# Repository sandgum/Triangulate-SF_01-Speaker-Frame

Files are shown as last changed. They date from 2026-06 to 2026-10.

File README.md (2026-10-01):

# Triangulate-SF_01-Speaker-Frame

*AI Use: No AI was used to generate any journal entries at all. AI was only used for electronics review and firmware help*

## Description
The SF_01 is a 24-inch digital picture frame running Android on a Raspberry Pi CM4. The Pi pushes an image to an off-the-shelf IPS monitor from LG through HDMI, and has wireless and USB peripheral support for touch displays, keyboards, and other HIDs.

The SF_01 also has a total 220W RMS speaker system on board, with 6 3.5-inch bass-mid woofers, and 4 0.75-inch tweeterspointing outwards from all four corners.

The frame itself is 3D-printed, with a large stand secured by VESA mount screws driven into the back of the monitor.

The frame has a separate circuit on board for audio playback, with an ESP32-S3 WROOM 2 module at its heart. It decodes a stereo Bluetooth A2DP stream, performs DSP calculations on board, and outputs two different I2S signals (one for the bass-mid woofers, the other for the tweeters).

After going through a DAC, the audio signals are routed through a custom analog multiplexer circuit to all 10 drivers, dynamically switching stereo output between drivers depending on the orientation of the frame.

The ESP32 appears in a device's Bluetooth list as a speaker, and it also runs a GATT server that is controlled by a Bluetooth LE connection via a custom iPhone app. Equalisers and crossovers can be set in the app.

### Woofer Layout

```
(1) ---------- (2)
(3)            (4)
(5) ---------- (6)
```

### Tweeter Layout

```
(1) ---------- (2)
 |              |
(3) ---------- (4)
```

**Landscape Orientation:**
* Left Channel:
* Woofers 1, 3, 5
* Tweeters 1, 3

* Right Channel:
* Woofers 2, 4, 6
* Tweeters 2, 4
  
**Portrait Orientation:**

* Left Channel:
* Woofers 5, 6
* Tweeters 3, 4

* Right Channel:
* Woofers 1, 2
* Tweeters 1, 2

* **Centre Channel: (Average of Right and Left):**
* Woofers 3, 4

## Enclosure Images
Render 1
Render 2
Render 3
Render 4
Render 5

## PCB Schematics

**Raspberry Pi Circuit**



**DAC and Analog Multiplexer Circuit**



**ESP32 WROVER E Circuit**



**Subwoofer Amplifiers**



**Tweeter Amplifiers**



**Environmental and Orientation Sensors**



**Power Circuitry**



## PCB Layout

**Top Layer**



**Inner Layer 1 (GND Plane)**



**Inner Layer 2**



**Bottom Layer**



**3D Model**







## Bill Of Materials

Quantities are **per board**. Prices are LCSC unit pricing at low volume and drop at quantity. Everything except the Compute Module, drivers and panel is sourced from LCSC.

### Board Components

| Designators | Qty | Value | Part Number | Manufacturer | Package | Description | Unit (USD) | Ext. (USD) | LCSC |
|---|---|---|---|---|---|---|---|---|---|
| C1, C4, C5, C7, C9, C14, C17, C19, C23, C26, C28, C31, C34, C37, C38, C39, C42, C43, C45, C47, C50, C53, C72, C74, C80, C81, C106, C109, C135, C138, C163, C166, C185, C186, C189 | 35 | 100nF | CL10B104KB8NNNC | Samsung Electro-Mechanics | 0603 | 100nF ±10% 50V X7R 0603 | 0.0142 | 0.50 | [C1591](https://www.lcsc.com/product-detail/C1591.html) |
| C49, C52, C61, C62, C67, C68, C79, C82, C92, C93, C94, C95, C107, C108, C119, C120, C121, C122, C136, C137, C149, C150, C151, C152, C164, C165, C177, C178, C179, C180 | 30 | 1nF | CL10C102JB8NNNC | Samsung Electro-Mechanics | 0603 | 1nF ±5% 50V C0G 0603 | 0.0076 | 0.23 | [C163508](https://www.lcsc.com/product-detail/C163508.html) |
| C2, C8, C12, C13, C40, C41, C44, C46, C48, C75, C76, C77, C102, C103, C105, C131, C132, C134, C157, C158, C159, C160, C162, C188, C190 | 25 | 1uF | CL10B105KA8NNNC | Samsung Electro-Mechanics | 0603 | 1uF ±10% 25V X7R 0603 | 0.0218 | 0.55 | [C29936](https://www.lcsc.com/product-detail/C29936.html) |
| C24, C63, C64, C69, C70, C96, C97, C98, C99, C123, C124, C125, C126, C153, C154, C155, C156, C181, C182, C183, C184 | 21 | 10nF | GRM1885C1H103JA01D | muRata | 0603 | 10nF ±5% 50V C0G 0603 | 0.0547 | 1.15 | [C85973](https://www.lcsc.com/product-detail/C85973.html) |
| C55, C56, C57, C58, C84, C85, C86, C87, C111, C112, C113, C114, C141, C142, C143, C144, C169, C170, C171, C172 | 20 | 220nF | CL10B224KB8NNNC | Samsung Electro-Mechanics | 0603 | 220nF ±10% 50V X7R 0603 | 0.0121 | 0.24 | [C64705](https://www.lcsc.com/product-detail/C64705.html) |
| C59, C60, C65, C66, C88, C89, C90, C91, C115, C116, C117, C118, C145, C146, C147, C148, C173, C174, C175, C176 | 20 | 680nF | CGA3E3X5R1H684KT0Y0N | TDK | 0603 | 680nF ±10% 50V X5R 0603 | 0.1052 | 2.10 | [C694504](https://www.lcsc.com/product-detail/C694504.html) |
| C10, C11, C35, C36, C71 | 5 | 2.2nF | CL10B222KB8NNNC | Samsung Electro-Mechanics | 0603 | 2.2nF ±10% 50V X7R 0603 | 0.0061 | 0.03 | [C16033](https://www.lcsc.com/product-detail/C16033.html) |
| C20, C21, C29, C30 | 4 | 2.2uF | CL10A225KA8NNNC | Samsung Electro-Mechanics | 0603 | 2.2uF ±10% 25V X5R 0603 | 0.0231 | 0.09 | [C57895](https://www.lcsc.com/product-detail/C57895.html) |
| C6 | 1 | 22uF | CL10A226MP8NUNE | Samsung Electro-Mechanics | 0603 | 22uF ±20% 10V X5R 0603 | 0.0825 | 0.08 | [C86295](https://www.lcsc.com/product-detail/C86295.html) |
| C187 | 1 | 6.8pF | CC0603BRNPO9BN6R8 | YAGEO | 0603 | 6.8pF 50V NP0 0603 | 0.0038 | 0.00 | [C519114](https://www.lcsc.com/product-detail/C519114.html) |
| C130 | 1 | 7.5nF | GRM1885C1H752JA01D | muRata | 0603 | 7.5nF ±5% 50V C0G 0603 | 0.0156 | 0.02 | [C907758](https://www.lcsc.com/product-detail/C907758.html) |
| C100, C101, C129 | 3 | 10uF/50V | GRM32ER71H106KA12L | muRata | 1210 | 10uF ±10% 50V X7R 1210 | 0.3758 | 1.13 | [C77102](https://www.lcsc.com/product-detail/C77102.html) |
| C191, C192 | 2 | 47uF | GRM32ER61C476KE15L | muRata | 1210 | 47uF ±10% 16V X5R 1210 | 0.4273 | 0.85 | [C77101](https://www.lcsc.com/product-detail/C77101.html) |
| C51, C54, C78, C83, C104, C110, C133, C139, C161, C167 | 10 | 220uF | RVT35V220M6X8 | JIERR | SMD,D6.3xL7.7mm | 220uF ±20% 35V aluminium electrolytic 105C | 0.1003 | 1.00 | [C47023115](https://www.lcsc.com/product-detail/C47023115.html) |
| C3 | 1 | 10uF | EEEFTH100UAR | Panasonic | SMD,D4xL5.8mm | 10uF ±20% 50V aluminium electrolytic 105C | 0.1811 | 0.18 | [C242129](https://www.lcsc.com/product-detail/C242129.html) |
| C15, C16, C18, C22, C25, C27, C32, C33 | 8 | 10uF | EEEFTH100UAR | Panasonic | SMD,D4xL5.8mm | 10uF ±20% 50V aluminium electrolytic 105C | 0.1811 | 1.45 | [C242129](https://www.lcsc.com/product-detail/C242129.html) |
| C73 | 1 | 22uF | EEEFN1E220R | Panasonic | SMD,D4xL5.8mm | 22uF ±20% 25V aluminium electrolytic 105C | 0.1796 | 0.18 | [C494818](https://www.lcsc.com/product-detail/C494818.html) |
| R16, R18, R20, R26, R27, R30, R35, R36, R39, R45, R46, R50, R55, R56, R60, R76 | 16 | 100K | FRC0603J104TS | FOJAN | 0603 | 100kOhm ±5% 100mW 0603 | 0.0019 | 0.03 | [C2907088](https://www.lcsc.com/product-detail/C2907088.html) |
| R4, R12, R67, R68, R69, R70, R71, R77 | 8 | 10K | CRCW060310K0FKEA | VISHAY | 0603 | 10kOhm ±1% 100mW 0603 | 0.0057 | 0.05 | [C844918](https://www.lcsc.com/product-detail/C844918.html) |
| R21, R22, R23, R24, R31, R32, R33, R34, R40, R41, R42, R43, R51, R52, R53, R54, R61, R62, R63, R64 | 20 | 3.3R | FRC0805J3R3TS | FOJAN | 0805 | 3.3Ohm ±5% 125mW 0805 | 0.0037 | 0.07 | [C2907317](https://www.lcsc.com/product-detail/C2907317.html) |
| R15 | 1 | 3.3R | FRC0603F3R30TS | FOJAN | 0603 | 3.3Ohm ±1% 100mW 0603 | 0.0025 | 0.00 | [C2930016](https://www.lcsc.com/product-detail/C2930016.html) |
| R25, R44, R49, R59 | 4 | 100R | FRC0603F1000TS | FOJAN | 0603 | 100Ohm ±1% 100mW 0603 | 0.0021 | 0.01 | [C2906981](https://www.lcsc.com/product-detail/C2906981.html) |
| R28, R37, R47, R57 | 4 | 47K | FRC0603F4702TS | FOJAN | 0603 | 47kOhm ±1% 100mW 0603 | 0.0023 | 0.01 | [C2907042](https://www.lcsc.com/product-detail/C2907042.html) |
| R29, R38, R48, R58 | 4 | 75K | FRC0603F7502TS | FOJAN | 0603 | 75kOhm ±1% 100mW 0603 | 0.0025 | 0.01 | [C2907067](https://www.lcsc.com/product-detail/C2907067.html) |
| R5, R6, R72, R73 | 4 | 1K | FRC0603F1001TS | FOJAN | 0603 | 1kOhm ±1% 100mW 0603 | 0.0014 | 0.01 | [C2907002](https://www.lcsc.com/product-detail/C2907002.html) |
| R1, R2 | 2 | 2.2K | FRC0603F2201TS | FOJAN | 0603 | 2.2kOhm ±1% 100mW 0603 | 0.0023 | 0.00 | [C2907005](https://www.lcsc.com/product-detail/C2907005.html) |
| R3, R65 | 2 | 5.1K | FRC0603F5101TS | FOJAN | 0603 | 5.1kOhm ±1% 100mW 0603 | 0.0023 | 0.00 | [C2907044](https://www.lcsc.com/product-detail/C2907044.html) |
| R7, R17 | 2 | 56K | 0603WAF5602T5E | UNI-ROYAL | 0603 | 56kOhm ±1% 100mW 0603 | 0.0081 | 0.02 | [C23206](https://www.lcsc.com/product-detail/C23206.html) |
| Q1 | 1 | BSS138 | BSS138 | Shikues | SOT-23 | N-channel logic-level MOSFET 50V 0.2A | 0.0191 | 0.02 | [C112239](https://www.lcsc.com/product-detail/C112239.html) |
| R19 | 1 | 20K | FRC0603F2002TS | FOJAN | 0603 | 20kOhm ±1% 100mW 0603 | 0.0020 | 0.00 | [C2907011](https://www.lcsc.com/product-detail/C2907011.html) |
| R8, R9, R10, R11 | 4 | 470R | FRC0603F4700TS | FOJAN | 0603 | 470Ohm ±1% 100mW 0603 | 0.0027 | 0.01 | [C2907041](https://www.lcsc.com/product-detail/C2907041.html) |
| R14, R78 | 2 | 220R | 0603WAF2200T5E | UNI-ROYAL | 0603 | 220Ohm ±1% 100mW 0603 | 0.0010 | 0.00 | [C22962](https://www.lcsc.com/product-detail/C22962.html) |
| R66 | 1 | 205K | FRC0603F2053TS | FOJAN | 0603 | 205kOhm ±1% 100mW 0603 | 0.0008 | 0.00 | [C5126104](https://www.lcsc.com/product-detail/C5126104.html) |
| R75 | 1 | 60.4K | 0603WAF6042T5E | UNI-ROYAL | 0603 | 60.4kOhm ±1% 100mW 0603 | 0.0009 | 0.00 | [C23089](https://www.lcsc.com/product-detail/C23089.html) |
| R74 | 1 | 11.5K | FRC0603F1152TS | FOJAN | 0603 | 11.5kOhm ±1% 100mW 0603 | 0.0009 | 0.00 | [C2930057](https://www.lcsc.com/product-detail/C2930057.html) |
| R13 | 1 | 10.7K | FRC0603F1072TS | FOJAN | 0603 | 10.7kOhm ±1% 100mW 0603 | 0.0025 | 0.00 | [C5153968](https://www.lcsc.com/product-detail/C5153968.html) |
| L1, L2, L3, L4, L5, L6, L7, L8, L9, L10, L11, L12 | 12 | 10uH/10A | SMDRH104R-100MT | cjiang | SMD,10.4x10.3mm | 10uH ±20% 3.8A rated / 5.6A sat / 35mOhm | 0.1916 | 2.30 | [C9935](https://www.lcsc.com/product-detail/C9935.html) |
| L13, L14, L15, L16, L17, L18, L19, L20 | 8 | 10uH/3A | FHD4020S-100MT | cjiang | SMD,4x4mm | 10uH ±20% 2.35A rated / 3.5A sat / 190mOhm | 0.1102 | 0.88 | [C602032](https://www.lcsc.com/product-detail/C602032.html) |
| L21 | 1 | 6.8uH/6.6A | AAPS0650M6R8F | Coilank | SMD,6.6x6.4mm | 6.8uH ±20% 6.6A rated / 7A sat / 25.4mOhm molded | 0.9665 | 0.97 | [C49261484](https://www.lcsc.com/product-detail/C49261484.html) |
| U4 | 1 | TPS54540DDAR | TPS54540DDAR | Texas Instruments | SOIC-8-EP | 42V 5A step-down converter | 1.4638 | 1.46 | [C95286](https://www.lcsc.com/product-detail/C95286.html) |
| CR2 | 1 | STPS30H100DJF-TR | STPS30H100DJF-TR | ST | PowerFLAT5x6-8 | 100V 30A Schottky | 1.3985 | 1.40 | [C2969851](https://www.lcsc.com/product-detail/C2969851.html) |
| U10 | 1 | LP5907MFX-4.5 | LP5907MFX-4.5/NOPB | Texas Instruments | SOT-23-5 | 4.5V LDO | 0.5581 | 0.56 | [C529554](https://www.lcsc.com/product-detail/C529554.html) |
| U11 | 1 | LP5907MFX-3.3 | LP5907MFX-3.3 | Texas Instruments | SOT-23-5 | 3.3V LDO | 0.1343 | 0.13 | [C23380874](https://www.lcsc.com/product-detail/C23380874.html) |
| U17, U18, U19 | 3 | TPA3116D2DAD | TPA3116D2DADR | Texas Instruments | HTSSOP-32-6.1mm | 2x50W@4ohm Class D amplifier | 1.0619 | 3.19 | [C50144](https://www.lcsc.com/product-detail/C50144.html) |
| U20, U21 | 2 | TPA3130D2DAPR | TPA3130D2DAPR | Texas Instruments | HTSSOP-32-EP-6.1mm | 2x15W@8ohm Class D amplifier | 0.6314 | 1.26 | [C95206](https://www.lcsc.com/product-detail/C95206.html) |
| U12, U13, U15, U16, U24, U25, U26 | 7 | TS5A3159AYZPR | TS5A3159AYZPR | Texas Instruments | WCSP-6(1.4x0.9) | SPDT analog switch | 0.3971 | 2.78 | [C2651909](https://www.lcsc.com/product-detail/C2651909.html) |
| U5, U14 | 2 | PCM5102A | PCM5102APWR | Texas Instruments | TSSOP-20 | I2S stereo DAC | 1.3577 | 2.72 | [C107671](https://www.lcsc.com/product-detail/C107671.html) |
| U27 | 1 | TPS2041B | TPS2041BDBVR | Texas Instruments | SOT-23-5 | 500mA current-limited power switch | 0.3173 | 0.32 | [C51386](https://www.lcsc.com/product-detail/C51386.html) |
| U6 | 1 | RT9742SNGV | RT9742SNGV | RICHTEK | SOT-23-3 | 500mA high-side switch | 0.4386 | 0.44 | [C3235509](https://www.lcsc.com/product-detail/C3235509.html) |
| U9 | 1 | 74LVC1G07 | SN74LVC1G07DBVR | Texas Instruments | SOT-23-5 | Open-drain buffer 1.65-5.5V | 0.1109 | 0.11 | [C7829](https://www.lcsc.com/product-detail/C7829.html) |
| TP1–TP21, TP23–TP25 | 24 | TestPoint | — | — | 3.0x3.0mm pad / D2.5mm pad / D2.0mm plated hole | Bare copper - nothing to buy. 3 top, 4 plated through-hole, 17 on the bottom layer | 0.0000 | 0.00 | — |
| U28 | 1 | ESP32-WROVER-E-N16R8 | ESP32-WROVER-E-N16R8 | ESPRESSIF | SMD,31.4x18mm | WiFi/BT module 16MB flash 8MB PSRAM | 5.7127 | 5.71 | [C529589](https://www.lcsc.com/product-detail/C529589.html) |
| U22 | 1 | MPU-6050 | MPU-6050 | TDK InvenSense | QFN-24-EP(4x4) | 6-axis IMU | 6.3857 | 6.39 | [C24112](https://www.lcsc.com/product-detail/C24112.html) |
| U23 | 1 | BME680 | BME680 | Bosch | LGA-8 | Environmental sensor | 8.0629 | 8.06 | [C125972](https://www.lcsc.com/product-detail/C125972.html) |
| U2, U3, U7 | 3 | TPD4E02B04DQA | TPD4E02B04DQAR | Texas Instruments | USON-10(1x2.5) | 4-channel ESD array | 0.0996 | 0.30 | [C106794](https://www.lcsc.com/product-detail/C106794.html) |
| CR1 | 1 | SP3010-04UTG | SP3010-04UTG | Littelfuse | UFDFN-10(1x2.5) | 4-channel TVS array | 0.2544 | 0.25 | [C126837](https://www.lcsc.com/product-detail/C126837.html) |
| D1 | 1 | SMAJ26A | SMAJ26A | GOODWORK | DO-214AC(SMA) | 26V unidirectional TVS 400W Vbr 28.9V Vc 42.1V@9.5A | 0.0333 | 0.03 | [C2848697](https://www.lcsc.com/product-detail/C2848697.html) |
| D2, D5, D6, D7 | 4 | WS2812B | WS2812B-V6 | Worldsemi | SMD5050-4P | Addressable RGB LED | 0.1009 | 0.40 | [C52917433](https://www.lcsc.com/product-detail/C52917433.html) |
| D3, D4 | 2 | LED | YLED0603B | YONGYUTAI | 0603 | Blue LED 2.6-3.2V | 0.0058 | 0.01 | [C19171394](https://www.lcsc.com/product-detail/C19171394.html) |
| J1 | 1 | SS-53200-001 | HDMI 19PIN 043 | SHOU HAN | SMD | HDMI-A receptacle right angle | 0.1365 | 0.14 | [C2858275](https://www.lcsc.com/product-detail/C2858275.html) |
| J5, J6, J7, J8, J9, J10, J11, J12, J13, J14 | 10 | Speaker out | S2B-XH-A(LF)(SN) | JST | TH Right Angle P=2.5mm | 2-position 2.5mm header 3A | 0.0615 | 0.62 | [C157931](https://www.lcsc.com/product-detail/C157931.html) |
| J15 | 1 | USB_C_Receptacle_USB2.0_16P | TYPE-C 16PIN 2MD(073) | SHOU HAN | SMD | USB-C receptacle 16P | 0.0707 | 0.07 | [C2765186](https://www.lcsc.com/product-detail/C2765186.html) |
| J2 | 1 | Barrel_Jack | RAPC10U | Switchcraft | - | Power barrel jack 1.93/5.75mm | 17.0122 | 17.01 | [C3095802](https://www.lcsc.com/product-detail/C3095802.html) |
| J3 | 1 | UART | PZ254V-11-04P | XFCN | TH P=2.54mm | 4-position 2.54mm header | 0.0254 | 0.03 | [C2691448](https://www.lcsc.com/product-detail/C2691448.html) |
| SW1 | 1 | POWER | KSC931JLFS | C&K | SMD-4P,6.2x6.2mm | Tactile switch SPST IP67 J-lead | 2.0503 | 2.05 | [C221769](https://www.lcsc.com/product-detail/C221769.html) |
| SW2, SW3, SW4 | 3 | Tactile | KMR211GLFS | C&K | SMD | Tactile switch SPST-NO | 0.6377 | 1.91 | [C221675](https://www.lcsc.com/product-detail/C221675.html) |
| SW6 | 1 | SW_DPDT_x2 | JS202011JAQN | C&K | SMD | Slide switch DPDT 300mA@6V, right-angle | 1.2032 | 1.20 | [C221664](https://www.lcsc.com/product-detail/C221664.html) |
| U1 | 1 | CM4102008 | CM4102008 | Raspberry Pi | - | Compute Module 4 | 124.9100 | 124.91 | — |

**Board subtotal: $197.63 per board**

### Off-Board / Mechanical

| Qty | Item | Part Number | Manufacturer | Description | Unit (USD) | Ext. (USD) |
|---|---|---|---|---|---|---|
| 6 | Woofer | PLS-P830985 | Peerless by Tymphany | 3.95ohm full-range 30W driver | 18.74 | 112.45 |
| 4 | Tweeter | ND16FA-6 | Dayton Audio | Neodymium dome tweeter | 12.47 | 49.88 |
| 1 | Display | 24U411A-B | LG | 23.8in IPS FHD 120Hz panel | 74.53 | 74.53 |

**Off-board subtotal: $236.86**

### Items Needing Attention

| Designators | Status | Note |
|---|---|---|
| C100, C101, C129 | CHANGED + FOOTPRINT | Was 10uF/25V 0603 on the 24V rail. 10uF/50V does not exist in 0603 - the footprint has to go to 1210 |
| C191, C192 | CHANGED + FOOTPRINT | TPS54540 output bulk. 47uF does not exist in 0603 or 0805 at >=16V - footprint has to go to 1210 |
| L21 | CHANGED - NO PCB CHANGE | Now AAPS0650M6R8F (Coilank), 6.6A rated / 7A sat / 25.4mOhm. Replaced VLS6045EX-6R8M which saturated at full load (4.7A sat vs a 4.72A peak). 48% saturation margin now, and half the DCR. Body 6.6x6.4mm fits the existing 7.50x6.80mm courtyard so the land pattern is unchanged |
| CR2, R8-R11, R13, SW1, SW6 | CHANGED - RESTOCK | All five originals hit 0 stock on LCSC. CR2 -> STPS30H100DJF-TR (C2969851, same PowerFLAT 5x6 family, 100V, lowest Vf of the in-stock options). R8-R11 -> FRC0603F4700TS (C2907041). R13 -> FRC0603F1072TS (C5153968, only 1k in stock; plain 10K works as a fallback). SW1 -> KSC931JLFS (C221769, only 18 in stock). SW6 -> JS202011JAQN (C221664) which is RIGHT-ANGLE where the original was VERTICAL, so verify the land pattern |
| U8 | DELETED | U8 buffered CM4 RUN_PG into the GLOBAL_EN button, forming a feedback loop that repeatedly power-cycled the module. Removed. SW1 now goes straight to GPIO3/GND as a soft power button (`dtoverlay=gpio-shutdown`), with R77 as pull-up and C74 as debounce |
| U9 | CHANGED - FOOTPRINT | Footprint is SOT-23-5, same as U10/U11/U27; symbol pin numbering unchanged (1=NC 2=A 3=GND 4=Y 5=VCC). MUST stay LVC. Budget alt C7394020 (UMW) |
| R77, R78, C74, TP1, TP2 | NEW | Power-button circuit. R77 10K pulls GPIO3 to 3V3, C74 100nF debounces it, R78 220R feeds TP1 for CM4 reset (220R is the value the CM4 datasheet specifies), TP2 exposes GLOBAL_EN for a hard force-off |
| D2, D5, D6, D7 | KEEP - RAIL ISSUE | Datasheet minimum VDD is 3.5V and these sit on the 3.3V rail. See review B5 |
| J1 | VERIFY | Footprint is drawn for the Stewart SS-53200-001 but the sourced part is SHOU HAN - confirm the land patterns match before ordering |
| J5, J6, J7, J8, J9, J10, J11, J12, J13, J14 | KEEP - MARGINAL | Rated 3A but a 50W/4ohm woofer channel draws 3.5A RMS. See review H9 |
| J2 | KEEP - VERIFY RATING | Confirm its current rating against the ~8A this board can draw at full output |
| U1 | NOT ON LCSC | Source from an approved Raspberry Pi reseller. Schematic says CM4102008 but the old BOM said CM4102016 - pick one |

## Total: $434.49 USD per complete unit

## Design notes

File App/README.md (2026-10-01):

# SF01Control — iOS EQ remote

SwiftUI app that tunes the SF_01 speaker's DSP over BLE while music streams to
it over A2DP.

* `SF01Protocol.swift` — wire format, mirroring `Firmware/.../main/ble_ctl.h`
* `SpeakerController.swift` — CoreBluetooth client, auto-reconnect, write coalescing
* `ContentView.swift` / `BandEditor.swift` — the UI

## Build and install

```bash
export DEVELOPER_DIR=/Applications/Xcode-beta.app/Contents/Developer
xcodebuild -project App/SF01Control.xcodeproj -scheme SF01Control \
  -configuration Debug -destination 'id=<device-udid>' \
  -allowProvisioningUpdates build
xcrun devicectl device install app --device <device-udid> <path-to>/SF01Control.app
```

Signing is automatic against team `LAFKSHQ45W`.

**First install needs a one-time trust step on the phone:** Settings → General →
VPN & Device Management → Developer App → Trust. On a free Apple developer
account the provisioning profile also expires after 7 days, after which the app
must be rebuilt and reinstalled.

## Equaliser screen

`EQScreen` shows a log-frequency response plot with a draggable handle per
active band — sideways for frequency, up and down for gain — over a scrollable
row of gain knobs and a Freq/Q/Gain trio for the selected band.

`EQMath.swift` re-implements the same RBJ cookbook filters the firmware runs in
`dsp.c`, so the drawn curve *is* the response you hear rather than an
approximation of it. The plot also overlays the Linkwitz-Riley crossover
branches as dashed lines, so EQ moves can be read against where the two ways
actually split.

Knobs track a **vertical drag** rather than true circular motion: on a phone
your finger covers the knob, and chasing an angle under your own thumb is
miserable. Frequency knobs ride a log scale so they feel even across the band.

## Design notes

**Write coalescing.** A slider drag emits values far faster than BLE should
carry them, and the radio is shared with the audio link. Commands are coalesced
per control and flushed on a 50 ms tick, so a drag costs at most 20 writes per
second and the final value always lands.

**Echo guard.** The speaker notifies every change back. During a drag those
echoes arrive a beat late and would yank the knob backwards, so remote updates
are ignored for 500 ms after a local write. Changes made elsewhere — the UART
shell, AVRCP volume, the mute sequencer — still appear as soon as the user lets
go of the control.

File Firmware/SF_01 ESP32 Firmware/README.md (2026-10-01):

# SF_01 ESP32 Audio Firmware

Bluetooth A2DP sink → EQ → Linkwitz-Riley crossover → two I²S buses → two PCM5102A DACs.

**Target: ESP32-WROVER-E-N16R8** (U28 on the SF_01 Compute Board).
A2DP is a Bluetooth *Classic* profile, so this cannot run on an ESP32-S3 —
the S3 is BLE-only. (The top-level project README still describes the audio
board as an "ESP32-S3 WROOM 2"; the schematic and BOM say WROVER-E, which is
the part that can actually do this.)

Built and verified against **ESP-IDF v5.5.1**.

## Signal chain

```
A2DP (SBC, 44.1 kHz)
   └─► ring buffer ─► render task
          ├─ volume (AVRCP absolute volume)
          ├─ EQ: up to 8 peaking / shelf biquads
          └─ Linkwitz-Riley 4th order split @ 2.8 kHz
               ├─ low  ─► woofer trim  ─► I2S0 ─► U14 ─► TPA3116 ×3 ─► 6 × 3.5" mid-bass
               └─ high ─► tweeter trim ─► I2S1 ─► U5  ─► TPA3130 ×2 ─► 4 × 0.75" tweeters
```

LR4 is two cascaded Butterworth sections per branch. Low and high sum to an
all-pass, so both ways stay in phase through the crossover and **no polarity
flip is needed** — unlike LR2. An `invert` command is provided anyway, because
real drivers in a real baffle do not always agree with the theory.

Both I²S units are clocked from the **APLL** so they stay frequency-locked.
Left on the default divided PLL they drift apart, which smears the
woofer/tweeter phase relationship exactly where the crossover needs it to be
stable. The DMA chains are preloaded with silence and enabled back to back so
the two DACs start within well under one sample of each other.

## Pin map

Taken from the KiCad netlist of `PCB V1.1/SF_01 Compute Board`, module U28.

| Signal | GPIO | U28 pin | Test point | Goes to |
|---|---|---|---|---|
| `WFR_BCK` | 25 | 10 | TP11 | U14 BCK |
| `WFR_LRCK` | 19 | 31 | TP18 | U14 LRCK |
| `WFR_DIN` | 23 | 37 | TP15 | U14 DIN |
| `WFR_SCK` | 26 | 11 | TP12 | U14 SCK — **held low** |
| `TWT_BCK` | 15 | 23 | TP8 | U5 BCK |
| `TWT_LRCK` | 13 | 16 | TP9 | U5 LRCK |
| `TWT_DIN` | 14 | 13 | TP13 | U5 DIN |
| `TWT_SCK` | 18 | 30 | TP16 | U5 SCK — **held low** |
| `DAC_EN` | 4 | 26 | TP17 | XSMT on **both** DACs |
| `DRIVER_MUTE` | 27 | 12 | TP14 | MUTE on all five amps |

### Why SCK is driven low

The PCM5102A's SCK (pin 12) is wired to the ESP32 on this board, but the
classic ESP32 can only emit an I²S master clock on GPIO 0/1/3 — neither 26 nor
18 qualifies. Firmware therefore holds both pins **low**, which is TI's
documented "SCK to GND" mode: the DAC runs its internal PLL off BCK
(PCM5102A datasheet §9.4.1). A *floating* SCK never locks, so this is not
optional — it is the firmware half of a hardware compromise.

## Power-up sequencing

Every delay below comes from a datasheet, not from taste.

**At reset, before firmware runs, the amplifiers are live and un-muted.**
`DRIVER_MUTE` is held low by the five 100 kΩ pull-downs R20/R27/R36/R46/R56,
GPIO27 is high-Z out of reset, and the amps' SDZ pins are strapped to FAULTZ —
so they enable themselves the moment PVCC rises, while the DACs' XSMT pin is
still floating. `audio_out_safe_state()` is therefore the **first** call in
`app_main`, before NVS or Bluetooth, to close that window as early as software
can. The ~200 ms ROM-bootloader window ahead of it cannot be closed in
firmware — see *Hardware notes*.

**Start-up** (`audio_out_unmute`):

| Step | Wait | Source |
|---|---|---|
| Amps muted, DACs muted, SCK low | — | first thing in `app_main` |
| I²S enabled, silence flowing | 20 ms | PCM5102A resyncs if LRCK:BCK is invalid >4 LRCK periods (§9.3.2); 20 ms ≈ 880 periods |
| `XSMT` high → soft un-mute | 104 samples (2.4 ms @ 44.1 k) + 10 ms | 1 dB/sample ramp, §9.3.3 |
| `DRIVER_MUTE` low → amps live | — | TPA31xx MUTE, SLOS708G |

**Shutdown** is the exact reverse — amps go Hi-Z first (~2 µs), *then* the DAC
ramps down, so the mute ramp is never audible.

`XSMT` must be driven by a plain GPIO edge: the part needs t_r/t_f < 20 ns
(§8.7), and a 1→0 edge slower than 6 ms puts it into external-undervoltage
mode instead of digital mute. **Do not add an RC to that net.**

Clocks keep running with silence whenever no stream is playing, so the DAC
PLLs stay locked and resume is click-free.

## Bring-up wiring (devboard)

Power the devboard from **USB only**. Never connect devboard `VIN` or `3V3` to
any PCB rail — the PCB makes its own, and tying them together back-feeds
`3V3_A` (3.9 V abs max on the DACs) and pushes current backwards through
U11's body diode into `SYS_5V` and the CM4.

Connect **GND plus the ten signals** in the table above, devboard GPIO → PCB
test point. GND is not optional; without it the I²S lines have no reference.

## Build and flash

```bash
. ~/esp/esp-idf/export.sh
idf.py -p /dev/cu.usbserial-10 flash monitor
```

## Tuning

The UART console (115200) accepts live commands; `save` persists to NVS.

It runs in **dumb-terminal mode** — no line editing, history or tab completion,
and it behaves identically under `idf.py monitor`, `screen` and a plain script.
esp_console normally probes for VT100 support by emitting `ESC[5n` and treating
any 4 bytes received within 500 ms as the reply, so a script that starts talking
early — or a user typing during boot — convinces it a smart terminal is attached
and it then floods the UART with escape sequences nothing will answer.
`shell.c` calls `linenoiseSetDumbMode(1)` to take the predictable path.

| Command | Meaning |
|---|---|
| `status` | Show crossover, EQ, trims, output state |
| `xo <hz>` | Crossover frequency |
| `eq <band> <off\|peak\|lowshelf\|highshelf> <freq> <Q> <dB>` | Set one of 8 bands |
| `gain <wfr\|twt\|master> <dB>` | Per-way and master trim |
| `delay <samples>` | Time-align the tweeter |
| `invert <0\|1>` | Tweeter polarity |
| `vol <0-127>` | Volume (also driven by AVRCP) |
| `save` / `load` / `defaults` | NVS persistence |
| `mute` / `unmute` | Force output state |

Defaults: 2.8 kHz crossover, tweeter −3 dB, master −3 dB for EQ headroom.
These are a safe starting point, not a measured tuning.

A cubic soft-clipper sits at the output so EQ boost degrades gracefully
instead of hard-clipping.

## BLE control service

The controller runs in **dual mode**: BR/EDR carries the A2DP audio, BLE carries
an EQ/crossover control service for the iOS app in `App/SF01Control`. The
coexistence manager shares the one radio; control traffic is small and
infrequent, which is the case that coexists cleanly with a streaming link.

| | UUID |
|---|---|
| Service | `5F010000-A1B2-4C3D-8E4F-5F0100000001` |
| `CONFIG` — read, notify | `5F010001-A1B2-4C3D-8E4F-5F0100000001` |
| `COMMAND` — write | `5F010002-A1B2-4C3D-8E4F-5F0100000001` |

`CONFIG` is a 78-byte little-endian snapshot of the whole DSP state, re-published
on any change. A publisher task polls the rendered blob every 200 ms rather than
hooking each writer, so changes made from the UART shell or by AVRCP volume show
up on the phone too. `COMMAND` takes short opcode frames, at most 9 bytes, so
they fit even at the 23-byte default ATT MTU. Both formats are specified in
`main/ble_ctl.h`, and `App/SF01Control/SF01Protocol.swift` mirrors them — change
one, change the other. The version byte is checked on every read, so a mismatch
surfaces as an explicit error rather than as odd values.

Adding BLE grew the binary from 821 KB to 1.07 MB; the 2 MB partition still has
49 % free.

## UI tones

Three synthesised tones: a rising C-E-G-C arpeggio at startup, a rising
two-note on Bluetooth connect, and its inversion on disconnect.

They are **generated, not stored** — no WAV assets, no flash budget (the whole
feature costs about 1.6 KB), and they follow whatever sample rate A2DP
negotiated without resampling.

Rendering happens **inside the audio render task, in place of the stream**,
rather than being pushed through the ring buffer. That avoids extra buffering
and any pacing logic — the I2S clock paces it — and the tone still passes
through the normal DSP chain, so the crossover splits it properly across the
woofers and tweeters instead of landing on one way only. Stream audio arriving
during a tone is dropped rather than queued, so playback resumes live instead
of a few hundred ms behind.

`chime.c` uses a 1024-point interpolated sine table rather than `sinf()` per
sample: four overlapping voices with three harmonics each is twelve sines per
frame, and calling `sinf()` that often at 44.1 kHz would take a serious bite
out of the CPU the DSP needs. An underrun during the startup tone is exactly
the wrong first impression.

Tones need the analog chain live, which at boot or between streams it is not,
so `do_chime()` un-mutes with the usual sequence, plays, waits for the tail to
clear the DMA chain, then **restores the previous mute state** — a tone never
leaves the amplifiers hot. Measured windows, amps live:

| tone | duration |
|---|---|
| startup | 926 ms |
| connect | 518 ms |
| disconnect | 528 ms |

Play any of them from the shell:

```
chime                 startup tone
chime connect
chime disconnect
```

Because they run through the DSP, tones follow the master volume and EQ. At
volume 0 they are silent, which is the intended behaviour.

## LED bass visualiser

The devboard's onboard LED pulses with the low bass. `dsp_bass_level()` taps
the woofer branch **after its gain**, so the LED follows what the drivers
actually receive — volume and EQ included — then band-limits to ~120 Hz with a
24 dB/oct filter. Tapping the woofer branch raw would not work: it runs all the
way up to the crossover, so the LED would just track overall loudness.

The envelope uses a 4 ms attack and 180 ms release, so it snaps to a kick and
decays smoothly instead of flickering at the waveform rate. `led_viz.c` drives
the pin with **PWM, not on/off**, and raises the level to the power 2.2 because
perceived brightness goes roughly as duty^(1/2.2) — without that the pulse
blows out to full almost immediately.

Bass rarely approaches full scale after gain scaling, and how close it gets
depends on volume, so the task normalises against a slowly decaying peak
(~5 s) with a floor. The LED uses its whole range at any listening level
without amplifying near-silence into flicker. When the output is muted it
falls back to a dim 4-second breath.

Default pin is **GPIO2**, where essentially every generic ESP32 devkit puts its
user LED, and which is unconnected on the SF_01 board (U28 pin 24) so driving
it there is harmless. GPIO2 is a strapping pin, but this initialises long after
boot, by which point it is an ordinary output.

If your board's LED is elsewhere, find it without a rebuild:

```
led               show the current pin
led test 100      hold it at full brightness
led 5 al          move to GPIO5, active low
led auto          resume the visualiser
```

The real SF_01 board has no plain LED — it has a WS2812B on `NEOPIXEL_DIN`
(GPIO33, via R14). Driving that is not implemented.

## Hardware notes

**Mute is not fail-safe at boot.** The 100 kΩ *series* resistors
(R30/R39/R50/R60/R76) are correct and required — TI note (2) on the SLOS708G
abs-max table calls for exactly 100 kΩ when the driver exceeds the 10 V/ms
slew limit on MUTE/SDZ, which any GPIO does. The issue is the five 100 kΩ
*pull-downs* on the `DRIVER_MUTE` node: they make "un-muted" the default
state during reset and the ROM bootloader window.

To make the amps mute-by-default in hardware, replace one of the pull-downs
with a pull-**up** to 3V3 — or remove several and fit a ~10 kΩ pull-up. An
internal ESP32 pull-up cannot do this: at ~45 kΩ against the existing 20 kΩ
pull-down network it only reaches ≈1.0 V, below the 2 V V_IH.

**PSRAM is deliberately disabled.** The WROVER-E-N16R8 has 8 MB, nothing here
needs it, and leaving it off keeps this binary bootable on a plain WROOM-32
devboard for bring-up.

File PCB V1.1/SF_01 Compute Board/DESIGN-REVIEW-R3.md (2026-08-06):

# SF_01 Compute Board — Pre-Fabrication Review (Revision 3)

**Date:** 2026-08-05 · **Supersedes:** `DESIGN-REVIEW.md` (Rev 2, 2026-08-03)
**Board:** KiCad 10, 6 hierarchical sheets, 4-layer, 128 × 128 mm, 341 components / 343 footprints

**What's new in this revision:** Rev 2 could not run KiCad's native ERC and DRC (`kicad-cli` was not on PATH). It is available at `/Applications/KiCad/KiCad.app/Contents/MacOS/kicad-cli`, so **both ran for the first time**. That closes the single largest gap in the previous review.

---

## Verdict

**One real electrical defect, one ordering blocker, three cheap cleanups.** Nothing in the layout will stop the board working.

The headline: most of what DRC screams about is not real. Of 370 violations, **6** are genuine geometry and **1** is an actual electrical derating error found in the schematic, not the layout.

---

## Corrections to my own findings during this review

I raised two "critical shorts" during the session and then disproved both. Recording them so they don't get re-raised later.

| Claim | Verdict |
|---|---|
| "SW-node vias are shorted to the GND plane in the shipped gerbers" | **Withdrawn.** The stale fill was real *in the `.kicad_pcb`*, but the Fabrication Toolkit has `AUTO FILL: true` and refills at export. I checked the shipped `In1_Cu`/`In2_Cu` gerbers directly: a proper clearance ring exists at **0.601–0.606 mm** radius around each SW via (0.4 via radius + 0.2 clearance). The artwork was correct. |
| "RUN_PG is shorted to the GND plane" | **Withdrawn.** The three flagged segments were created in the 18:35 reroute, *after* the last zone fill — they do not exist in the 18:17 backup that produced the gerbers. A refill clears them. KiCad showing nothing wrong on screen was correct. |

The lesson worth keeping: **a zone-clearance error reading exactly `0.0000 mm` is almost always a stale fill, not a short.** Refill before believing it.

The one genuine short — a VSYS track overlapping a GND via by 0.106 mm at (185.8, 143.8) — was found and removed during this session.

---

## Blockers

### 1. C100, C101, C129 are 25 V parts on the 24 V rail — REAL

The schematic value is `10uF/25V`. All three sit on **VSYS**, which is the 24 V input rail.

This is the leftover half of a fix that was only half-applied. Your own README already flags it:

> "Was 10uF/25V 0603 on the 24V rail. 10uF/50V does not exist in 0603 — the footprint has to go to 1210"

The **footprint** moved to 1210. The **value string never did.** Consequences:

- **No derating margin.** 24 V nominal on a 25 V part is 96 % of rating. Standard practice is 2×.
- **Transients exceed the rating outright.** D1 is an SMAJ26A: V_br 28.9 V, V_c 42.1 V. Anything the TVS lets through is above 25 V by design.
- **DC bias collapse.** A 25 V X7R 1210 at 24 V typically loses 60–80 % of its rated capacitance. You are not getting 10 µF; you may be getting 2–4 µF.

**The parts you actually costed are correct** — `GRM32ER71H106KA12L`, 10 µF **50 V** X7R 1210 (LCSC C77102). Only the schematic string is stale, and `production/SF_01_Compute_Board_bom.csv` currently exports `10uF/25V`.

**Fix:** change the value on C100/C101/C129 to `10uF/50V` before regenerating the BOM.

### 2. Production BOM has no LCSC part numbers

Every row of `production/SF_01_Compute_Board_bom.csv` has an **empty `LCSC Part #` column**:

```
Designator,Footprint,Quantity,Value,LCSC Part #
"C1, C106, ... C9",0603,34,100nF,
"C10, C11, C35, C36, C71",0603,5,2.2nF,
```

Assembly cannot be sourced from this file. Bare-board fab is unaffected.

The data exists — `BoM.csv` at the repo root has verified LCSC numbers for all 341 designators. It just isn't in the symbol properties, which is also what trips the `SS-001` gate (MPN coverage 1/77 unique parts).

**Fix:** write the LCSC numbers into the schematic symbol properties, or hand-merge them into the production CSV before uploading.

---

## Real but minor — cheap to fix

### 3. U8 pad 1 clearance — 0.123 mm

A GND track passes **0.123 mm** from U8 pad 1. Two DRC errors, at (188.56, 144.35).

This one is genuine geometry, not fill-dependent. It is below your 0.2 mm rule *and* below the 0.127 mm minimum spacing your DFM tier claims — so it may draw a fab query.

Electrical risk is low: U8 pad 1 is the **NC** pin on the SN74LVC1G07 (1=NC, 2=A, 3=GND, 4=Y, 5=VCC). Even a bridge does nothing. Treat as yield hygiene.

### 4. Duplicate co-located vias

Two GND vias occupy the exact same coordinate, **(133.7, 134.6)**. The drill file will contain two hits at one location. Most fabs handle it; some flag it. Delete one.

### 5. The mux footprints carry 42 phantom pads — this is why DRC is unusable

Each of the seven `TS5A3159A` footprints (U12, U13, U15, U16, U24, U25, U26) contains **12 pads where it should contain 6**:

```
pad ''   at (-0.25,-0.5)  <no net>      pad 'A1' at (-0.25,-0.5)  TWEETER_1
pad ''   at (-0.25, 0  )  <no net>      pad 'B1' at (-0.25, 0  )  GND
pad ''   at (-0.25, 0.5)  <no net>      pad 'C1' at (-0.25, 0.5)  TWEETER_4
...                                      ... (etc.)
```

Six unnamed, netless duplicates sit exactly on top of the six real balls — same position, same 0.265 mm size, same `F.Cu`/`F.Mask` layers.

**The artwork is unaffected.** Identical geometry drawn twice produces identical copper and identical mask. Your schematic is wired correctly and every real ball carries the right net — you were right about that.

**But they cost you your DRC.** They generate:

| Error class | Total | Phantom (mux) | Real |
|---|---|---|---|
| `solder_mask_bridge` | 101 | 101 | 0 |
| `shorting_items` | 57 | 57 | 0 |
| `clearance` | 53 | 48 | 5 |

**~206 of 370 violations are noise from this one defect.** A real short hiding in that list would be invisible — which is exactly what happened with the VSYS/GND via earlier today.

**Fix:** delete the six unnamed pads from the footprint (or re-import a clean `Texas_DSBGA-6_0.9x1.4mm_Layout2x3_P0.5mm`), then re-run DRC and read it properly.

---

## Verified correct — checked, no action

**Schematic ↔ PCB cross-reference is clean.** I compared connectivity *partitions* (name-independent — comparing net names alone produces 356 false mismatches because the analyzer calls anonymous nets `__unnamed_N` while KiCad calls them `Net-(U14-CAPP)`). Across 1283 pins the only differences are:

- **C40 / C41 pads swapped** vs the schematic. Both are 1 µF 0603 ceramics — non-polarized, electrically identical either way. Cosmetic desync only.
- **U20 / U21 pad 33** has no schematic pin. Expected: it's the thermal pad.

Everything else maps exactly.

**Amplifier land pattern verified.** U17–U21 on `SOP65P810X115-32N`: 16 pads per side, 0.65 mm row pitch, 7.44 mm lead span, 1.57 × 0.41 mm pads, correct counter-clockwise numbering (1–16 down the left, 17–32 up the right). Textbook HTSSOP-32.

**U20/U21 thermal pad present and grounded** — 5.372 × 10.600 mm, pad 33 on GND, 0.249 mm clear of the signal pads. Note the footprint is *named* `TPA3116D2DAD` (DAD) but carries the extra pad, so it is functioning as a DAP land pattern. Worth confirming pad 33's dimensions against the DAP land pattern in SLOS708G §11 if you want certainty — I could not text-extract that page.

**C119–C122 are correctly grounded.** The kicad-happy analyzer reported their centre node floating; it is wrong. There is a GND symbol at (220.98, 43.18) on `audioCircuit.kicad_sch`, sitting exactly at the midpoint between C119 (x=213.36) and C120 (x=227.33). KiCad's own parity check agrees. False positive.

**ERC's 131 `pin_not_connected` are not defects** — 113 are unused CM4 GPIOs, 7 ESP32, 3 MPU-6050. Add no-connect flags if you want a clean ERC; nothing is broken.

---

## Open items carried forward from Rev 2

Unchanged and still worth your attention. None is a blocker.

| Item | Status |
|---|---|
| **U4 EN floating** — no programmable UVLO on the buck | Still open. ERC confirms (`U4` pin_not_connected ×1). Still the single most worthwhile change left: two resistors VSYS→EN→GND, UVLO ~17–18 V. |
| **CR2 thermal vias** | **Addressed** this session — 12 vias + a 4 mm-wide SW pour on B.Cu. Note this enlarges the switching node; it is a deliberate thermal-vs-EMI trade. |
| **3V3 rail budget** | Still open. ~500 mA typical from the CM4's 600 mA output; ESP32 Wi-Fi TX peaks push it over. |
| **No fiducials** (FD-001) | Still open, and it matters more than it looks — you have 0.5 mm-pitch DSBGA. Most assemblers want ≥3 per SMD side. |
| **Surface finish** | Specify **ENIG, not HASL**. The stackup still declares `HAL lead-free`. 0.5 mm-pitch DSBGA on HASL is a poor match. |
| Courtyard overlaps C110/C109, C82/C78 | Still open, probably assemblable. |
| SDZ has no software control; MPU-6050 INT unconnected; PCM5102A SCK pin choice | Still open, all firmware-workable. |

**One new item:** the mux DSBGA pads have **no paste apertures** (`F.Cu` + `F.Mask` only — 42 pads). This is the KiCad BGA library default and is defensible for a balled DSBGA, but confirm your assembler is happy placing them dry.

---

## Ordering checklist

- 4 layers, 128 × 128 mm, 1.6 mm
- **Surface finish: ENIG**
- Min track 0.2 mm · min spacing 0.127 mm · min drill 0.4 mm — but fix U8's 0.123 mm first
- Tented vias (10 via-in-pad instances)
- Stencil required — 1211 paste apertures
- Confirm inner-layer copper weight (1 oz declared; 0.5 oz is the common default)
- **Re-export gerbers last**, after every fix

**Before you click order:**
1. Save the file — the current refill is unsaved.
2. Fix C100/C101/C129 to 50 V. ← the only one that affects hardware
3. Populate LCSC numbers if you want assembly.
4. Delete the 42 phantom mux pads, then re-run DRC and confirm it comes back near-zero.
5. Fix U8 clearance, remove the duplicate via.
6. Export gerbers once, at the end.

---

## What ran, and what didn't

**Ran:** KiCad native ERC (210 violations) · KiCad native DRC with schematic parity (370 violations, 0 unconnected, 6 parity) · `analyze_schematic.py` · `analyze_pcb.py --full --proximity` · `cross_analysis.py` · `analyze_emc.py` (125 findings) · `analyze_thermal.py` · `analyze_gerbers.py` · direct gerber geometry verification · connectivity-partition cross-reference · raw S-expression spot-checks on mux/amplifier footprints and zone fills.

**Not run:**
- **SPICE** — `ngspice`, `ltspice`, `xyce` all absent. Filter/divider/compensation values checked analytically only.
- **Lifecycle/obsolescence audit** — no distributor API credentials, and MPNs are not in symbol properties.
- **`analyze_thermal.py` returned nothing useful** (score 100/100, one component assessed). Rev 2's hand-calculated thermal table still stands: ~11 W per TPA3116D2 at full sine, heatsink required.
- **Impedance not verified** — TMDS pairs are beautifully length-matched (0.00–0.02 mm intra-pair) but I cannot confirm 100 Ω differential without the fab's stackup.
- **U20/U21 thermal pad dimensions** not confirmed against the DAP drawing — datasheet page would not text-extract.

**Caveat:** the `.kicad_pcb` was edited three times mid-review (18:17 → 18:35 → unsaved refill). All DRC figures above are from the **18:35** save. Re-run DRC after saving.

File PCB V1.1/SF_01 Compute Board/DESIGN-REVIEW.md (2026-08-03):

# SF_01 Compute Board — Pre-Fabrication Design Review (Revision 2)

**Project:** SF_01 Compute Board — KiCad 10.0, 6 hierarchical sheets, 4-layer, 128 × 128 mm
**Date:** 2026-08-03 (supersedes the 2026-08-02 review)
**Analyzers run:** `analyze_schematic.py`, `analyze_pcb.py --full --proximity`, `cross_analysis.py`, `analyze_emc.py`, `analyze_thermal.py`, `analyze_gerbers.py`
**Not run:** SPICE (no simulator installed), lifecycle audit (no distributor API keys), native KiCad ERC/DRC (`kicad-cli` not on PATH)
**Datasheets read directly:** TPA3116D2/TPA3130D2 (SLOS708G), TPS54540 (SLVSC24), TS5A3159A (SCDS200F), TPS2041B (SLVS514P), LM1085 (SNVS038H), PCM5102A (SLAS859C), WS2812B, SN74LVC1G07

---

## Verdict

**Electrically ready to order.** Every blocker from the previous review is resolved, and one of them was my error. What remains is a short list of robustness improvements and two things to do at order time. Nothing here will stop the board working.

---

## Correction to the Previous Review

**Blocker B2 ("TPA3116D2 footprint missing its PowerPAD") was wrong.** I raised it as CRITICAL twice. It is not a defect.

The TPA3116D2 in the **DAD** package has its PowerPAD on the **top** of the package, for an external heatsink — not on the bottom for a PCB land. SLOS708G states it directly:

> "the TPA3116D2 does 2 × 50 W / 4 Ω with a small heat-sink attached to its **top side PowerPAD**"

§10.3 then specifies the EVM heatsink (ATS-TI 10 OP-521-C1-R1, a 14 × 25 × 50 mm extruded aluminium part) and notes it "has shown to be sufficient for continuous output power."

The thermal table confirms the split:

| Device | Package | θJA | Pad location |
|---|---|---|---|
| TPA3116D2 (U17–U19) | **DAD** | 14 °C/W | **Top side** — heatsink |
| TPA3130D2 (U20, U21) | **DAP** | 36 °C/W | Bottom side — PCB land |

So U17/U18/U19 having 32 pads and no bottom thermal land is **correct**, and U20/U21 having 33 pads with the extra one on GND is **also correct**. Both footprints are right. My apologies for the noise — the asymmetry between the two looked like a library sync error, and I should have checked the package variant before calling it.

---

## Previous Review Delta

| Status | Count |
|---|---|
| Fixed | 13 |
| Withdrawn (my error) | 1 |
| Still open | 6 |
| New this revision | 5 |

### Fixed

| Ref | Issue | Resolution — verified |
|---|---|---|
| B1 | LM1085 linear reg, 24 V → 5 V, needed 19 W in a 2.5 W package | Replaced by **U4 TPS54540** buck. FB 60.4 k/11.5 k × 0.8 V = **5.002 V**; RT 205 k → ~473 kHz; Type-II comp (10.7 k + 7.5 nF, 6.8 pF); 100 nF boot; CR2 catch diode correctly oriented (pads 1–4 GND anode, 5–8 SW cathode); thermal pad to GND |
| B3 | Mux on 3.3 V while its signal sits at 3.0 V DC | New **4V5_A** rail from U10 (LP5907-4.5). Headroom is now 1.5 V against the 1.27 V needed at 26 dB gain — the amplifier clips first, by 1.4 dB. Critically, **3V3_A was correctly split off** so the PCM5102As (3.46 V max) stay on their own rail |
| B4 | 220 µF **6.3 V tantalums** on the 24 V rail | BOM now specifies C47023115, 220 µF **35 V** aluminium electrolytic, D6.3 × 7.7 mm — fits the existing footprint |
| H1 | USB-C had sink Rd while sourcing VBUS | R7/R17 (56 k) added as Rp to VBUS; R3/R65 (Rd) lifted onto Q1's drain; **Q1 BSS138** gate on `USB_OTG_ID`, source GND. Verified: Rd grounded only in device mode, removed in host mode |
| H3 | Five 100 k resistors bridging VSYS to 3V3 | Now 100 k pull-ups from VSYS to SDZ, with SDZ tied to FAULTZ — TI's documented auto-recovery configuration (§7.3.9) |
| H4 | 33 V TVS on the 5 V HDMI rail; VSYS unprotected | D1 is now **SMAJ26A on VSYS**, and after the orientation fix, pin 1 (cathode) → VSYS, pin 2 (anode) → GND. Correct |
| H5 | MUTE driven by GPIO, exceeding the 10 V/ms slew limit | 100 k series on every MUTE pin (R30/R39/R50/R60/R76) plus 100 k pull-downs on the `DRIVER_MUTE` node |
| H7 | 25 V filter caps on nodes idling at 12 V | BOM now 50 V (C694504) |
| H8 | Tweeter inductors rated 1.2 A against 1.37 A RMS | C602032, 2.35 A rated / 3.5 A saturation |
| H11 | Min spacing 0.092 mm, below fab minimum | Now **0.127 mm**; DFM tier improved from "challenging" to **standard** |
| M12 | SYNC low-passed at 15.9 kHz, blocking the 400 kHz clock | 1 nF caps deleted, 10 k → **100 Ω**. Clean star from U17 to four slaves |
| M18 | MPU-6050 CLKIN and FSYNC floating | Both tied to GND |
| M21 | `WOOFER_MUTE`/`TWEETER_MUTE` aliasing one net | Single `DRIVER_MUTE` net |

### Accepted by the designer (no action)

WS2812Bs on 3.3 V (indication only), J1 land pattern, JST XH 3 A rating, barrel jack rating, no VSYS fuse, CM4 part-number mismatch.

---

## Critical Findings

**None.** No issue in this revision will prevent the board from functioning.

The list below is ordered by what I'd actually spend time on.

| # | Severity | Issue |
|---|---|---|
| 1 | WARNING | U4 `EN` floating — no programmable UVLO on the buck |
| 2 | WARNING | CR2 has zero thermal vias while dissipating ~1.1 W |
| 3 | WARNING | 3V3 rail load likely exceeds the CM4's 3.3 V output capability |
| 4 | SUGGESTION | U4 has 6 thermal vias against a 9 minimum |
| 5 | SUGGESTION | No local HF bypass at U4's VIN pin |
| 6 | SUGGESTION | Two courtyard overlaps between D6.3 electrolytics and 0603s |
| 7 | ORDER-TIME | Gerbers are stale; surface finish should be ENIG |

---

## 1 — U4 EN pin is floating (WARNING)

`U4.3 (EN)` is a single-pin net. Per SLVSC24, an internal pull-up current source means a floating EN **enables** the device, so it will start — but at the default input threshold of ~4.3 V.

Consequence: on power-up the converter begins switching while VIN is barely above 4 V, at near-maximum duty cycle, into 94 µF of output capacitance plus the CM4. TI's recommended practice is a two-resistor divider from VIN to EN setting UVLO for the actual input range — around 17–18 V for a 24 V design. A floating high-impedance pin adjacent to a 24 V switching node is also noise-susceptible; the EN threshold is ~1.2 V.

**Fix:** two resistors from VSYS to EN to GND. This is the single most worthwhile change left.

## 2 — CR2 thermal vias (WARNING)

`TV-001` reports **0 thermal vias** on CR2 against a 9 minimum.

Dissipation: at 3 A output with D = 5/24 = 0.208, the catch diode conducts 79% of each cycle. At ~0.45 V forward drop (a 30 A device run at 10% of rating), **P ≈ 0.79 × 3 × 0.45 ≈ 1.1 W**.

The PowerFLAT 5×6 tab is on pads 5–8, which are the **SW node** — so you can't simply flood it with copper without enlarging the switching node and worsening EMI. The practical approach is a modest via field under the tab into an isolated SW-net pour on In2, plus vias on the GND pads 1–4. At 3 A the part is well within rating; this is about keeping junction temperature sensible, not preventing failure.

## 3 — 3V3 rail budget (WARNING)

Unchanged from the previous review and still worth knowing before bring-up. The 3V3 rail is sourced entirely from the CM4's 3.3 V output (`U1.84/86`), rated 300 mA per pin / **600 mA total**.

| Load | Estimate |
|---|---|
| ESP32-WROVER-E | 240 mA avg, **500 mA peak** on Wi-Fi TX |
| 4 × WS2812B | up to 240 mA at full white |
| 2 × PCM5102A DVDD | ~20 mA |
| MPU-6050 + BME680 | ~6 mA |
| LEDs, pull-ups | ~5 mA |

Roughly **500 mA typical**, over 600 mA on peaks. Overloading the CM4's internal regulator can brown out the module. If you see instability during Wi-Fi transmission with the LEDs bright, this is the cause. A dedicated 3.3 V LDO from SYS_5V for the ESP32 would decouple it. (Note the 600 mA figure came from a web source, not the CM4 PDF, which resisted text extraction — worth confirming.)

## 4–5 — Buck layout refinements (SUGGESTION)

**Thermal vias:** U4 has 6 against a 9 minimum. At 24 → 5 V, 3 A the TPS54540 dissipates roughly 1–1.5 W. Adding three or four more vias under the exposed pad is cheap insurance.

**Local bypass:** the nearest cap to U4's VIN is C101, a 10 µF 1210 at **6.36 mm**. There is no small ceramic directly at pin 2. A 100 nF 0603 placed hard against VIN/GND would meaningfully reduce high-frequency ringing on the switch node.

**Hot loop:** measured at **25.3 mm²** using C101 → U4 → CR2, which is right at the ≤25 mm² guideline rather than comfortably inside it. Pulling C101 closer to U4 would improve it. (The analyzer reported 377 mm² — see False Positives.)

## 6 — Courtyard overlaps (SUGGESTION)

| Pair | Overlap |
|---|---|
| C110 (220 µF, D6.3) ↔ C109 (100 nF, 0603) | 1.232 mm² |
| C82 (1 nF, 0603) ↔ C78 (220 µF, D6.3) | 1.279 mm² |

The new electrolytics are D6.3 × 7.7 mm cans. Their bodies encroach on adjacent 0603 courtyards. Since the 0603s are ~0.9 mm tall and the electrolytic body sits above its own seating plane, this is probably assemblable — but it's tight for pick-and-place and rework. Worth nudging apart if you have room.

## 7 — Order-time items

**Re-export the gerbers.** `production/SF_01_Compute_Board.zip` was written at 21:34; the PCB was last modified at 21:35. The package is one minute stale. The archive itself is otherwise complete and correct — I extracted and analysed it: all 11 layers present, both drill files present, layers aligned, 128.0 × 128.0 mm, 1936 vias at 0.4 mm.

**Specify ENIG, not HASL.** The stackup declares `HAL lead-free`. You have seven TS5A3159A in **DSBGA, 0.5 mm pitch, 1.4 × 0.9 mm**. HASL's uneven surface is a poor match for that package.

---

## Component Summary

| Type | Count |
|---|---|
| Capacitors | 187 |
| Resistors | 76 |
| ICs | 28 |
| Inductors | 21 |
| Connectors | 14 |
| LEDs | 6 |
| Switches | 5 |
| Diodes | 3 |
| Transistors | 1 |
| **Total** | **341** |

Nets 372 · Sheets 6 · Unique parts 77 · PCB footprints 342 (341 + one logo graphic)

**Schematic ↔ PCB sync: exact.** Every schematic reference has a footprint and vice versa; the only PCB-side extra is a `G***` graphic with no schematic counterpart.

**Sourcing:** MPN coverage in schematic symbol properties is 1/77, which triggers the `SS-001` pre-fab gate. In practice this is satisfied outside the schematic — `BoM.csv` carries verified LCSC part numbers for all 341 designators. If you want the gate to clear, the MPNs need writing into the symbol properties.

---

## Power Tree

```
J2 barrel jack 24 V
 └── VSYS ── D1 SMAJ26A TVS (Vbr 28.9 V)  [no fuse — accepted]
      ├── U17/U18/U19 TPA3116D2   PVCC/AVCC   2×50 W @ 4 Ω
      ├── U20/U21     TPA3130D2   PVCC/AVCC   2×15 W @ 8 Ω
      ├── 10 × 220 µF/35 V bulk + 100 nF/1 nF/10 nF HF
      ├── 5 × 100 k → SDZ/FAULTZ (auto-recovery pull-ups)
      └── U4 TPS54540 buck, 473 kHz, 6.8 µH, CR2 catch diode
           └── SYS_5V (5.002 V, 2 × 47 µF)
                ├── U1 CM4  +5V ×6 pins
                ├── U27 TPS2041B ──► VBUS (USB-C, host mode only)
                ├── U6  RT9742   ──► HDMI_5V ──► J1.18
                ├── U11 LP5907-3.3 ──► 3V3_A ──► U5/U14 AVDD+CPVDD
                ├── U10 LP5907-4.5 ──► 4V5_A ──► 7 × TS5A3159A V+
                └── U8 74LVC1G07
      
CM4 3.3 V output ──► 3V3 ──► ESP32, WS2812B ×4, DAC DVDD ×2,
                              MPU-6050, BME680, LEDs   [see finding 3]
```

Rail pin counts: VSYS 76 · SYS_5V 32 · 3V3 53 · 3V3_A 17 · 4V5_A 11 · VBUS 12 · HDMI_5V 8

---

## Analyzer Verification

### Amplifier configuration — verified against SLOS708G Table 1

All five devices are consistent and correct:

| Ref | R to GVDD | R to GND | Mode | Gain |
|---|---|---|---|---|
| U17 | 100 k (R18) | 20 k (R19) | **Master** | 26 dB |
| U18 | 47 k (R28) | 75 k (R29) | Slave | 26 dB |
| U19 | 47 k (R37) | 75 k (R38) | Slave | 26 dB |
| U20 | 47 k (R47) | 75 k (R48) | Slave | 26 dB |
| U21 | 47 k (R57) | 75 k (R58) | Slave | 26 dB |

Every divider totals ≥ 100 kΩ as §7.3.5 requires. PLIMIT tied to GVDD on all five with 1 µF — power limiting disabled per Table 3. Bootstrap 220 nF/50 V on all 20 outputs (§7.3.6 asks ≥ 16 V). Input coupling 1 µF against 30 kΩ input impedance = 5.3 Hz corner, explicitly endorsed by Table 2. INN pins AC-grounded through matching 1 µF — correct single-ended configuration per §7.3.7.

### Multiplexer — verified against SCDS200F §5

Ball map confirmed: A1 = NO, A2 = IN, B1 = GND, B2 = V+, C1 = NC, C2 = COM. All seven V+ pins on 4V5_A, all seven IN pins on `ORIENTATION_SWITCH` from ESP32 IO32.

Topology resolves to two coherent states — one giving L/L/mono/mono/R/R across the six woofers, the other an alternating L-R arrangement, with R72/R73 acting as a passive mono summer.

Control levels: VIH is 2.4 V min in both the 3.3 V and 5 V electrical tables, so the ESP32's 3.3 V drive has 0.9 V margin at V+ = 4.5 V.

### High-speed routing — excellent

| Pair | P | N | Delta | Vias |
|---|---|---|---|---|
| TMDS DATA0 | 70.46 mm | 70.46 mm | **0.00 mm** | 0 |
| TMDS DATA1 | 70.29 mm | 70.29 mm | **0.00 mm** | 0 |
| TMDS DATA2 | 70.28 mm | 70.29 mm | **0.01 mm** | 0 |
| TMDS DATA3 | 70.56 mm | 70.58 mm | **0.02 mm** | 0 |
| USB D+/D− | 60.48 mm | 61.70 mm | 1.22 mm | 0 |

Intra-pair matching is essentially perfect and inter-pair spread across all four TMDS lanes is 0.30 mm. Every pair is routed on a single layer with **zero vias**. USB's 1.22 mm delta is well inside the USB 2.0 high-speed budget.

### Ground plane

**In1.Cu carries zero tracks** and holds 15,410 mm² of GND zone fill — it is a solid, unbroken ground plane directly beneath F.Cu across 0.1 mm of prepreg. Since F.Cu carries 4,058 of the 5,077 track segments, the overwhelming majority of signals have an ideal return path. GND totals 1,348 vias.

---

## PCB Layout Analysis

**Board:** 128 × 128 mm, 4 layers, 1.6 mm, HASL lead-free, 343 footprints all on F.Cu, 329 SMD / 12 THT, **routing 100% complete, 0 unrouted**.

**Stackup:** F.Cu 35 µm / 0.1 mm prepreg / In1.Cu 35 µm / 1.24 mm core / In2.Cu 35 µm / 0.1 mm prepreg / B.Cu 35 µm. Note this declares 1 oz on inner layers; most fabs supply 0.5 oz inner as standard on 4-layer 1.6 mm — confirm when ordering if you're relying on inner-layer current capacity.

**Track usage:** F.Cu 4058, B.Cu 561, In2.Cu 458, In1.Cu 0.

**Vias:** 1936, all 0.8/0.4 mm, 0.2 mm annular ring — uniform and well within fab capability.

**VSYS routing:** 1089 mm total, 4–6 mm on the trunk, 278 vias. The sub-1 mm segments are stubs to 100 k resistors and decoupling, not current paths. Well sized for the ~8 A this board can draw.

**DFM:** tier **standard**, min track 0.2 mm, min spacing 0.127 mm, min drill 0.4 mm, min annular ring 0.2 mm. One "violation" — board exceeds 100 × 100 mm, which is a pricing tier note, not a manufacturability problem.

**Edge clearance** (accepted by designer): C6, C7 at 0.10 mm; C17, C19 at 0.15 mm; C115, C119 at 0.17 mm; SW4, U5 at 0.18 mm; J1 courtyard overhanging 2.54 mm (intentional for the right-angle HDMI); L8 by 0.05 mm.

**Not present:** fiducials (0), test points (0/358 nets), mounting holes (the four 2.7 mm holes are CM4 standoffs).

---

## Thermal Analysis

`analyze_thermal.py` assessed only one component and returned a score of 100/100 — it could not derive dissipation for the amplifiers or the buck, so the numbers below are hand-calculated from datasheet θJA figures.

| Device | P_diss (full output) | θJA | Notes |
|---|---|---|---|
| TPA3116D2 ×3 | ~11 W each at 2×50 W/4 Ω | 14 °C/W (DAD) | **Heatsink required** — TI's EVM uses a 14×25×50 mm extrusion on the top PowerPAD and calls it sufficient for continuous output |
| TPA3130D2 ×2 | ~3.3 W each at 2×15 W/8 Ω | 36 °C/W (DAP) | 47 and 42 thermal vias — above the 28 minimum. Datasheet rates 2×15 W with no heatsink on a *single-layer* board, so a 4-layer with this via count is comfortable |
| TPS54540 | ~1–1.5 W | — | 6 thermal vias (9 recommended) |
| CR2 | ~1.1 W | — | **0 thermal vias** |
| U10/U11 LDOs | <40 mW | — | Negligible |

At realistic listening levels the picture is far easier — music's crest factor means average dissipation is a small fraction of these figures. The 11 W per TPA3116D2 is a sustained-sine-at-clipping number.

**Heatsink clearance:** nearest neighbours to U17–U21 are 0603 passives at ~6.2–6.5 mm from each package centre. The HTSSOP-32 body is ~11 × 6.1 mm, so you have roughly 3 mm of clear board around each package edge. Check your chosen heatsink's base footprint against that. Also confirm whether the top PowerPAD is electrically live before using a bare metal heatsink spanning devices — use an insulating thermal interface pad if in doubt.

---

## EMC / Cross-Domain

125 EMC findings, risk score 0. The substantive ones:

**Switching harmonics (SW-001, EE-002):** U4 at 500 kHz puts 117 harmonics in the 30–88 MHz band. Inherent to any buck; mitigation is loop area, which is already at the guideline.

**Input filter (EF-001):** input LC corner at 0.11 MHz gives f_sw/f_c = 4.7×, marginally under the recommended ≥5×. Minor.

**Clock routing (CK-001/2/3):** `AMP_CLK_SYNC` is 172 mm on an outer layer and passes near J12. Since it now actually carries a 400 kHz clock, keep the 100 Ω damping and add ground stitching vias at its 4 layer transitions.

**Decoupling (DC-001):** flagged as too far on U2 and U3 (HDMI ESD arrays) and moderately far on U9, U16, U26.

**ESD grounding (ES-002):** U7 (USB-C ESD array) has no ground via within 3 mm; U2 and U3 have one each. For a TVS, ground inductance is the dominant parasitic — roughly 37.5 V of overshoot per nH during an 8 kV strike. Adding a second via at each is cheap.

**Cross-domain:** `RP-002` reports SYS_5V crossing a VSYS plane gap and `WFR_SCK` crossing a 3V3 gap; `PS-002` reports plane splits on VSYS (195 islands), 3V3 (5), 3V3_A (3) and 4V5_A (2). See False Positives — VSYS is routed as tracks, not a zone.

---

## False Positives / Reviewer Overrides

| Finding | Verdict |
|---|---|
| **B2 — TPA3116D2 "missing thermal pad"** (my previous review) | **Withdrawn.** DAD is a top-side PowerPAD package. Both footprints are correct |
| **SW-003 — "hot loop 377 mm²"** | Substantially wrong. The analyzer picked C104, a bulk electrolytic 84 mm away on the amplifier side. Measured against the actual input ceramic (C101), the loop is **25.3 mm²** |
| **PP-001 ×5 — GVDD "no DC path to a power rail"** | GVDD is an internally generated gate-drive output, correctly bypassed with 1 µF and correctly tied to PLIMIT per Table 3 |
| **VM-001 — `ORIENTATION_SWITCH` 4.5 V/3.3 V crossing** | TS5A3159A VIH is 2.4 V min in both electrical tables; 3.3 V drive has 0.9 V margin |
| **VM-001 — `__unnamed_6` 5 V/3.3 V crossing** | `RUN_PG` into a 74LVC input; the LVC family is 5 V tolerant with VIH = 2.0 V at VCC 4.5–5.5 V |
| **SU-001 ×3 — "adjacent signal layers"** | Based on layer *type* declarations. In1.Cu carries zero tracks and is a solid GND plane; In2 carries only 458 segments. Not a real stackup problem |
| **PS-002 — VSYS "195 islands"** | VSYS is routed as tracks, not a zone, so the connectivity graph counts per-layer runs. Routing is 100% complete |
| **GP-001 ×46, RP-001 ×22** | Over-reported. The actionable subset is stitching vias at layer transitions on `AMP_CLK_SYNC`, `SYS_5V`, `HDMI_5V` and the I²S clocks |
| **GR-001/GR-003 on `production/`** | The extracted gerber folder was deleted; only the zip remains. Analysing the zip contents directly shows a complete, aligned, correct package |
| **NT-001 ×114 on U1** | Unused CM4 GPIOs. Add no-connect flags for clean ERC, but not defects |
| **Schematic "duplicate" refs (U1, SW6, U12…)** | Multi-unit symbols, not annotation errors |
| **thermal.json score 100/100** | Only one component assessed; the analyzer could not derive amplifier or converter dissipation. Disregard — see the hand-calculated table above |

---

## Still Open (previously reported, not addressed)

These are carried forward for completeness; none is a blocker.

- **SDZ has no software control.** Now correctly pulled to VSYS with FAULTZ auto-recovery, but the ESP32 cannot hold SDZ low at power-up as §7.3.9 recommends for avoiding DC-detect faults and pop. A spare GPIO (IO34/IO35/IO5 are free) would do it.
- **PCM5102A SCK on IO26/IO18.** The classic ESP32 can only emit an I²S master clock on GPIO0/1/3. Fixable in firmware — drive both pins low, which is equivalent to TI's SCK-to-GND PLL mode.
- **MPU-6050 INT unconnected.** Orientation changes must be polled. A design choice, but notable given orientation switching is the board's headline feature.
- **GLOBAL_EN has no pull-up**, and the SW1/U8/`RUN_PG` power-button circuit still looks non-functional as drawn — pressing the button appears to do nothing while the Pi is running. I could not confirm the CM4's pin definitions from its datasheet (CID-encoded PDF). Worth comparing against the CM4IO reference schematic.
- **No fiducials, test points or mounting holes.**
- **Inner-layer copper weight** — confirm 1 oz vs the more common 0.5 oz default if you rely on it.

---

## Not Performed / Review Limits

- **SPICE simulation not run** — `ngspice`, `ltspice` and `xyce` are all absent. Filter, Zobel, feedback-divider and compensation values were checked analytically instead.
- **`analyze_thermal.py` produced no useful output** — it assessed one component and could not derive power dissipation. All thermal figures above are hand-calculated from datasheet θJA.
- **Lifecycle/obsolescence audit not performed** — no distributor API credentials, and MPNs live in `BoM.csv` rather than schematic properties, so the script has nothing to read.
- **Native KiCad ERC and DRC not run** — `kicad-cli` is not on PATH. **Run both yourself before ordering.** Expect many false "power pin not driven" ERC warnings from missing PWR_FLAGs and from the CM4 symbol's 3.3 V output being typed as `power_in`.
- **CM4 datasheet could not be text-extracted.** The 300 mA/pin, 600 mA total figure in finding 3 came from a web search, not the PDF.
- **Differential pair detection returned nothing** in the schematic analyzer — the TMDS nets use `DATA0P`/`DATA0N` naming rather than the suffixes it matches. I measured the pairs directly from PCB net lengths instead.
- **Impedance control not verified.** The TMDS pairs are length-matched beautifully, but I cannot confirm the trace geometry hits 100 Ω differential without the fab's stackup. If you specified controlled impedance, confirm with the fab.

---

## Positive Findings

1. **Power architecture is now correct.** The TPS54540 design is textbook — feedback lands on 5.002 V, compensation is proper Type-II, the catch diode is correctly oriented, and the thermal pad is grounded.
2. **HDMI TMDS routing is excellent** — 0.00–0.02 mm intra-pair matching, 0.30 mm inter-pair spread, zero vias, referenced to a solid plane.
3. **In1.Cu is an unbroken ground plane** with no routing on it — the best arrangement available on 4 layers.
4. **All five amplifiers are consistently and correctly configured** for 26 dB with proper master/slave assignment, verified against Table 1.
5. **The USB-C dual-role circuit is genuinely clever** — three components reusing the existing mode switch, and it satisfies Type-C requirements in both directions.
6. **SDZ/FAULTZ auto-recovery** matches TI's documented topology.
7. **Routing is 100% complete** with zero unrouted nets, and the schematic and PCB are exactly in sync.
8. **Fabrication package is complete and aligned** — 11 layers, both drill files, correct dimensions.
9. **DFM improved from "challenging" to "standard"** between revisions.
10. **VSYS power distribution** is properly sized at 4–6 mm with 278 vias.

---

## Ordering Notes

- 4 layers, 128 × 128 mm, 1.6 mm
- **Surface finish: ENIG** (not HASL — you have 0.5 mm-pitch DSBGA)
- Min track 0.2 mm, min spacing 0.127 mm, min drill 0.4 mm — standard capability
- 1936 vias at 0.4 mm; specify tented vias so solder doesn't wick through the 10 via-in-pad instances
- Stencil required — 1211 paste apertures, 0.98 SMD ratio
- Confirm inner-layer copper weight
- **Re-export gerbers first**

**Before you click order:** run ERC and DRC in KiCad, and add the two EN divider resistors if you want the buck to have a proper UVLO.

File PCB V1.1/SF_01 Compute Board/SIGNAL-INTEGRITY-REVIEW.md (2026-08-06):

# SF_01 Compute Board — Wiring, Signal Integrity & Current Capacity Review

**Date:** 2026-08-05 · **Companion to:** `DESIGN-REVIEW-R3.md`
**Scope:** every net traced schematic→PCB, trace width vs current, differential impedance from the stackup, per-IC datasheet checks.
**Load assumptions (your figures):** 6 × 30 W RMS woofers into 3.95 Ω · 4 × 10 W RMS tweeters into 6 Ω · 220 W RMS total.

---

## Headline

**Your HDMI is correct only by accident.** The trace geometry hits 100 Ω on the stackup JLCPCB will actually build, and misses it by 31 % on the stackup declared in your project file. They are two different stackups, and nothing in the file says which one you want.

**USB D+/D− is wrong on both.**

Everything else in the wiring is sound. Three amplifier output traces need widening, and the VSYS inner-layer routing depends on a copper weight you haven't specified.

---

## 1. Differential impedance — measured, not assumed

I measured the routed geometry directly from the PCB rather than trusting the netclass.

**Measured:** all four TMDS pairs and USB are `w = 0.2 mm`, on **F.Cu only, zero vias**, referenced to the solid In1.Cu ground plane.

| Pair | width | centre-to-centre | edge gap | dominant parallel run |
|---|---|---|---|---|
| DATA0 | 0.2 mm | 0.327 mm | **0.127 mm** | 23.9 mm |
| DATA1 | 0.2 mm | 0.327 mm | **0.127 mm** | 13.3 mm |
| DATA2 | 0.2 mm | 0.400 mm | **0.200 mm** | 9.6 mm |
| DATA3 | 0.2 mm | 0.327 mm | **0.127 mm** | 29.7 mm |
| USB D± | 0.2 mm | 0.450 mm | **0.250 mm** | 29.7 mm |

Now the two candidate stackups (IPC-2141 edge-coupled microstrip, t = 35 µm):

### Stackup A — what your file declares (0.1 mm prepreg, εr 4.5)

| Pair | Z₀ single-ended | Z_diff | target | verdict |
|---|---|---|---|---|
| DATA0/1/3 | 40.1 Ω | **68.8 Ω** | 100 Ω | **−31 %** ✗ |
| DATA2 | 40.1 Ω | **74.6 Ω** | 100 Ω | **−25 %** ✗ |
| USB D± | 40.1 Ω | **76.7 Ω** | 90 Ω | **−15 %** ✗ |

### Stackup B — what you're actually ordering: JLCPCB 4L / 1.6 mm / **1 oz inner**

Confirmed from JLCPCB's published stackup data (`jlcpcb_4L_1.6mm_outer1oz_inner1oz_NOREQ`):
**7628 prepreg 0.203 mm, εr 4.4, inner copper 0.030 mm.**

| Pair | Z₀ single-ended | Z_diff | target | verdict |
|---|---|---|---|---|
| DATA0/1/3 | 66.0 Ω | **97.2 Ω** | 100 Ω ±10 % | ✓ **on target** |
| DATA2 | 66.0 Ω | **107.4 Ω** | 100 Ω ±10 % | ✓ (at the edge) |
| USB D± | 66.0 Ω | **112.6 Ω** | 90 Ω ±15 % | **+25 %** ✗ |

Choosing 1 oz inner barely moves the prepreg (0.2104 → 0.203 mm) so **TMDS stays on target at ~97 Ω**, while inner copper roughly doubles (0.0152 → 0.030 mm). It's the right call on both counts.

### What this means

Your file declares a **0.1 mm prepreg**. Your actual build has **0.203 mm**. The design is correct for what you're ordering and wrong for what it documents.

That matters more than it sounds, because **JLCPCB has a 4-layer 1.6 mm stackup that matches your declared 0.1 mm almost exactly** — `JLC04161H-3313`, at 0.0994 mm prepreg. If you ever order controlled impedance and pick the option that matches your file, **TMDS drops to ~69 Ω and HDMI breaks.**

| JLCPCB 4L/1.6 mm stackup | prepreg | your TMDS |
|---|---|---|
| **7628** (default, incl. 1 oz inner at 0.203 mm) | 0.203–0.2104 mm | **97–98 Ω** ✓ |
| 3313 — *matches your declared 0.1 mm* | 0.0994 mm | **~69 Ω** ✗ |
| 1080 | 0.0764 mm | worse ✗ |

**Actions:**

1. **Correct the stackup in the file to 0.203 mm prepreg / εr 4.4 / 1 oz inner.** Right now the file describes the one build that would break HDMI.
2. **Take the default 7628 stackup.** Do not select 3313 or 1080.
3. **Fix USB.** At `s = 0.25 mm` you need **w ≈ 0.32 mm** for 90 Ω; you have 0.2 mm. USB D+/D− also mixes **0.2 mm and 0.25 mm widths along the same pair** (11 segments each) — an impedance step mid-run. Make it one width.
4. **Make DATA2 match the others** — 0.327 mm centre-to-centre, not 0.4 mm. It's 10 Ω off its siblings.

USB 2.0 high-speed has ~500 ps edges; at ~6.7 ps/mm the critical length is ≈ 37 mm and your run is 60 mm, so the pair is electrically long and the mismatch is real, not academic. That said, a +27 % mismatch over 60 mm will most likely still enumerate and run — treat it as "fix before you respin", not "will not work".

### Length matching — excellent, no action

| Pair | P | N | skew |
|---|---|---|---|
| DATA0 | 70.46 mm | 70.46 mm | **0.00 mm / 0.0 ps** |
| DATA1 | 70.29 mm | 70.29 mm | **0.00 mm / 0.0 ps** |
| DATA2 | 70.28 mm | 70.29 mm | 0.01 mm / 0.1 ps |
| DATA3 | 70.56 mm | 70.58 mm | 0.02 mm / 0.1 ps |
| USB D± | 60.48 mm | 61.70 mm | 1.22 mm / 8.2 ps |

Inter-pair spread across all four TMDS lanes is 0.30 mm (2 ps). Every pair single-layer, zero vias, over an unbroken plane. This is genuinely very good routing.

---

## 2. Amplifier output traces — three necks, real

Post-filter outputs to the JST connectors are fine: **1.0–4.0 mm**, ≤14 °C rise at 2.76 A. No action.

The problem is between the amplifier pins and the filter inductors. Every woofer output carries the full **2.76 A RMS** (30 W into 3.95 Ω), and several have a long **0.4 mm** section in series with the wide parts:

| Net | total | at 0.4 mm | ΔT at 2.76 A, 1 oz outer |
|---|---|---|---|
| `Net-(U19-OUTNR)` | 15.8 mm | **10.85 mm (69 %)** | **≈ 63 °C** |
| `Net-(U18-OUTNR)` | 13.4 mm | **8.90 mm (67 %)** | **≈ 63 °C** |
| `Net-(U18-OUTNL)` | 32.7 mm | 8.11 mm (25 %) | ≈ 63 °C over that section |
| `Net-(U17-OUTPR)` | 19.7 mm | 5.95 mm (30 %) | ≈ 63 °C over that section |
| `Net-(U19-OUTPR)` | 5.8 mm | 4.00 mm (69 %) | ≈ 63 °C over that section |

A 3 mm section doesn't help if there's a 0.4 mm neck in series. IPC-2221 for 2.76 A at 10 °C rise on 1 oz outer wants **≥ 1.22 mm**; at a relaxed 20 °C, **≥ 0.85 mm**.

A short 0.4 mm escape at the pad itself is unavoidable — the HTSSOP pad is 0.41 mm wide. But 4–11 mm of it is not a pad escape, it's unwidened routing. Everything else on these nets is already 1–4 mm, so this reads as an oversight.

**Action:** widen to ≥ 1.2 mm as soon as the trace clears the pin escape. This sits under five Class D amplifiers that are already the hottest thing on the board.

Tweeter outputs at 1.29 A are fine at the widths used.

---

## 3. VSYS current capacity — depends on a number you haven't specified

At sustained full output: 220 W / 0.85 efficiency / 24 V ≈ **10.8 A**.

VSYS copper distribution:

| Layer | total | dominant widths |
|---|---|---|
| In2.Cu | 646.6 mm | **6.0 mm (422 mm)**, 4.0 mm (193 mm) |
| F.Cu | 416.7 mm | 1.5 mm (142 mm), 3.0 mm (94 mm), 4.0 mm (73 mm) |
| B.Cu | 25.4 mm | 4.0 mm |

Temperature rise if a single 6 mm In2.Cu run carried the whole load:

| inner copper | at 8 A | at 10.8 A |
|---|---|---|
| **1 oz (0.030 mm)** — what you're ordering | **51 °C** | 100 °C |
| 0.5 oz (0.0152 mm) — JLCPCB default | **123 °C** | far worse |

**Ordering 1 oz inner was the right call** — it roughly halves the rise and takes the 0.5 oz case (which was genuinely not adequate) off the table.

Two honest caveats on the remaining numbers:
- VSYS is a **mesh**, not one trace — 278 vias tie F.Cu, In2.Cu and B.Cu together, so current splits across layers and the single-trace figure above is pessimistic. I did not model the actual current division.
- 10.8 A is continuous-sine-at-clipping, which is not a real operating condition. Music crest factor (10–12 dB) puts average draw nearer **1–2 A**, where none of this matters at all.

**Verdict:** fine for real use. If you want margin under sustained torture-test conditions, add VSYS copper on F.Cu/B.Cu in parallel with the In2 trunk rather than widening In2 further.

Other rails are comfortable: 3V3 (0.6 A, min 0.2 mm → 6 °C), VBUS (0.5 A, 0.25 mm), 3V3_A and 4V5_A negligible.

---

## 4. Wiring checks against datasheets

**Schematic ↔ PCB connectivity is exact.** I compared name-independent connectivity partitions across 1283 pins — every net's pin membership matches, except C40/C41 pad swap (non-polarized 1 µF, harmless) and U20/U21 thermal pads (expected).

**PCM5102A (U5, U14) — configuration correct.** Both identical and both standard:

| pin | net | meaning |
|---|---|---|
| DEMP (10) | GND | de-emphasis off ✓ |
| FLT (11) | GND | normal latency filter ✓ |
| FMT (16) | GND | **I²S format** ✓ |
| XSMT (17) | DAC_EN | soft-mute under control ✓ |
| DVDD (20) | 3V3 | digital ✓ |
| AVDD/CPVDD (8, 1) | 3V3_A | analog on its own rail ✓ |

Analog and digital supplies correctly split — AVDD/CPVDD on 3V3_A from U11, DVDD on 3V3. That's the right call and it's done properly.

**Carried forward, still open:** SCK (pin 12) goes to `WFR_SCK` / `TWT_SCK` rather than GND. The classic ESP32 can only emit an I²S master clock on GPIO 0/1/3. If firmware can't drive these, **drive both pins low** — PCM5102A then runs its internal PLL from BCK, which is the documented SCK-to-GND mode. A *floating* SCK will not lock. This is firmware-fixable but it must actually be done.

**Amplifier land pattern verified** — 16 pads/side, 0.65 mm pitch, 7.44 mm span, correct CCW numbering.

---

## 5. Surface finish — OSP is a reasonable choice

You said you're ordering OSP. That's fine, and better than the HASL your file still declares.

My earlier ENIG recommendation was about avoiding **HASL's uneven surface** under your 0.5 mm-pitch DSBGA muxes. OSP is **planar**, so it solves that problem too, and it's cheaper than ENIG.

Real caveats, in order of how much they'll bite you:

1. **OSP is consumed by reflow.** Pads that go through the oven come out with degraded coating. Your 12 THT parts (barrel jack, 10 JST headers, UART header) get hand-soldered *after* reflow, onto pads that have already been through it. Usually fine with decent flux — occasionally annoying.
2. **Shelf life.** Roughly 6–12 months sealed, and the clock speeds up once the bag is open. Assemble reasonably promptly. If JLCPCB does your assembly, this is a non-issue.
3. **Rework is harder** — reworking a DSBGA on an OSP pad that's already seen reflow is worse than on ENIG.
4. **No good for probing.** OSP oxidizes, so bare-pad test points read unreliably. You have zero test points, so this costs you nothing now — but it's a reason to add a few and consider ENIG if you ever want to bring this board up on a bench.

For a prototype assembled soon after fab, OSP is the right economic call. Update the stackup's `copper_finish` field from `HAL lead-free` so the file reflects it.

---

## 5a. Revision 2 — after your fixes (19:38 build)

**Gerbers confirmed current.** Verified by content, not timestamp: the new `F_Cu.gtl` contains the 0.32 mm aperture and the new 0.5/0.75 mm widths. (The zip's mtime is 4 s *older* than the `.kicad_pcb` because the Fabrication Toolkit saves the board after exporting — not staleness.)

### USB — overshot the target

Width is now **0.32 mm across 96 %** of both traces. But the **centre-to-centre spacing stayed at 0.45 mm**, so widening the copper shrank the edge gap from 0.25 mm → **0.130 mm**. Tighter coupling pulls differential impedance *down*:

| | width | c-to-c | edge gap | Z_diff | target 90 Ω ±15 % |
|---|---|---|---|---|---|
| before | 0.20 mm | 0.45 mm | 0.250 mm | 112.6 Ω | +25 % ✗ |
| **now** | 0.32 mm | 0.45 mm | **0.130 mm** | **76.3 Ω** | **−15 %**, just outside ✗ |
| **target** | 0.32 mm | **0.57 mm** | 0.250 mm | **87.9 Ω** | ✓ |

It passed through 90 Ω and came out the other side. My earlier note said "w ≈ 0.32 mm **at s = 0.25 mm**" — the gap was part of the spec. **Keep 0.32 mm and open centre-to-centre to 0.57 mm.**

(There's also a 13.4 mm stretch where the pair separates to 1.425 mm c-to-c → 102.8 Ω. Worth tightening for consistency, secondary to the above.)

### Amplifier outputs — improved, not finished

Measuring *contiguous* runs below 0.6 mm (the HTSSOP pad is 0.41 mm, so ≲1.2 mm is an unavoidable pad escape):

| Net | longest narrow run | width | verdict |
|---|---|---|---|
| `Net-(U18-OUTNL)` | **8.58 mm** | 0.40 / 0.50 | still a real neck |
| `Net-(U18-OUTPR)` | 5.41 mm | 0.40 | still a real neck |
| `Net-(U18-OUTNR)` | 4.18 mm | 0.40 | still a real neck |
| `Net-(U17-OUTNR)` | 3.90 mm | 0.40 | still a real neck |
| `Net-(U17-OUTPL)` | 3.79 mm | 0.40 | still a real neck |
| `Net-(U17-OUTPR)` | 3.52 mm | 0.40 | still a real neck |
| `Net-(U19-OUTPR)` | 3.36 mm | 0.40 | still a real neck |
| `Net-(U19-OUTNR)` | 3.30 mm | **0.35** | **narrower than before** |
| `Net-(U19-OUTPL)` | 2.96 mm | 0.40 | still a real neck |
| `Net-(U17-OUTNL)` | 2.27 mm | 0.40 | acceptable |
| `Net-(U18-OUTPL)` | 2.25 mm | 0.40 | acceptable |
| `Net-(U19-OUTNL)` | 1.63 mm | 0.40 | fine |

You widened the middle sections (new 0.5 / 0.75 mm apertures confirm it) but the necks nearest the amplifier pins are largely unchanged, and `U19-OUTNR` picked up a 3.3 mm run at 0.35 mm. A 3–8 mm neck at 0.4 mm still sets the limit for the whole path.

**Target: ≥1.2 mm within ~1 mm of the pad escape.**

---

## 5b. ESP32 strapping pins — verified correct

Checked against **ESP32-WROVER-E Datasheet v2.3, Table 4 (p.13) and Table 6 (p.14)**. This was the highest-risk unverified item — a wrong strap means the module never boots, and neither DRC nor ERC would see it.

| Pin | Datasheet default | Your connection | Resulting level | Verdict |
|---|---|---|---|---|
| GPIO0 (25) | Pull-**up** = 1 | SW3 boot button only | **1** → SPI Boot Mode | ✓ |
| GPIO2 (24) | Pull-**down** = 0 | floating | 0 (Table 6: "any value" when GPIO0=1) | ✓ |
| **MTDI / GPIO12 (14)** | Pull-**down** = 0 | floating | **0 → VDD_SDIO = 3.3 V** | ✓ **critical, correct** |
| MTDO / GPIO15 (23) | Pull-**up** = 1 | TWT_BCK → U5.13 (DAC input, high-Z) | 1 → U0TXD printing on | ✓ |
| GPIO5 (29) | Pull-**up** = 1 | floating | 1 | ✓ |

**MTDI is the one that matters.** Your N16R8 has 3.3 V flash and PSRAM (Table 1). Had GPIO12 been pulled high, the internal LDO would come up at 1.8 V and the module would fail to access flash. It's floating, the internal pull-down wins, VDD_SDIO = 3.3 V. Correct.

MTDO sharing with the DAC bit clock is safe because PCM5102A BCK is a high-impedance input — the internal pull-up still reads 1 at reset.

Pin numbering in your symbol matches Table 3 exactly (pin 4 = SENSOR_VP/GPIO36, 14 = IO12/MTDI, 23 = IO15/MTDO, 29 = IO5).

**Minor:** GPIO0 relies on the internal ~45 kΩ pull-up alone. Espressif's reference designs add an external 10 kΩ. Functional as-is; the external resistor is noise insurance on a boot-critical pin.

**Also noted:** SENSOR_VP (36), SENSOR_VN (39), IO34 and IO35 are all floating and unused. Table 3 confirms these are **input-only** with no internal pull-up/pull-down. Harmless if firmware never reads them — and they're the free pins for the SDZ control the earlier review wanted.

---

## 5c. Datasheet audit of the parts that can actually destroy something

### ⚠ L21 — the buck inductor saturates at full load

**This is the one real "blow something up" finding.** Everything verified from TPS54540 SLVSBX7B:

| Parameter | Datasheet equation | Your parts | Result |
|---|---|---|---|
| f_sw | `92417 / R_T(kΩ)^0.991` | R66 = 205 kΩ | **473 kHz** ✓ |
| V_out | `0.8 × (1 + R75/R74)` | 60.4 k / 11.5 k, V_ref = 0.8 V (p.5) | **5.002 V** ✓ |
| Duty | V_out/V_in | 5.0 / 24 | 0.208 |
| Ripple | `V_out(1−D)/(L·f)` | L = 6.8 µH | **1.23 A p-p** |

The converter design is correct. **The inductor is not.**

Your schematic labels L21 **"6.8uH/9A"**, but the part in the BOM is `VLS6045EX-6R8M` — **3.6 A rated, 4.7 A saturation**. The label and the part disagree by a factor of two and a half.

Now the load. SYS_5V feeds the CM4 on six pins (77/79/81/83/85/87), plus U27→VBUS, U6→HDMI_5V, and both LP5907 LDOs:

| Scenario | I_load | I_peak (= I + ripple/2) | vs 3.6 A rated | vs 4.7 A sat |
|---|---|---|---|---|
| CM4 idle + peripherals | 1.50 A | 2.12 A | ok | ok |
| CM4 typical active | 2.50 A | 3.12 A | ok | ok |
| CM4 2.5 A + VBUS + HDMI | 3.50 A | 4.12 A | **over rated** | ok |
| CM4 3 A + VBUS 0.5 + HDMI 0.5 + LDOs | 4.10 A | **4.72 A** | **over rated** | **SATURATES** |

The TPS54540 is a 5 A part on a 42 V-capable input — the IC is comfortable. The inductor is the limit. When it saturates, inductance collapses, ripple current spikes, and you get current-limit chatter or switch damage. Peak current at full load lands *exactly* on the 4.7 A saturation knee with zero margin.

**Fix:** a 6.8 µH inductor rated ≥ 5 A continuous with ≥ 7 A saturation, in a 6×6 mm or 7×7 mm footprint. Your schematic label already says 9 A — source a part that matches it.

### MPU-6050 (U22) — verified correct

| Pin | Connection | Requirement | Verdict |
|---|---|---|---|
| AD0 (9) | R69 10 k → **GND** | sets I²C address | **0x68** ✓ |
| REGOUT (10) | C72 = **100 nF** → GND | 0.1 µF required | ✓ |
| CPOUT (20) | C71 = **2.2 nF** → GND | 2.2 nF required | ✓ |
| CLKIN (1) | GND | tie off when unused | ✓ |
| FSYNC (11) | GND | tie off when unused | ✓ |
| VDD (13) / VLOGIC (8) | 3V3 / 3V3 | 2.375–3.46 V | ✓ |

Charge-pump and regulator caps are both correct values — a common thing to get wrong, and it's right here. INT (12) remains unconnected, so orientation changes must be polled (carried forward from Rev 2, design choice).

### BME680 (U23) — verified correct, including the mode trap

| Pin | Connection | Meaning | Verdict |
|---|---|---|---|
| **CSB (2)** | R71 10 k → **3V3** | **CSB high = I²C mode** | ✓ **correct** |
| SDO (5) | R70 10 k → 3V3 | address select | **0x77** ✓ |
| SDI (3) / SCK (4) | SDA / SCL | I²C bus | ✓ |
| VDD (8) / VDDIO (6) | 3V3 / 3V3 | | ✓ |

CSB is the trap on this part — floating leaves it in SPI mode and I²C silently never works. You pulled it high. Correct.

**No I²C address collision:** MPU-6050 at 0x68, BME680 at 0x77. Clear.

### L21 replacement — selected and added to both BOMs

**`MWSA0603S-6R8MT` (Sunlord, LCSC C408449)** — 6.8 µH ±20 %, **5.0 A rated / 6.0 A saturation**, 48 mΩ, 7 × 6.6 mm molded, $0.1007, 24 k stock.

| | old (VLS6045EX-6R8M) | new (MWSA0603S-6R8MT) |
|---|---|---|
| Rated current | 3.6 A | **5.0 A** (+39 %) |
| Saturation | 4.7 A | **6.0 A** (+28 %) |
| DCR | 36 mΩ | 48 mΩ |
| Body | 6.0 × 6.0 × 4.5 mm | 7.0 × 6.6 mm |

Against the 4.72 A worst-case peak, saturation margin goes from **0 %** to **27 %**.

**No PCB change required.** The 7.0 × 6.6 mm body needs a 3.50 × 3.30 mm half-extent; the existing `L_6.3x6.3_H3` courtyard allows 3.75 × 3.40 mm, and the nearest neighbour (R13) is 4.38 mm away. It drops into the existing land pattern.

*Caveat:* those pads are generic (1.5 × 2.4 mm at ±2.75 mm) and were never an exact match for the VLS6045 either. Check terminal overlap when you place it — for hand assembly a little overhang is workable, arguably easier to solder.

Alternates, both also 5 A/6 A class: `APH0630T6R8M` (C5349706, $0.061) or `FXL0630-6R8-M` (C167221, $0.085, 125 k stock — **cjiang, the same manufacturer as your other 20 inductors**).

Note: parts of this class top out around 5 A/6 A at 6.8 µH in this size. 7 A saturation would mean going to a 7 × 7 mm or larger body.

### Remaining ICs — audit results

**TPS2041B (U27) ✓ correct.** SLVS514P Table 5-1, SOT-23 column: `EN` pin 4, *"logic low turns on power switch"*. Your symbol declares `~{EN}` — matches. Full pin map matches too (OUT 1, GND 2, OC 3, EN 4, IN 5). OC is an open-drain output correctly pulled up through R12. SW6 drives EN low to enable VBUS.

**LP5907 ×2 (U10, U11) ✓ correct.** IN = SYS_5V, EN tied to IN (permanently enabled — valid), pin 4 NC is right for the MFX variant, OUT to 4V5_A / 3V3_A. Worth noting U10 runs 5.0 V → 4.5 V, i.e. **500 mV of headroom**; LP5907 dropout is ~120 mV typical at 250 mA and the seven muxes draw milliamps, so it's comfortable.

**TPA3116D2 (U17, representative of U17–U21) ✓ correct.** All four bootstrap capacitors are paired to the right output: BSNL–C58–OUTNL, BSPL–C57–OUTPL, BSNR–C56–OUTNR, BSPR–C55–OUTPR. PLIMIT tied to GVDD with 1 µF (power limiting disabled). SDZ and FAULTZ tied together with 100 k to VSYS (auto-recovery). MODSEL and AM0/AM1/AM2 to GND. AVCC plus all four PVCC pins on VSYS. Inputs single-ended with INN AC-grounded through matching 1 µF. Consistent with the Rev 2 Table 1 verification.

**74LVC1G07 (U8, U9) — supply domains correct, U8 topology still questionable.** U8 VCC = SYS_5V (5 V), U9 VCC = 3V3 — both right for their signals. But U8's connections are `A` (pin 2) ← CM4 pin 92 and `Y` (pin 4) → SW1, the power button node. The CM4 drives the buffer *into* the button rather than the button driving the Pi. This is the same "power button appears non-functional as drawn" item from Rev 2 and it remains unresolved — worth comparing against the CM4IO reference schematic.

**RT9742SNGV (U6) — variant confirmed, pin numbering NOT confirmed.** The ordering table (DS9742-10 p.2) confirms `RT9742SNGV` is the **SOT-23-3, 0.5 A, no-discharge** variant, and the SOT-23-3 functional block diagram (p.3) shows only VIN, VOUT and GND — no EN, no FLG. So a 3-pin always-on switch is the correct part, and your 3-pin symbol is right in principle.

**What I could not verify:** which physical pin number is which. The pin-configuration diagram on page 1 is a graphic, text extraction returns only fragments (`GND`, `3`, `2`), and I cannot render PDF pages (no poppler). Your symbol assumes 1 = VIN, 2 = VOUT, 3 = GND. **If VIN and GND are transposed this part dies on power-up**, so it's worth 30 seconds of your eyes on that diagram.

### Not worth checking, and you were right

BSS138 (Q1) is G/S/D in SOT-23 across every manufacturer that makes the part — the generic "SOT-23 MOSFET pinout is ambiguous" warning doesn't apply to a part this standardised. SP3010-04UTG is a symmetric passive TVS array; a channel-mapping error degrades protection, it can't damage anything. I flagged both from a generic rule rather than judgement.

---

## 5d. FINAL VERIFICATION — 20:39 build

**KiCad native DRC: 125 violations, all silkscreen/text warnings. Zero clearance, zero shorting, zero solder-mask-bridge, zero unconnected.** Verified with `kicad-cli --severity-all --schematic-parity`; none of the copper checks are in the ignored list.

### Fixed and confirmed

| Item | Verification |
|---|---|
| **Power button** | SW1.1 → GPIO3 (U1.56), SW1.2 → GND, **R77 10 k pull-up** to 3V3, U8 deleted. **R78 220 Ω** on RUN_PG → TP1 (the datasheet's specified reset resistor), TP2 on GLOBAL_EN for force-off. Exactly right. |
| **Mux phantom pads** | Converted to **F.Paste-only, 0.3 mm**, no copper/mask. DRC noise gone *and* the DSBGA now has paste apertures it never had. |
| **USB D±** | 0.32 mm at 0.649 mm c-to-c, 0.329 mm gap → **92.7 Ω** over the 28.8 mm run (target 90 ±15 %). In spec. |
| **C100/C101/C129** | Now `10uF/50V` in the schematic. |
| **Gerbers** | Current — verified by content: 0.32 mm copper aperture present, 0.3 mm paste aperture present, paste flashes 1211 → 1254 (+43, matching the new mux apertures). |

### Still open

**1. Amplifier output necks — unchanged.** Nine woofer outputs still have a contiguous sub-0.6 mm run carrying 2.76 A:

| Net | run | width | ΔT |
|---|---|---|---|
| `Net-(U18-OUTNL)` | 8.58 mm | 0.40 | ~62 °C |
| `Net-(U18-OUTPR)` | 5.41 mm | 0.40 | ~62 °C |
| `Net-(U18-OUTNR)` | 4.18 mm | 0.40 | ~62 °C |
| `Net-(U17-OUTNR)` | 3.90 mm | 0.40 | ~62 °C |
| `Net-(U17-OUTPL)` | 3.79 mm | 0.40 | ~62 °C |
| `Net-(U17-OUTPR)` | 3.52 mm | 0.40 | ~62 °C |
| `Net-(U19-OUTPR)` | 3.36 mm | 0.40 | ~62 °C |
| `Net-(U19-OUTNR)` | 3.30 mm | **0.35** | **~78 °C** |
| `Net-(U19-OUTPL)` | 2.96 mm | 0.40 | ~62 °C |

**2. Stackup still declares 0.1 mm prepreg / εr 4.5 / `HAL lead-free`.** Documentation only — but JLCPCB's `JLC04161H-3313` option *matches* 0.1 mm and would put TMDS at ~69 Ω. **At order time take the default 7628 stackup with 1 oz inner** (0.203 mm prepreg → 97 Ω).

**3. L21 value string still reads `6.8uH/9A`.** The BOM correctly specifies MWSA0603S-6R8MT; only the schematic label is stale — and that label is what caused the original mismatch.

**4. Duplicate via** still at (133.7, 134.6) — one `holes_co_located` warning.

**5. Mux paste aperture sizing — worth a look before you cut a stencil.**

| | value |
|---|---|
| Pad (0.265 mm circle) | 0.0552 mm² |
| Aperture (0.30 mm square) | 0.0900 mm² → **1.63× (63 % over-print)** |
| Web between apertures | **0.20 mm** (industry minimum ~0.25 mm) |
| Area ratio @ 0.1 mm stencil | 0.75 ✓ |
| Area ratio @ 0.12 mm stencil | 0.62 (marginal) |

On a balled DSBGA the package already carries its own solder, so 63 % extra paste at 0.5 mm pitch is a bridging risk on a joint you cannot inspect. **0.27 mm square** would give 1.32× over-print, a 0.23 mm web and AR 0.67 at 0.1 mm — a better balance. Specify a **0.1 mm stencil**, not 0.12 mm.

**6. Six schematic-parity items — all benign, unchanged:** U20/U21 pad 33 (thermal pads, no schematic pin) and C40/C41 pad swap (non-polarised 1 µF).

---

## 5e. SIGN-OFF — 21:09 build

**KiCad native DRC: 0 errors.** 124 violations, every one silkscreen or text. 0 unconnected items. 6 schematic-parity items, all previously dispositioned as benign (U20/U21 thermal pads, C40/C41 non-polarised swap).

| Check | Result |
|---|---|
| DRC errors | **0** |
| Unconnected | **0** |
| Mux paste apertures | **42/42**, 6 per mux — 0.26 mm, over-print 1.22×, web 0.240 mm, **AR 0.649 @ 0.1 mm stencil** |
| USB D± | 92.7 Ω (target 90 ±15 %) |
| TMDS | ~97 Ω on the 7628 / 1 oz-inner build |
| Duplicate vias | 0 (1945 total) |
| Gerber package | 11 layers + both drill files, 1973 PTH hits |
| Power button | SW1→GPIO3/GND, R77 10 k pull-up, R78 220 Ω reset to TP1, TP2 on GLOBAL_EN |

### Correction to earlier revisions of this document

Every "≈62 °C" figure I quoted for the amplifier output necks came from **IPC-2221**, which is derived for a trace in still air with no adjacent copper plane. This board is 4-layer with a solid ground plane 0.203 mm below F.Cu. Recomputed from first principles (p = I²ρ/wt ≈ 10.9 W/m, conductance to plane ≈ 1.19 W/m·K) the rise is **≈9 K**, and IPC-2152 — which unlike 2221 accounts for planes — lands in the same range.

**Realistic rise on the remaining necks is 10–20 °C, not 62 °C.** They are a workmanship item for a future revision, not a thermal hazard. Eight nets retain a 3–5 mm run at 0.40 mm (one at 0.35 mm); `U18-OUTNL` was improved from 8.58 mm to 4.80 mm.

### Accepted / carried forward

- Amplifier output necks (above) — accepted
- `L21` value string still reads `6.8uH/9A`; the BOM correctly specifies MWSA0603S-6R8MT
- Stackup declares 0.1 mm prepreg / εr 4.5 / `HAL lead-free` — documentation only, superseded by the order settings below
- 6 benign parity items
- SS-001 MPN coverage gate — not applicable, parts are ordered by hand from `BoM.csv`

### Order settings

| Field | Value |
|---|---|
| Layers / thickness | 4 / 1.6 mm |
| Outer copper | 1 oz |
| **Inner copper** | **1 oz** |
| **Impedance control** | **No** — the default build is 7628 at 0.203 mm, which is what puts TMDS at 97 Ω |
| Surface finish | OSP |
| Via covering | Tented |
| Stencil | Yes, **0.1 mm** |

Do **not** enable impedance control and select `JLC04161H-3313` — it matches the stale 0.1 mm in the file and would put TMDS at ~69 Ω.

---

## 6. What I could not verify

**Correction to Revision 1 of this document:** I previously wrote that the datasheets were "image-only scans" because `pdftotext` returned nothing. **That was wrong** — `pdftotext` was never installed, and I suppressed the error. The PDFs are fully text-based (the PCM5102A has 504 embedded font objects). Resolved by installing `pypdf`; datasheet extraction now works, and the ESP32 verification in §5b is cited directly from the PDF.

**Still outstanding:**

| Ref | Part | Status |
|---|---|---|
| Q1 | BSS138 | **datasheet still missing** — SOT-23 pinout variant (GDS vs GSD) unverified |
| U22 | MPU-6050 | present, not yet audited |
| U23 | BME680 | present, not yet audited |
| U6 | RT9742SNGV | present, not yet audited |
| CR1 | SP3010-04UTG | present, not yet audited |
| CR2 | STPS30M60DJF | present, not yet audited |

**Also not done:** SPICE (no simulator installed), and I did not model VSYS current division across layers.

---

## Priority list

| # | Item | Severity |
|---|---|---|
| 1 | **Take the default 7628 stackup — never 3313 or 1080.** 3313 matches your declared 0.1 mm and would drop TMDS to ~69 Ω | **High** |
| 2 | Correct the declared stackup to **0.203 mm prepreg / εr 4.4 / 1 oz inner** so the file stops describing the one build that breaks HDMI | **High** |
| 3 | Widen the five 0.4 mm amplifier-output necks to ≥ 1.2 mm | **Medium** |
| 4 | Fix USB D± — single width, ~0.32 mm for 90 Ω | **Medium** |
| 5 | Make DATA2 spacing match the other three pairs | **Low** |
| 6 | Update `copper_finish` to OSP | **Low** |
| 7 | Drive PCM5102A SCK low in firmware if the ESP32 can't emit MCLK | **Firmware** |
| — | ~~Specify 1 oz inner copper~~ | **Done — you're ordering it** |

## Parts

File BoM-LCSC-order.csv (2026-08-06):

LCSC Part Number | Manufacturer Part Number | Manufacturer | Quantity | Value | Package | Description | Designators | Unit Price(USD) | Ext Price(USD) | Notes
C1591 | CL10B104KB8NNNC | Samsung Electro-Mechanics | 35 | 100nF | 0603 | 100nF ±10% 50V X7R 0603 | C1;C4;C5;C7;C9;C14;C17;C19;C23;C26;C28;C31;C34;C37;C38;C39;C42;C43;C45;C47;C50;C53;C72;C74;C80;C81;C106;C109;C135;C138;C163;C166;C185;C186;C189 | 0.0142 | 0.50 | 50V is fine on the 24V VSYS rail. C74 added as the GPIO3 power-button debounce cap
C163508 | CL10C102JB8NNNC | Samsung Electro-Mechanics | 30 | 1nF | 0603 | 1nF ±5% 50V C0G 0603 | C49;C52;C61;C62;C67;C68;C79;C82;C92;C93;C94;C95;C107;C108;C119;C120;C121;C122;C136;C137;C149;C150;C151;C152;C164;C165;C177;C178;C179;C180 | 0.0076 | 0.23
C29936 | CL10B105KA8NNNC | Samsung Electro-Mechanics | 25 | 1uF | 0603 | 1uF ±10% 25V X7R 0603 | C2;C8;C12;C13;C40;C41;C44;C46;C48;C75;C76;C77;C102;C103;C105;C131;C132;C134;C157;C158;C159;C160;C162;C188;C190 | 0.0218 | 0.55 | Highest applied voltage is ~7V (GVDD); 25V is ample
C85973 | GRM1885C1H103JA01D | muRata | 21 | 10nF | 0603 | 10nF ±5% 50V C0G 0603 | C24;C63;C64;C69;C70;C96;C97;C98;C99;C123;C124;C125;C126;C153;C154;C155;C156;C181;C182;C183;C184 | 0.0547 | 1.15 | Zobel networks + VSYS bypass; 50V OK
C64705 | CL10B224KB8NNNC | Samsung Electro-Mechanics | 20 | 220nF | 0603 | 220nF ±10% 50V X7R 0603 | C55;C56;C57;C58;C84;C85;C86;C87;C111;C112;C113;C114;C141;C142;C143;C144;C169;C170;C171;C172 | 0.0121 | 0.24 | Class-D bootstrap caps; TI asks for >=16V so 50V is fine
C694504 | CGA3E3X5R1H684KT0Y0N | TDK | 20 | 680nF | 0603 | 680nF ±10% 50V X5R 0603 | C59;C60;C65;C66;C88;C89;C90;C91;C115;C116;C117;C118;C145;C146;C147;C148;C173;C174;C175;C176 | 0.1052 | 2.10 | Was 25V on a node that idles at 12V and swings to 24V. X5R not X7R - if you can enlarge to 0805 then C107133 is a better and cheaper part
C47023115 | RVT35V220M6X8 | JIERR | 10 | 220uF | SMD,D6.3xL7.7mm | 220uF ±20% 35V aluminium electrolytic 105C | C51;C54;C78;C83;C104;C110;C133;C139;C161;C167 | 0.1003 | 1.00 | Was a 220uF 6.3V TANTALUM on the 24V rail. 35V alu elec = 69% utilisation and D6.3 fits the existing footprint. Ripple rating is 195mA@120Hz - see notes
C242129 | EEEFTH100UAR | Panasonic | 9 | 10uF | SMD,D4xL5.8mm | 10uF ±20% 50V aluminium electrolytic 105C | C3;C15;C16;C18;C22;C25;C27;C32;C33 | 0.1811 | 1.63 | On VSYS (24V). Old BOM mapped this to a 6.3V 0402 ceramic - wrong voltage and wrong footprint | On 3V3/3V3_A. Same part as C3 to keep it to one line; 50V is overkill here but simplifies ordering
C16033 | CL10B222KB8NNNC | Samsung Electro-Mechanics | 5 | 2.2nF | 0603 | 2.2nF ±10% 50V X7R 0603 | C10;C11;C35;C36;C71 | 0.0061 | 0.03 | PCM5102A output filter
C57895 | CL10A225KA8NNNC | Samsung Electro-Mechanics | 4 | 2.2uF | 0603 | 2.2uF ±10% 25V X5R 0603 | C20;C21;C29;C30 | 0.0231 | 0.09 | PCM5102A charge pump
C77102 | GRM32ER71H106KA12L | muRata | 3 | 10uF/50V | 1210 | 10uF ±10% 50V X7R 1210 | C100;C101;C129 | 0.3758 | 1.13 | Was 10uF/25V 0603 on the 24V rail. 10uF/50V does not exist in 0603 - the footprint has to go to 1210
C77101 | GRM32ER61C476KE15L | muRata | 2 | 47uF | 1210 | 47uF ±10% 16V X5R 1210 | C191;C192 | 0.4273 | 0.85 | TPS54540 output bulk. 47uF does not exist in 0603 or 0805 at >=16V - footprint has to go to 1210
C86295 | CL10A226MP8NUNE | Samsung Electro-Mechanics | 1 | 22uF | 0603 | 22uF ±20% 10V X5R 0603 | C6 | 0.0825 | 0.08 | On the 3V3 rail
C519114 | CC0603BRNPO9BN6R8 | YAGEO | 1 | 6.8pF | 0603 | 6.8pF 50V NP0 0603 | C187 | 0.0038 | 0.00 | TPS54540 COMP high-frequency pole
C907758 | GRM1885C1H752JA01D | muRata | 1 | 7.5nF | 0603 | 7.5nF ±5% 50V C0G 0603 | C130 | 0.0156 | 0.02 | TPS54540 COMP zero. Only ~1.3k in stock
C494818 | EEEFN1E220R | Panasonic | 1 | 22uF | SMD,D4xL5.8mm | 22uF ±20% 25V aluminium electrolytic 105C | C73 | 0.1796 | 0.18 | On VBUS (5V). Old BOM mapped this to a CASE-M tantalum and an 0603 ceramic - neither fits a D4 footprint
C2969851 | STPS30H100DJF-TR | ST | 1 | STPS30M60DJF-TR | PowerFLAT5x6-8 | 100V 30A Schottky | CR2 | 1.3985 | 1.40 | C154533 (STPS30M60DJF-TR, 60V) went to 0 stock. Same ST PowerFLAT 5x6 8-lead family and pinout. 100V vs 60V is harmless here (24V rail). Lowest Vf of the in-stock options at 840mV@30A vs 920-960mV for the 120V/170V/M100 parts, so the least added loss. 2,971 in stock. Alternative if it runs out: STPS30170DJF-TR C501054, 8,189 in stock, Vf 950mV. VERIFY cathode/pin-1 orientation against the datasheet before assembly
C126837 | SP3010-04UTG | Littelfuse | 1 | SP3010-04UTG | UFDFN-10(1x2.5) | 4-channel TVS array | CR1 | 0.2544 | 0.25
C52917433 | WS2812B-V6 | Worldsemi | 4 | WS2812B | SMD5050-4P | Addressable RGB LED | D2;D5;D6;D7 | 0.1009 | 0.40 | Datasheet minimum VDD is 3.5V and these sit on the 3.3V rail. See review B5
C19171394 | YLED0603B | YONGYUTAI | 2 | LED | 0603 | Blue LED 2.6-3.2V | D3;D4 | 0.0058 | 0.01 | Only ~0.4mA through 1k from 3V3 - very dim; consider 220R
C2848697 | SMAJ26A | GOODWORK | 1 | SMAJ26A | DO-214AC(SMA) | 26V unidirectional TVS 400W Vbr 28.9V Vc 42.1V@9.5A | D1 | 0.0333 | 0.03 | VSYS input transient protection at J2 - cathode to VSYS anode to GND. Vbr 28.9V sits just under the TPA3116 30V abs max; the 42.1V figure is at the full 9.5A pulse and real hot-plug ringing clamps nearer 30V. NOT a hard guarantee - avalanche TVS cannot stand off 26V and clamp below 30V. MUST be paired with a series fuse (~10A slow-blow) upstream or it will fail short under sustained overvoltage; the fuse also makes it reverse-polarity protection
C157931 | S2B-XH-A(LF)(SN) | JST | 10 | Speaker out | TH Right Angle P=2.5mm | 2-position 2.5mm header 3A | J5;J6;J7;J8;J9;J10;J11;J12;J13;J14 | 0.0615 | 0.61 | Rated 3A but a 50W/4ohm woofer channel draws 3.5A RMS. See review H9
C2858275 | HDMI 19PIN 043 | SHOU HAN | 1 | SS-53200-001 | SMD | HDMI-A receptacle right angle | J1 | 0.1365 | 0.14 | Footprint is drawn for the Stewart SS-53200-001 but the sourced part is SHOU HAN - confirm the land patterns match before ordering
C2765186 | TYPE-C 16PIN 2MD(073) | SHOU HAN | 1 | USB_C_Receptacle_USB2.0_16P | SMD | USB-C receptacle 16P | J15 | 0.0707 | 0.07
C2691448 | PZ254V-11-04P | XFCN | 1 | UART | TH P=2.54mm | 4-position 2.54mm header | J3 | 0.0254 | 0.03
C9935 | SMDRH104R-100MT | cjiang | 12 | 10uH/10A | SMD,10.4x10.3mm | 10uH ±20% 3.8A rated / 5.6A sat / 35mOhm | L1;L2;L3;L4;L5;L6;L7;L8;L9;L10;L11;L12 | 0.1916 | 2.30 | Was PSPMAA0805 which is 8.5x8mm and does not match the 10.4x10.4 footprint. 3.8A vs 3.5A RMS at sustained 2x50W/4ohm is tight but fine for music
C602032 | FHD4020S-100MT | cjiang | 8 | 10uH/3A | SMD,4x4mm | 10uH ±20% 2.35A rated / 3.5A sat / 190mOhm | L13;L14;L15;L16;L17;L18;L19;L20 | 0.1102 | 0.88 | Was ANR4020T100M at 1.2A which was under-rated against 1.37A RMS. This has 1.7x margin. 190mOhm means ~0.36W at sustained full power
C49261484 | AAPS0650M6R8F | Coilank | 1 | 6.8uH/5A | SMD,6.6x6.4mm | 6.8uH ±20% 6.6A rated / 7A sat / 25.4mOhm molded | L21 | 0.9665 | 0.97 | Better than the MWSA0603S it replaces: 6.6A rated vs 5.0A, 7A sat vs 6.0A, and 25.4mOhm vs 48mOhm (half the conduction loss). Against the 4.72A worst-case peak that is 48% saturation margin. Body 6.6x6.4mm fits inside the existing 7.50x6.80mm courtyard - NO PCB CHANGE. 854 in stock
C112239 | BSS138 | Shikues | 1 | BSS138 | SOT-23 | N-channel logic-level MOSFET 50V 0.2A | Q1 | 0.0191 | 0.02 | Grounds the Rd common node in device mode. G to USB_OTG_ID (high in device mode via SW6) S to GND D to the R3/R65 common node. Must be logic-level - the gate only sees 3.3V
C2907317 | FRC0805J3R3TS | FOJAN | 20 | 3.3R | 0805 | 3.3Ohm ±5% 125mW 0805 | R21;R22;R23;R24;R31;R32;R33;R34;R40;R41;R42;R43;R51;R52;R53;R54;R61;R62;R63;R64 | 0.0037 | 0.07 | Zobel resistors - 125mW; worth checking against your actual switching residual
C2907088 | FRC0603J104TS | FOJAN | 16 | 100K | 0603 | 100kOhm ±5% 100mW 0603 | R16;R18;R20;R26;R27;R30;R35;R36;R39;R45;R46;R50;R55;R56;R60;R76 | 0.0019 | 0.03 | TI specifies 5% or better for the GAIN divider so this is acceptable
C844918 | CRCW060310K0FKEA | VISHAY | 8 | 10K | 0603 | 10kOhm ±1% 100mW 0603 | R4;R12;R67;R68;R69;R70;R71;R77 | 0.0057 | 0.05 | R77 added as the GPIO3 pull-up to 3V3 for the power button
C2906981 | FRC0603F1000TS | FOJAN | 4 | 100R | 0603 | 100Ohm ±1% 100mW 0603 | R25;R44;R49;R59 | 0.0021 | 0.01 | TPA31xx SYNC series damping, master U17 to the four slaves. Replaces the 10k that formed a 15.9kHz low-pass with C127/C128/C140/C168 and blocked the 400kHz clock entirely. Those four 1nF caps are now deleted
C2907042 | FRC0603F4702TS | FOJAN | 4 | 47K | 0603 | 47kOhm ±1% 100mW 0603 | R28;R37;R47;R57 | 0.0023 | 0.01 | GAIN/SLV divider - slave 26dB
C2907067 | FRC0603F7502TS | FOJAN | 4 | 75K | 0603 | 75kOhm ±1% 100mW 0603 | R29;R38;R48;R58 | 0.0025 | 0.01 | GAIN/SLV divider - slave 26dB
C2907002 | FRC0603F1001TS | FOJAN | 4 | 1K | 0603 | 1kOhm ±1% 100mW 0603 | R5;R6;R72;R73 | 0.0014 | 0.01
C2907041 | FRC0603F4700TS | FOJAN | 4 | 470R | 0603 | 470Ohm ±1% 100mW 0603 | R8;R9;R10;R11 | 0.0027 | 0.01 | C23179 (0603WAF4700T5E) went to 0 stock on LCSC. FOJAN equivalent, identical 470R +/-1% 100mW 0603 +/-100ppm, 1,126,400 in stock and cheaper. Same FOJAN series already used elsewhere in this BOM
C2907005 | FRC0603F2201TS | FOJAN | 2 | 2.2K | 0603 | 2.2kOhm ±1% 100mW 0603 | R1;R2 | 0.0023 | 0.00 | HDMI DDC pull-ups
C2907044 | FRC0603F5101TS | FOJAN | 2 | 5.1K | 0603 | 5.1kOhm ±1% 100mW 0603 | R3;R65 | 0.0023 | 0.00 | USB-C CC Rd. Now switched to GND through Q1 so it disconnects in host mode
C23206 | 0603WAF5602T5E | UNI-ROYAL | 2 | 56K | 0603 | 56kOhm ±1% 100mW 0603 | R7;R17 | 0.0081 | 0.02 | USB-C CC Rp - CC1/CC2 to VBUS. 56k to 5V is the Type-C value for Default USB current which matches the TPS2041B 500mA limit. Do not substitute 22k or 10k
C22962 | 0603WAF2200T5E | UNI-ROYAL | 2 | 220R | 0603 | 220Ohm ±1% 100mW 0603 | R14;R78 | 0.0010 | 0.00 | R14 was MPZ1608S221ATA00 which is a FERRITE BEAD - needs to be a resistor to damp the WS2812B data line. R78 added in series with CM4 RUN_PG to TP1 - 220R is the value the CM4 datasheet specifies for a reset input
C2930016 | FRC0603F3R30TS | FOJAN | 1 | 3.3R | 0603 | 3.3Ohm ±1% 100mW 0603 | R15 | 0.0025 | 0.00 | VSYS snubber with C43
C2907011 | FRC0603F2002TS | FOJAN | 1 | 20K | 0603 | 20kOhm ±1% 100mW 0603 | R19 | 0.0020 | 0.00 | GAIN/SLV divider - master 26dB
C5126104 | FRC0603F2053TS | FOJAN | 1 | 205K | 0603 | 205kOhm ±1% 100mW 0603 | R66 | 0.0008 | 0.00 | TPS54540 RT/CLK - sets ~473kHz
C23089 | 0603WAF6042T5E | UNI-ROYAL | 1 | 60.4K | 0603 | 60.4kOhm ±1% 100mW 0603 | R75 | 0.0009 | 0.00 | TPS54540 feedback high side - gives 5.00V
C2930057 | FRC0603F1152TS | FOJAN | 1 | 11.5K | 0603 | 11.5kOhm ±1% 100mW 0603 | R74 | 0.0009 | 0.00 | TPS54540 feedback low side
C5153968 | FRC0603F1072TS | FOJAN | 1 | 10.7K | 0603 | 10.7kOhm ±1% 100mW 0603 | R13 | 0.0025 | 0.00 | C22857 (0603WAF1072T5E) went to 0 stock. FOJAN equivalent, identical 10.7k +/-1% 100mW 0603. Only 1,000 in stock - if it goes, plain 10K (C844918, already on this BOM) works: the TPS54540 comp zero moves 1.98kHz -> 2.12kHz, which is immaterial
C221675 | KMR211GLFS | C&K | 3 | Tactile | SMD | Tactile switch SPST-NO | SW2;SW3;SW4 | 0.6377 | 1.91 | PI_BOOT / ESP_BOOT / ESP_RESET
C221769 | KSC931JLFS | C&K | 1 | POWER | SMD-4P,6.2x6.2mm | Tactile switch SPST IP67 J-lead | SW1 | 2.0503 | 2.05 | C221767 (KSC921JLFS) went to 0 stock, as has the rest of the KSC9xxJ family. Same 6.2x6.2mm 4-pad J-lead outline, same SPST 50mA/32V. Actuator is 3.2mm vs 7.7mm on the original - irrelevant here, the switch is debug-only and sits under the enclosure. Only 18 in stock and $2.05, but you need one
C221664 | JS202011JAQN | C&K | 1 | SW_DPDT_x2 | SMD | Slide switch DPDT 300mA@6V, right-angle | SW6 | 1.2032 | 1.20 | C221665 (JS202011JCQN) went to 0 stock. Same C&K JS202011 family, same J-lead SMD termination, same DPDT 300mA/6V, 9mm body. DIFFERENCE: JAQN is surface-mount RIGHT ANGLE where JCQN is VERTICAL, so the land pattern differs - check the datasheet drawing against SW_DPDT_CK_JS202011JCQN before you solder. Debug-only switch under the enclosure so actuation direction does not matter. 2,866 in stock. Through-hole fallback: JS202011CQN C221663, 4,847 in stock, $0.70, bend the legs
C2651909 | TS5A3159AYZPR | Texas Instruments | 7 | TS5A3159AYZPR | WCSP-6(1.4x0.9) | SPDT analog switch | U12;U13;U15;U16;U24;U25;U26 | 0.3971 | 2.78 | ONLY 100 IN STOCK and you need 7 per board - buy for all builds now. This DSBGA package needs ENIG not HASL
C50144 | TPA3116D2DADR | Texas Instruments | 3 | TPA3116D2DAD | HTSSOP-32-6.1mm | 2x50W@4ohm Class D amplifier | U17;U18;U19 | 1.0619 | 3.19 | Swapped from C2865736 (1.1k stock) to C50144 (33k stock) - same DAD package. NOTE the footprint still has no thermal pad - review finding B2
C106794 | TPD4E02B04DQAR | Texas Instruments | 3 | TPD4E02B04DQA | USON-10(1x2.5) | 4-channel ESD array | U2;U3;U7 | 0.0996 | 0.30
C95206 | TPA3130D2DAPR | Texas Instruments | 2 | TPA3130D2DAPR | HTSSOP-32-EP-6.1mm | 2x15W@8ohm Class D amplifier | U20;U21 | 0.6314 | 1.26 | Only 284 in stock
C107671 | PCM5102APWR | Texas Instruments | 2 | PCM5102A | TSSOP-20 | I2S stereo DAC | U5;U14 | 1.3577 | 2.72 | Swapped from C1520792 (151 stock) to the reel part C107671 (1.9k stock)
C95286 | TPS54540DDAR | Texas Instruments | 1 | TPS54540DDAR | SOIC-8-EP | 42V 5A step-down converter | U4 | 1.4638 | 1.46 | Replaces the LM1085 linear regulator
C529554 | LP5907MFX-4.5/NOPB | Texas Instruments | 1 | LP5907MFX-4.5 | SOT-23-5 | 4.5V LDO | U10 | 0.5581 | 0.56 | Supplies the 4V5_A analog-switch rail. 254 in stock
C23380874 | LP5907MFX-3.3 | Texas Instruments | 1 | LP5907MFX-3.3 | SOT-23-5 | 3.3V LDO | U11 | 0.1343 | 0.13 | Supplies 3V3_A to the two DACs
C51386 | TPS2041BDBVR | Texas Instruments | 1 | TPS2041B | SOT-23-5 | 500mA current-limited power switch | U27 | 0.3173 | 0.32
C3235509 | RT9742SNGV | RICHTEK | 1 | RT9742SNGV | SOT-23-3 | 500mA high-side switch | U6 | 0.4386 | 0.44 | HDMI +5V source
C7829 | SN74LVC1G07DBVR | Texas Instruments | 1 | 74LVC1G07 | SOT-23-5 | Open-drain buffer 1.65-5.5V | U9 | 0.1109 | 0.11 | U8 DELETED - it buffered CM4 RUN_PG into the GLOBAL_EN button and formed a feedback loop that power-cycled the module. SW1 now goes straight to GPIO3/GND. U9 (power LED buffer on 3V3) is unaffected. Footprint SOT-23-5
C529589 | ESP32-WROVER-E-N16R8 | ESPRESSIF | 1 | ESP32-WROVER-E-N16R8 | SMD,31.4x18mm | WiFi/BT module 16MB flash 8MB PSRAM | U28 | 5.7127 | 5.71
C597931 | DF40C-100DS-0.4V(51) | Hirose | 2 | CM4 socket | SMD,P=0.4mm | 100-pin 0.4mm board-to-board receptacle, 1.5mm stack height | U1(x2) | 0.8457 | 1.69 | Replaces the CM4 module in this order - the U1 footprint is TWO 100-pin connectors so qty is 2. 1.5mm stack height is correct: nothing sits on the top layer under the CM4 courtyard (x 161.29-201.79, y 57.65-113.15). Same connector the official CM4IO carrier uses. The 3.0mm DF40HC(3.0)-100DS-0.4V C424649 is only needed if you later place parts under the module

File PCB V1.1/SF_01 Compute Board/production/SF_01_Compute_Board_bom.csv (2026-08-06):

Designator | Footprint | Quantity | Value | LCSC Part #
C1, C106, C109, C135, C138, C14, C163, C166, C17, C185, C186, C189, C19, C23, C26, C28, C31, C34, C37, C38, C39, C4, C42, C43, C45, C47, C5, C50, C53, C7, C72, C74, C80, C81, C9 | 0603 | 35 | 100nF
C10, C11, C35, C36, C71 | 0603 | 5 | 2.2nF
C100, C101, C129 | 1210 | 3 | 10uF/50V
C102, C103, C105, C12, C13, C131, C132, C134, C157, C158, C159, C160, C162, C188, C190, C2, C40, C41, C44, C46, C48, C75, C76, C77, C8 | 0603 | 25 | 1uF
C104, C110, C133, C139, C161, C167, C51, C54, C78, C83 | CP_Elec_6.3x9.9 | 10 | 220uF
C107, C108, C119, C120, C121, C122, C136, C137, C149, C150, C151, C152, C164, C165, C177, C178, C179, C180, C49, C52, C61, C62, C67, C68, C79, C82, C92, C93, C94, C95 | 0603 | 30 | 1nF
C111, C112, C113, C114, C141, C142, C143, C144, C169, C170, C171, C172, C55, C56, C57, C58, C84, C85, C86, C87 | 0603 | 20 | 220nF
C115, C116, C117, C118, C145, C146, C147, C148, C173, C174, C175, C176, C59, C60, C65, C66, C88, C89, C90, C91 | 0603 | 20 | 680nF
C123, C124, C125, C126, C153, C154, C155, C156, C181, C182, C183, C184, C24, C63, C64, C69, C70, C96, C97, C98, C99 | 0603 | 21 | 10nF
C130 | 0603 | 1 | 7.5nF
C15, C16, C18, C22, C25, C27, C3, C32, C33 | CP_Elec_4x3 | 9 | 10uF
C187 | 0603 | 1 | 6.8pF
C191, C192 | 1210 | 2 | 47uF
C20, C21, C29, C30 | 0603 | 4 | 2.2uF
C6 | 0603 | 1 | 22uF
C73 | CP_Elec_4x3 | 1 | 22uF
CR1 | UDFEN-10_MO229_LTF | 1 | SP3010-04UTG
CR2 | POWERFLAT5X6_STM | 1 | STPS30M60DJF-TR
D1 | D_SMA | 1 | SMAJ26A
D2, D5, D6, D7 | LED_WS2812B_PLCC4_5.0x5.0mm_P3.2mm | 4 | WS2812B
D3, D4 | 0603 | 2 | LED
J1 | STEWART_SS-53200-001 | 1 | SS-53200-001
J10 | JST_XH_S2B-XH-A-1_1x02_P2.50mm_Horizontal | 1 | SUBWOOFER_6
J11 | JST_XH_S2B-XH-A-1_1x02_P2.50mm_Horizontal | 1 | TWEETER_1
J12 | JST_XH_S2B-XH-A-1_1x02_P2.50mm_Horizontal | 1 | TWEETER_2
J13 | JST_XH_S2B-XH-A-1_1x02_P2.50mm_Horizontal | 1 | TWEETER_3
J14 | JST_XH_S2B-XH-A-1_1x02_P2.50mm_Horizontal | 1 | TWEETER_4
J15 | USB_C_Receptacle_HCTL_HC-TYPE-C-16P-01A | 1 | USB_C_Receptacle_USB2.0_16P
J2 | BarrelJack_SwitchcraftConxall_RAPC10U_Horizontal | 1 | Barrel_Jack
J3 | PinHeader_1x04_P2.54mm_Vertical | 1 | UART
J5 | JST_XH_S2B-XH-A-1_1x02_P2.50mm_Horizontal | 1 | SUBWOOFER_1
J6 | JST_XH_S2B-XH-A-1_1x02_P2.50mm_Horizontal | 1 | SUBWOOFER_2
J7 | JST_XH_S2B-XH-A-1_1x02_P2.50mm_Horizontal | 1 | SUBWOOFER_3
J8 | JST_XH_S2B-XH-A-1_1x02_P2.50mm_Horizontal | 1 | SUBWOOFER_4
J9 | JST_XH_S2B-XH-A-1_1x02_P2.50mm_Horizontal | 1 | SUBWOOFER_5
L1, L10, L11, L12, L2, L3, L4, L5, L6, L7, L8, L9 | L_10.4x10.4_H4.8 | 12 | 10uH/10A
L13, L14, L15, L16, L17, L18, L19, L20 | L_APV_ANR4020 | 8 | 10uH/3A
L21 | L_6.3x6.3_H3 | 1 | 6.8uH/9A
Q1 | SOT-23 | 1 | BSS138
R1, R2 | 0603 | 2 | 2.2K
R10, R11, R8, R9 | 0603 | 4 | 470R
R12, R4, R67, R68, R69, R70, R71, R77 | 0603 | 8 | 10K
R13 | 0603 | 1 | 10.7K
R14, R78 | 0603 | 2 | 220R
R15 | 0603 | 1 | 3.3R
R16, R18, R20, R26, R27, R30, R35, R36, R39, R45, R46, R50, R55, R56, R60, R76 | 0603 | 16 | 100K
R17, R7 | 0603 | 2 | 56K
R19 | 0603 | 1 | 20K
R21, R22, R23, R24, R31, R32, R33, R34, R40, R41, R42, R43, R51, R52, R53, R54, R61, R62, R63, R64 | 0805 | 20 | 3.3R
R25, R44, R49, R59 | 0603 | 4 | 100R
R28, R37, R47, R57 | 0603 | 4 | 47K
R29, R38, R48, R58 | 0603 | 4 | 75K
R3, R65 | 0603 | 2 | 5.1K
R5, R6, R72, R73 | 0603 | 4 | 1K
R66 | 0603 | 1 | 205K
R74 | 0603 | 1 | 11.5K
R75 | 0603 | 1 | 60.4K
SW1 | SW_Push_1P1T_NO_CK_KSC9xxJ | 1 | POWER
SW2 | SW_Push_1P1T-SH_NO_CK_KMR2xxG | 1 | PI_BOOT
SW3 | SW_Push_1P1T-SH_NO_CK_KMR2xxG | 1 | ESP_BOOT
SW4 | SW_Push_1P1T-SH_NO_CK_KMR2xxG | 1 | ESP_RESET
SW6 | SW_DPDT_CK_JS202011JCQN | 1 | SW_DPDT_x2
TP1, TP2 | TestPoint_Pad_3.0x3.0mm | 2 | TestPoint
TP10 | TestPoint_Pad_D2.5mm | 1 | NEOPIXEL_DIN
TP11 | TestPoint_Pad_3.0x3.0mm | 1 | WFR_BCK
TP12 | TestPoint_Pad_3.0x3.0mm | 1 | WFR_SCK
TP13 | TestPoint_Pad_3.0x3.0mm | 1 | TWT_DIN
TP14 | TestPoint_Pad_D2.5mm | 1 | DRIVER_MUTE
TP15 | TestPoint_Pad_3.0x3.0mm | 1 | WFR_DIN
TP17, TP21, TP23, TP24, TP25 | TestPoint_Pad_D2.5mm | 5 | TestPoint
TP19 | TestPoint_Pad_3.0x3.0mm | 1 | SDA
TP20 | TestPoint_Pad_3.0x3.0mm | 1 | SCL
TP3 | TestPoint_Plated_Hole_D2.0mm | 1 | TWT_L
TP4 | TestPoint_Plated_Hole_D2.0mm | 1 | TWT_R
TP5 | TestPoint_Plated_Hole_D2.0mm | 1 | WFR_L
TP6 | TestPoint_Plated_Hole_D2.0mm | 1 | WFR_R
TP7 | TestPoint_Pad_D2.5mm | 1 | ORIENTATION
TP8 | TestPoint_Pad_3.0x3.0mm | 1 | TWT_BCK
TP9 | TestPoint_Pad_3.0x3.0mm | 1 | TWT_LRCK
U1 | MODULE_CM4102008 | 1 | CM4102008
U10 | SOT-23-5 | 1 | LP5907MFX-4.5
U11 | SOT-23-5 | 1 | LP5907MFX-3.3
U12, U13, U15, U16, U24, U25, U26 | Texas_DSBGA-6_0.9x1.4mm_Layout2x3_P0.5mm | 7 | TS5A3159AYZPR
U14, U5 | TSSOP-20_4.4x6.5mm_P0.65mm | 2 | PCM5102A
U17, U18, U19 | SOP65P810X115-32N | 3 | TPA3116D2DAD
U2, U3, U7 | USON-10_2.5x1.0mm_P0.5mm | 3 | TPD4E02B04DQA
U20, U21 | SOP65P810X115-32N | 2 | TPA3130D2DAPR
U22 | InvenSense_QFN-24_4x4mm_P0.5mm | 1 | MPU-6050
U23 | Bosch_LGA-8_3x3mm_P0.8mm_ClockwisePinNumbering | 1 | BME680
U27 | SOT-23-5 | 1 | TPS2041B
U28 | ESP32-WROVER-E_EXP | 1 | ESP32-WROVER-E-N16R8
U4 | CONV_TPS54540DDAR | 1 | TPS54540DDAR
U6 | SOT-23-3 | 1 | RT9742SNGV
U9 | SOT-23-5 | 1 | 74LVC1G07

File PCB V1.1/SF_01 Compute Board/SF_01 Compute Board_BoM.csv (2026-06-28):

Reference | Qty | Value | DNP | Exclude from BOM | Exclude from Board
C1,C4,C5,C7,C9,C14,C17,C19,C23,C26,C28,C31,C34,C37,C38,C39,C42,C43,C45,C47,C50,C53,C72,C80,C81,C106,C109,C135,C138,C163,C166,C185,C186 | 33 | 100nF
C2,C8,C12,C13,C44,C46,C48,C75,C76,C77,C102,C103,C105,C131,C132,C134,C157,C158,C159,C160,C162,C188,C190 | 23 | 1uF
C3,C15,C16,C18,C22,C25,C27,C32,C33,C40 | 10 | 10uF
C6,C73 | 2 | 22uF
C10,C11,C35,C36,C71 | 5 | 2.2nF
C20,C21,C29,C30 | 4 | 2.2uF
C24,C63,C64,C69,C70,C96,C97,C98,C99,C123,C124,C125,C126,C153,C154,C155,C156,C181,C182,C183,C184 | 21 | 10nF
C41 | 1 | 10uF (Tantalum)
C49,C52,C61,C62,C67,C68,C79,C82,C92,C93,C94,C95,C107,C108,C119,C120,C121,C122,C127,C128,C136,C137,C140,C149,C150,C151,C152,C164,C165,C168,C177,C178,C179,C180 | 34 | 1nF
C51,C54,C78,C83,C104,C110,C133,C139,C161,C167 | 10 | 220uF
C55,C56,C57,C58,C84,C85,C86,C87,C111,C112,C113,C114,C141,C142,C143,C144,C169,C170,C171,C172 | 20 | 220nF
C59,C60,C65,C66,C88,C89,C90,C91,C115,C116,C117,C118,C145,C146,C147,C148,C173,C174,C175,C176 | 20 | 680nF
CR1 | 1 | SP3010-04UTG
D1 | 1 | SMAJ33CA
D2,D5,D6,D7 | 4 | WS2812B
D3,D4 | 2 | LED
J1 | 1 | SS-53200-001
J2 | 1 | Barrel_Jack
J3 | 1 | UART
J5 | 1 | SUBWOOFER_1
J6 | 1 | SUBWOOFER_2
J7 | 1 | SUBWOOFER_3
J8 | 1 | SUBWOOFER_4
J9 | 1 | SUBWOOFER_5
J10 | 1 | SUBWOOFER_6
J11 | 1 | TWEETER_1
J12 | 1 | TWEETER_2
J13 | 1 | TWEETER_3
J14 | 1 | TWEETER_4
J15 | 1 | USB_C_Receptacle_USB2.0_16P
L1,L2,L3,L4,L5,L6,L7,L8,L9,L10,L11,L12 | 12 | 10uH/10A
L13,L14,L15,L16,L17,L18,L19,L20 | 8 | 10uH/3A
R1,R2 | 2 | 2.2K
R3,R65 | 2 | 5.1K
R4,R12,R25,R44,R49,R59,R67,R68,R69,R70,R71 | 11 | 10K
R5,R6,R72,R73 | 4 | 1K
R8,R9,R10,R11 | 4 | 470R
R14 | 1 | 220R
R15,R21,R22,R23,R24,R31,R32,R33,R34,R40,R41,R42,R43,R51,R52,R53,R54,R61,R62,R63,R64 | 21 | 3.3R
R16,R17,R18,R20,R26,R27,R30,R35,R36,R39,R45,R46,R50,R55,R56,R60 | 16 | 100K
R19 | 1 | 20K
R28,R37,R47,R57 | 4 | 47K
R29,R38,R48,R58 | 4 | 75K
SW1 | 1 | POWER
SW2 | 1 | PI_BOOT
SW3 | 1 | ESP_BOOT
SW4 | 1 | ESP_RESET
SW6 | 1 | SW_DPDT_x2
U1 | 1 | CM4102008
U2,U3,U7 | 3 | TPD4E02B04DQA
U5,U14 | 2 | PCM5102A
U6 | 1 | RT9742SNGV
U8,U9 | 2 | 74LVC1G07
U11 | 1 | LP5907MFX-3.3
U12,U13,U15,U16,U24,U25,U26 | 7 | TS5A3159AYZPR
U17,U18,U19 | 3 | TPA3116D2DAD
U20,U21 | 2 | TPA3130D2DAPR
U22 | 1 | MPU-6050
U23 | 1 | BME680
U27 | 1 | TPS2041B
U28 | 1 | ESP32-WROVER-E-N16R8
VR1 | 1 | LM1085ISX-5.0_NOPB

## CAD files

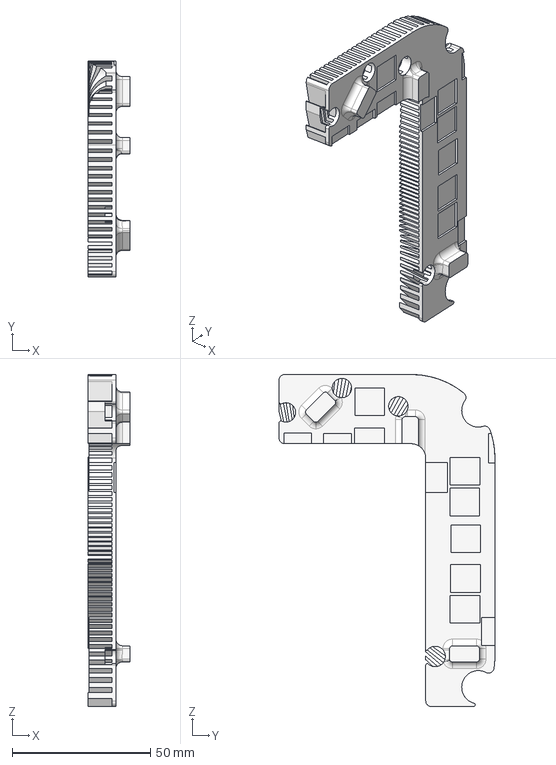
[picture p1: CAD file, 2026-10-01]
CAD/SF_01 Heatsink.step
15.0 x 78.0 x 120.0 mm

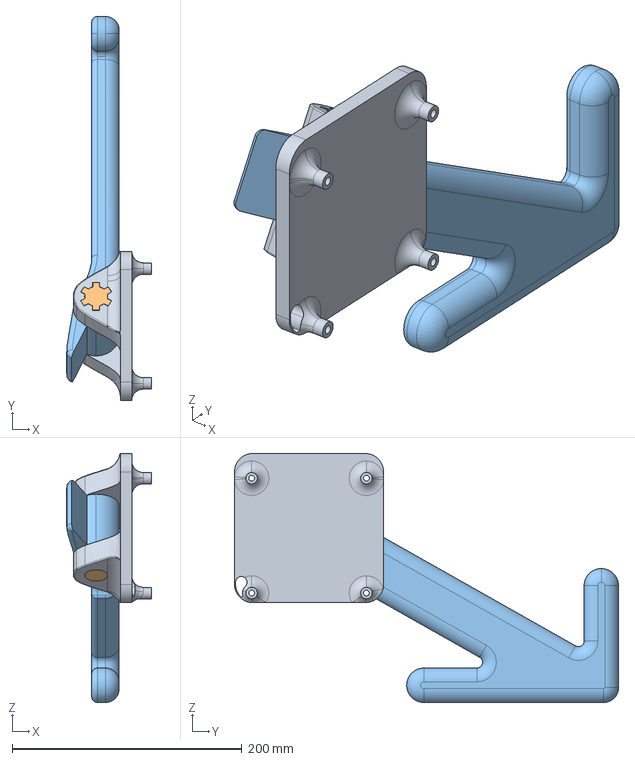
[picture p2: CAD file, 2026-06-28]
CAD/SF_01 Speaker Frame_STEP/Stand Piece.step
73.6 x 334.5 x 216.9 mm

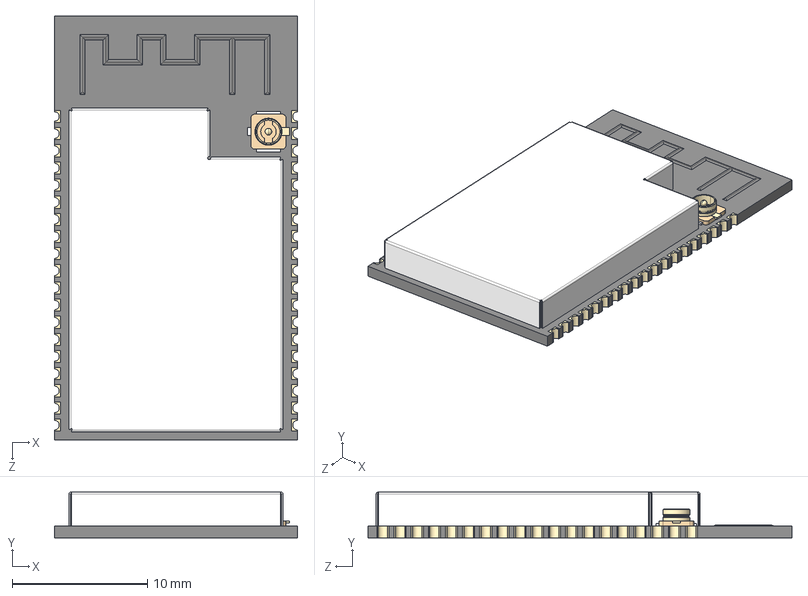
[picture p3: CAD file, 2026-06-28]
PCB V1.1/PCB Components/ESP32 WROVER B 16MB/ESP32-WROVER-B__16MB_.step
18.0 x 3.40 x 31.4 mm
ESP-WROOM-02D board
UFL connector

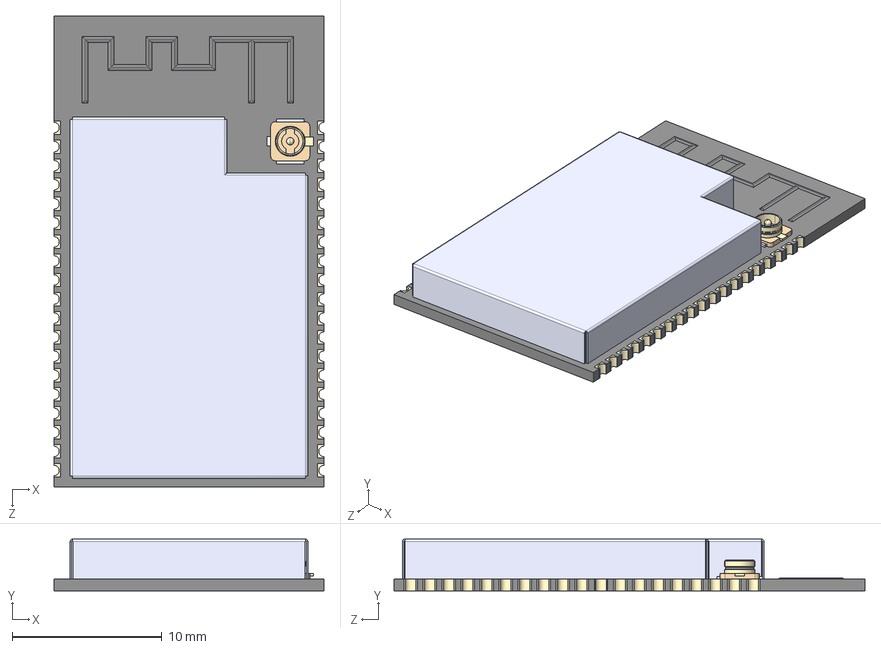
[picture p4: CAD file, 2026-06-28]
PCB V1.1/PCB Components/ESP32 WROVER E N16R8/ESP32-WROVER-E-N16R8.step
18.0 x 3.45 x 31.4 mm
ESP32-WROVER-E-N4R8 board
UFL connector

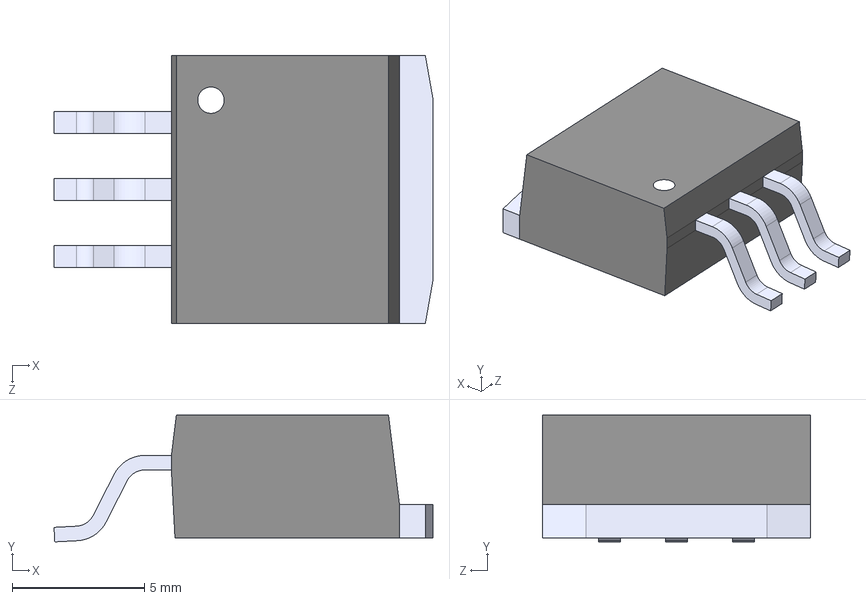
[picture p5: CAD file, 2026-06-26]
PCB V1.1/PCB Components/LM1085ISX-5.0_NOPB/LM1085ISX-5.0_NOPB.step
14.4 x 4.80 x 10.2 mm

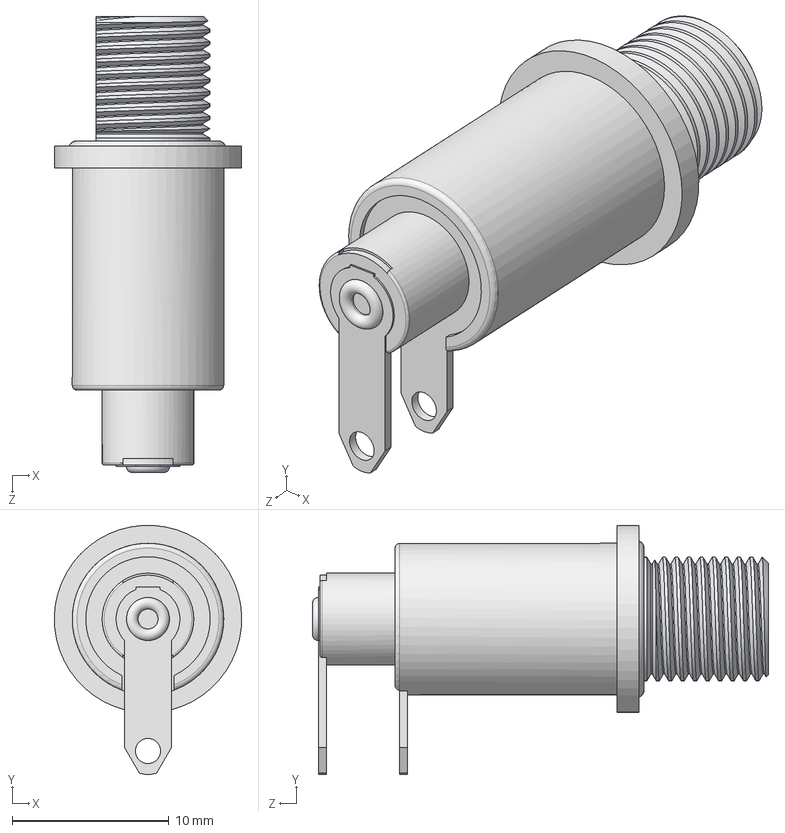
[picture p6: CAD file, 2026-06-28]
PCB V1.1/PCB Components/RAPC10U 3D Model STEP 1.STEP
11.9 x 15.9 x 29.0 mm

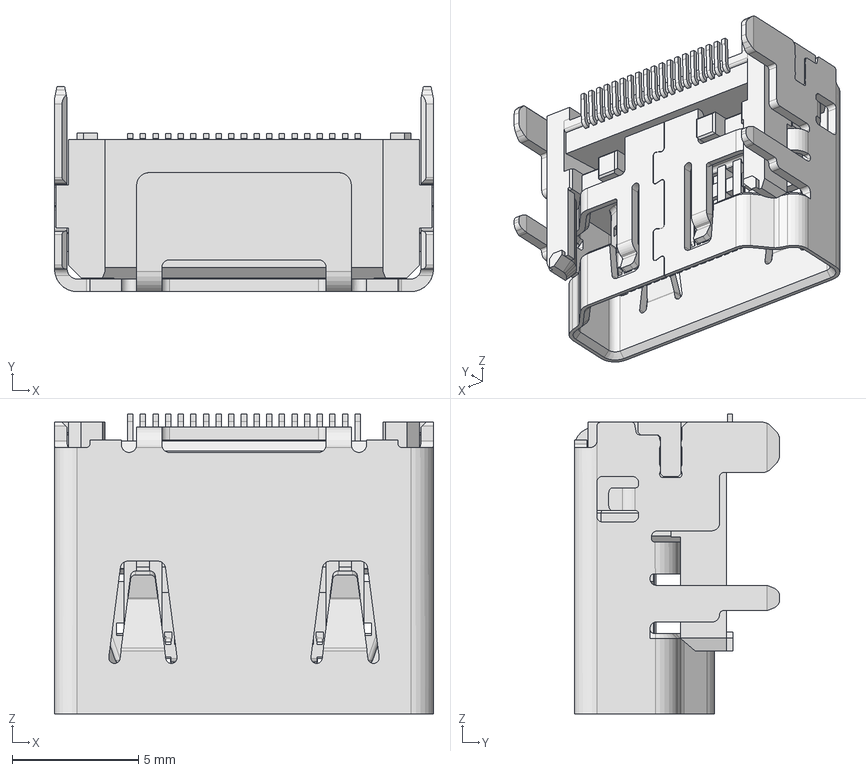
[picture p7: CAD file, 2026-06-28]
PCB V1.1/PCB Components/SS-53200 Model by Stewart Connector/SS-53200-001.stp
15.0 x 8.13 x 11.9 mm

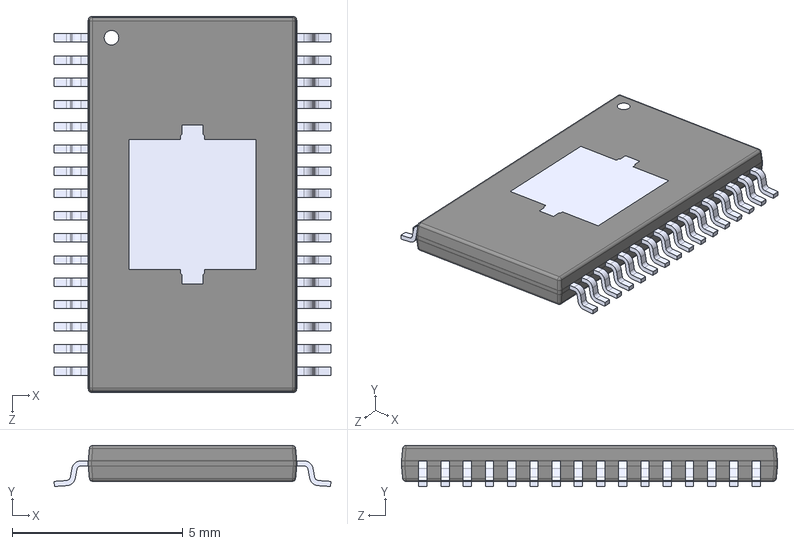
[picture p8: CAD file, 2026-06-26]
PCB V1.1/PCB Components/TPA3116D2DAD/TPA3116D2DAD.step
8.10 x 1.20 x 11.0 mm

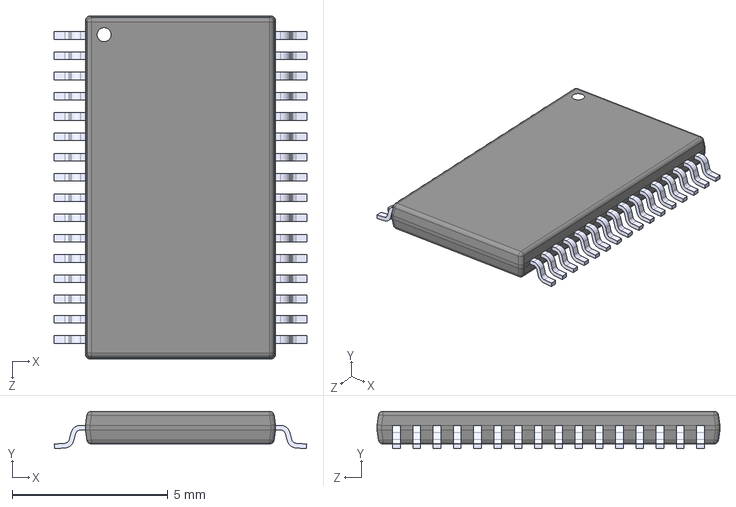
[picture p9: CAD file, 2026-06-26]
PCB V1.1/PCB Components/TPA3130D2DAPR/TPA3130D2DAPR.step
8.10 x 1.20 x 11.0 mm

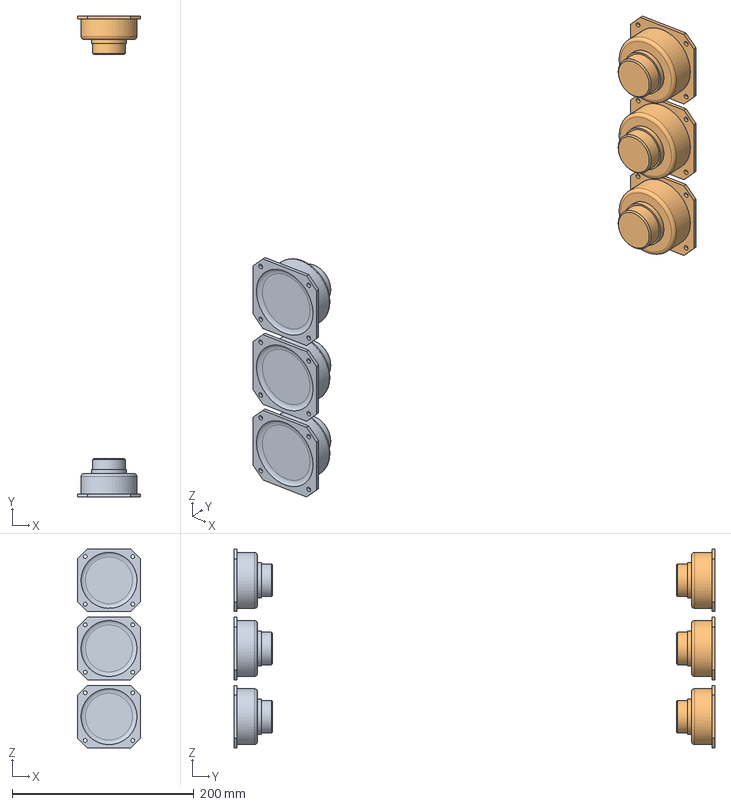
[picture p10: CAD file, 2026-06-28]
CAD/SF_01 Speaker Frame_STEP/Bass-Midwoofers.step
69.0 x 528.9 x 219.0 mm

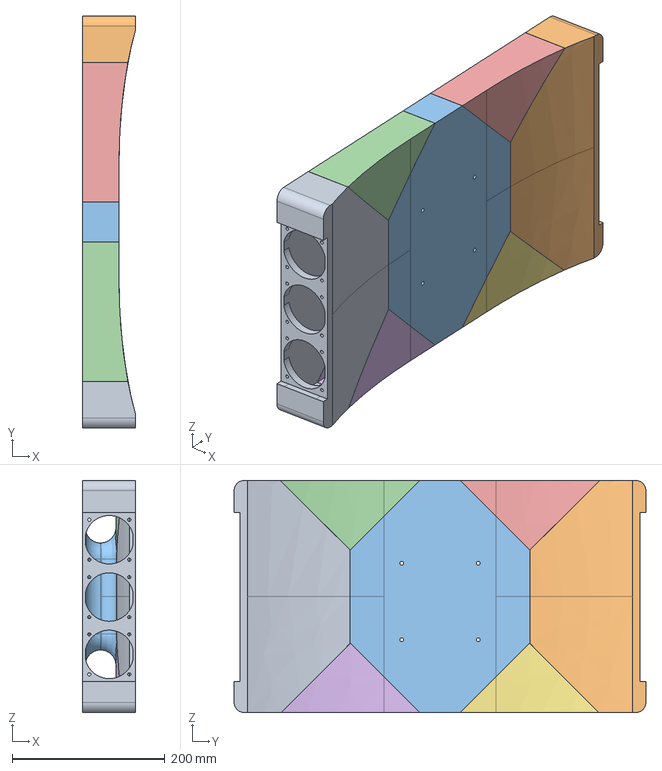
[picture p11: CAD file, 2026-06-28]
CAD/SF_01 Speaker Frame_STEP/Subwoofer Box Pieces (Glued).step
69.7 x 538.9 x 303.6 mm

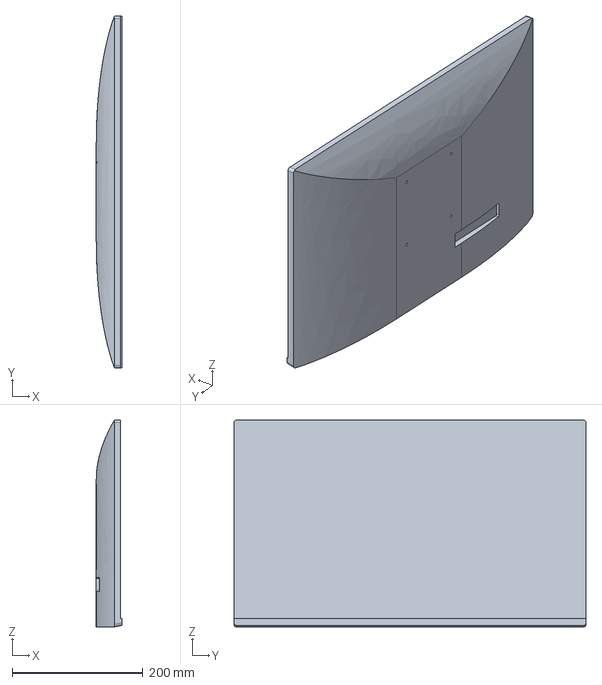
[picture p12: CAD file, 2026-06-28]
CAD/SF_01 Speaker Frame_STEP/LG 24U411A-B Monitor.step
39.2 x 539.2 x 317.1 mm

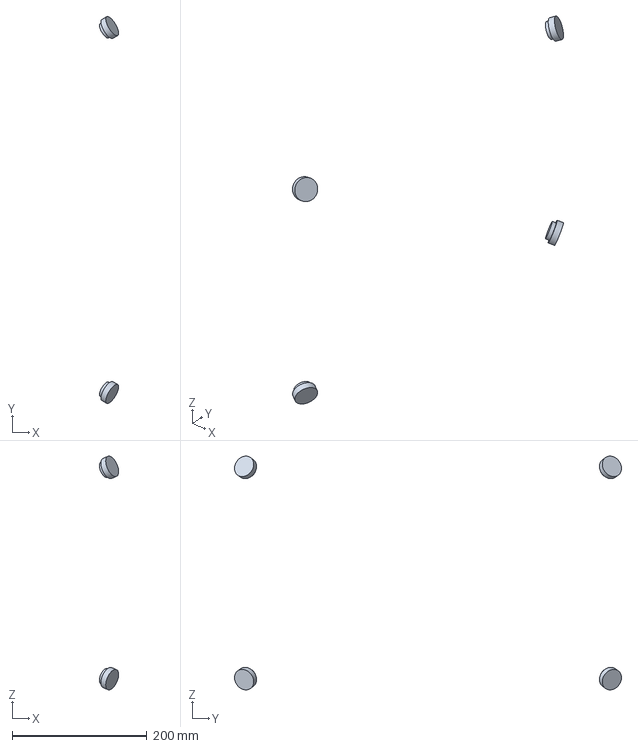
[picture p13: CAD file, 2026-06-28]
CAD/SF_01 Speaker Frame_STEP/Tweeters.step
28.7 x 575.5 x 347.6 mm

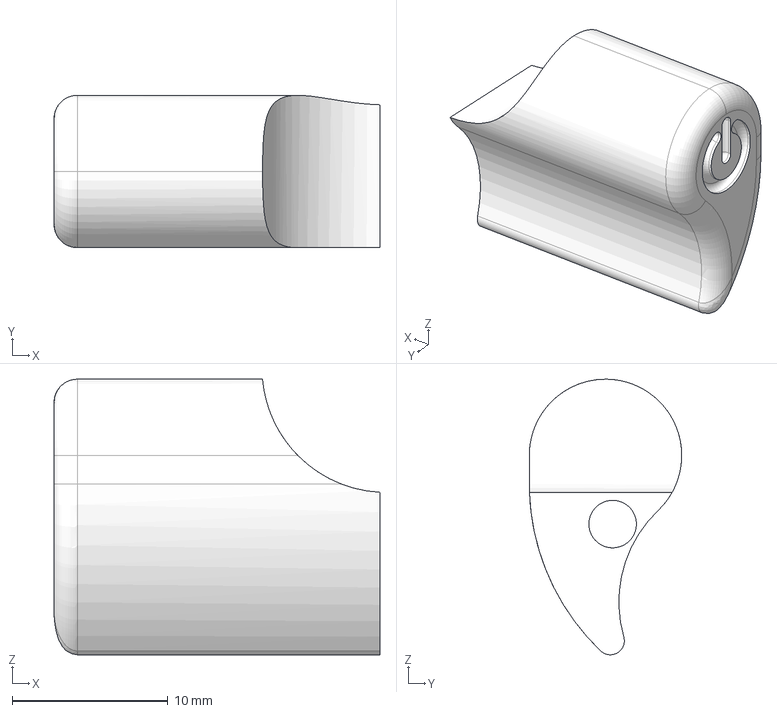
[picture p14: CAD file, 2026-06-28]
CAD/SF_01 Speaker Frame_STEP/Power Button.step
20.9 x 9.78 x 17.7 mm

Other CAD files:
CAD/SF_01 Speaker Frame_STEP/Wall Mounting Piece.step
PCB V1.1/PCB Components/TPS54540DDAR Model by Texas Instruments/TPS54540DDAR.step
PCB V1.1/PCB Components/JS202011JCQN 3D Model STEP 1.STEP
PCB V1/PCB Components/JS202011JCQN 3D Model STEP 1.STEP

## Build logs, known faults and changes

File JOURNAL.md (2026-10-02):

# Devlog 1: Started the Design

Preface: I already have 4 additional hours logged on the Lookout app, but have no way of having Hackatime recognise those 4 hours. That is where I started the design and completed most of the things I detail in this devlog. Here is the proof:



Now, onto the real devlog.

Soooooo, my parents are crazy about getting a digital picture frame, and after resarching, they were able to find... either hundreds of cheap RK3326-based Android picture frames (which aren't even that big), or amazing speakers from IKEA or Samsung *disguised* as frames, but not actually having screens.
I actually really like the idea of a digital picture frame with a speaker, and an ACTUALLY GOOD speaker at that (so it's not just a TV). So I started researching, using my knowledge in audio and electronics systems to try and find optimal components for what I am trying to do.

Then, I started the design of the frame which will enclose everything, including the all-important monitor and speaker system. Speaking of the speaker system (hehe), I decided to use some parts which I already had laying around, including at least (yes, at least) two Peerless P830985 drivers as bass-mid woofers, and using four Dayton Audio ND16FA-6 tweeters for the highs. This system should offer at least 100W of total RMS power output, around 60W of which will be coming from the bass-mid woofers.

For the main display, I wanted to use a large size, like 24 or 27 inches. This should make the viewing experience nice, and also make part sourcing very easy with many standard monitors being exactly those sizes. Speaking of monitors, I was able to find a really nice LG 24 inch HD monitor with an IPS display and 120Hz refresh rate for around $100AUD. This is MUCH cheaper than equivalent barebones displays and driver boards I could find on Alibaba, plus it offers VESA mounts which i can easily bolt my enclosure to.

Now to finally start the design of the frame. Audio around a screen is always a challenge, especially when you’re trying to keep it high-fidelity and actually worth listening to. This is because the screen makes up your entire frontal facade, leaving almost no room for high-frequency drivers. Designing a frame, I do have some leeway as to bezel size around the screen, but I don’t want the speaker system to be overly noticeable, while still providing omnidirectional audio (It’s gonna be in a living room, after all).

That led me to place the tweeters at the corners of the screen, in a 45-ish degree angle in two axes, so they face outwards from the screen. This decision will come back to bite me later. After that, I designed a nice profile for the frame to follow while keeping space for the tweeters inside yet not making their presence obvious. I was successful in making this, deciding to go with a very rounded frame design with rounded corners all around.

That’s when I thought to myself, “Frames aren’t really rounded rectangles, they’re usually sharp”, which is a correct thought. My frame did not look like a photo frame at all, instead looking like a big monitor with giant bezels. I hurried to try and make some corners for the frame, which turned out very successful. I then decided to make those corners magnetically attached, allowing the user to pick their style.

Next, I started to solve the problem of speaker holes for the tweeters. I had one goal in mind, that these speaker holes should not look like speaker holes at all, which means NO circles, like I usually do. That led me to experiment with some different styles for speaker holes, such as a “rainbow” made from rounded slots. That looked terrible, and completely blocked the tweeters from (from their perspective) above. Choosing to angle the tweeters introduces severe complexities, as the speaker holes now needed to simultaneously face both upwards and forward while looking good.

My “rainbow” design did have some good things about it, as it led me to the final design using splines that gradually open up to the speaker holes before gracefully closing down to a point again. I was also able to make a 45 degree tweeter-facing hole which allows it to breathe without looking like it faces 45 degrees. the corner pieces were also cut to make room for air, and they ended up looking even better after that.

Finally, I had to make the actual housing for the tweeters, as currently they were floating in thin air. Making this look good was quite a task, utilising many face offsets to close microscopic gaps and clean up the model. Eventually, I added some speaker holes at the back of the frame for the bass-mid woofers, and that’s all!





# Devlog 2: Designed the Subwoofer Box

Immediately upon finishing the design of the main frame, I started grinding out the subwoofer box that would go behind the monitor. As I had a huge amount of space behind the frame, I thought that maybe I should add... I don't know... FOUR extra bass-mid woofers to the design??? Since each of the drivers consumes around 30W, that would result in more than 180W of RMS power output... JUST FROM THE BASS DRIVERS. To put that into perspective, the 6 inch subwoofer used in my home theatre setup is 150W... so this should make for a ridiculous sound system.

To make the box itself, I used 5mm thick walls all around the box, and 10mm thick walls to hold the drivers themselves in. That should provide more than enough structural bracing for the 3D-printed box to hold itself together when the full 180W of driver power is unleashed within it. To make the box even stronger, I hollowed out a section right in the middle of the box for VESA mounts and the basic electronics of the whole system.

I'm super proud of this design feature in particular, which allows me to assemble the whole picture frame and secure all load-bearing components to it using the standard 100x100mm VESA mount the monitor comes with. That same VESA mount will also be used for securing the stand or the wall-mount accessory to the frame, so it's a really smart design feature.

Anyways, there's not that much more I can talk about regarding a literal box, so that's all for this devlog!





# Devlog 3: Splitting the Frame, and Ingenious Assembly!

I want the SF_01 to be 3D-printed without incurring too many costs. The main driver for cost in 3D-Printing is the size of the part, as bigger parts require bigger and exponentially expensive and inaccessible printers to print. That's why I want the SF_01 to be entirely printable in a standard 256x256x256mm build volume used by Bambu Lab.

Since the frame is 24 inches diagonally, it results in the largest dimension of the frame being over half a metre long, which requires it to be split into a minimum of 6 parts. For the main frame, those 6 parts are just the four corners of the frame plus two straight middle sections. Splitting the frame into parts is also what crucially allows for the monitor to slide into it in the first place, with it being held securely after that.

That's why I designed the main frame to be assembled into two main parts: a top and bottom part. The three top and bottom parts will be permanently glued together, but the two halves can join up and be removed at any time. How will I accomplish the two main parts being securely held together without compromising the aesthetics of the frame via unsightly screws, all while making sure the frame is repairable?

That's where the subwoofer box comes into play. I designed the box to hold 6 drivers, all of which face towards the outside of the frame. Each speaker requires four mounting screws to secure it into place, which I used to my advantage. I intentionally used cap-head screws, which stick out quite a distance from the drivers when screwed in. Those cap head screws then slide into grooves in the main frame from the back, holding the two pieces together! Finally, the subwoofer box is secured from the back with VESA screws, and the whole thing is securely assembled, with only those 4 VESA screws holding the entire frame together!




# Devlog 4: Splitting the Subwoofer Box

The subwoofer box itself is also way too large to fit on the build plate of any reasonable printer, so I set out to split that into multiple parts as well. However, I needed to be considerate with how I slice this part, as it has to deal with immense structural loads and still be completely airtight, as it's got 180W of speaker power blasting through it. That's why I decided to split the subwoofer box in 7 pieces instead of 6, with the baffle areas that hold the drivers all being crucially printed in one piece, and also the all-important VESA mounting area is in one piece as well. These are the two areas which will bear the most load, and cutting the box in this way ensures that there are no seams running through those crucial parts.

As for how the box is going to be assembled, I don't intend for the box to be able to be disassembled in the future, and also the box needs to provide an airtight seal. So I opted to omit any clips or dowels, and left the borders between the box's pieces blank for superglue to flow in between the pieces. It doesn't affect the repairability of the frame at all, as all the components in the box can still be removed freely when the whole thing is glued together.




# Devlog 5: Mounting Options!

The SF_01 is a FRAME, so it makes sense that it would be mounted either on someone's wall or on a table of some sorts. Both mounting options need to be addressed, and both must be robust enough to hold the gigantic 24 inch screen and especially the heavy drivers securely. So I designed the wall-mounting panel to screw into the monitor's VESA mounting holes, which are literally designed to hold up the full weight of the monitor. I then designed the wall-mounting panel, and made it absolutely humongous to be able to distribute the stuctural load of the frame's weight over a large area. I also made the screw keyholes extra thick and able to accommodate large screws that can be driven deep into the user's wall. I then also added an option to orient the mounting holes so that the frame is in portrait mode.

Then, I focused on designing the stand, which will bolt onto the VESA mount as a separate piece to the wall-mount piece. That decision was made because the stand, when folded, is not perfectly flush to the back of the frame, which would interfere with wall-mounting. I made the stand extremely chunky, with it hinging diagonal to the frame. That allows for the stand to work in both orientations, and also makes it more stable. Finally, I added a built-in stopper which prevents the stand from hinging out more than it should.




# Devlog 6: Started PCB Schematic

I finally finished the enclosure for the SF_01, and started on the schematic for the PCB. For Bluetooth, I decided to use an ESP32-S3 WROOM 2 module for audio streaming and DSP calculations. This was because the ESP32 is a super familiar platform for me, and literally all other Bluetooth DSP chips are from Qualcomm, who are total party poopers and make SURE you can't access support or any SDKs for any of their chips, making them impossible to use for a random kid like me.

Next, I added the Raspberry Pi CM4, and started wiring up HDMI for it to push an image out to the monitor. I used this as its cheap (MUCH cheaper than the CM5), and it only needs to run ONE web app on like Android 10, so 1GB of RAM and the CM4 performance is plenty good enough. Plus, the CM4 is just so damn EASY to make anything for (Take some notes Qualcomm), and it comes with an easy way to use WiFi (it comes built-in!) and to route a USB port. I made quick work of that schematic, especially since I was using the bare minimum of the CM4's pins. Just HDMI and one USB port with manual Host/Device switching (The CM4 only needs to be in Device mode once, during flashing Android, and it can stay in Host mode forever after that for Keyboard/Mouse support).



# Devlog 7: AUDIO NIGHTMARES

Having promptly dealt with the digital side of the PCB, I turned my gaze towards the analog section of the board that carries audio signals and the amplifiers. Yes, amplifierS, plural. See, I wanted the SF_01 to have something special. Since it has so many drivers, and is so physically huge, it should be able to reproduce stereo audio quite nicely, especially with the angled tweeters. Since the frame could be in two orientations, however, I thought that maybe I could dynamically switch which drivers the stereo signal plays out of. This would require audio switches, whic reroute the signals generated by my PCM5102A DACs (One set of low frequency left/right for the woofers, one set of high frequency left/right for the tweeters).

So I started to put two of the switches together, outputting audio to pre-connected sets of tweeters and woofers. That was a mistake, as I had failed to realise that electrically-connected drivers are... ELECTRICALLY CONNECTED. PERNANENTLY. How I had wired the switches literally sent out the same audio signal to every driver regardless of orientation. I then realised that the proper implementation of this is to have SEVERAL switches in series, which all work together to route signals.

My schematic went from relatively simple to having SEVEN audio switches and being too complicated to explain. But trust me, it definitely works. I made sure with a truth table. Now, I had to face the biggest beast of them all, the amplifiers. My schematic called for FIVE individual stereo amplifier chips, dedicating a whole channel for each driver. Soooo... I hope I survive...




# Devlog 8: Amplifier Shenanigans

The five amplifiers I selected were with care, as choosing the wrong ICs can make or break my project. Having multiple amplifiers outputting together also calls for a feature that I didn't know existed up until now, which was the ability to sync the clocks of all the amplifiers together. With my power requirements in mind, I found the Texas Instruments TPA31xxD2 series of amplifiers, which includes three chips of varying amplifier power. The whole family is pin-compatible, so it's perfect for my application as I can just reuse the schematic diagram of one amplifier for all five. Also, the amplifiers feature the clock-syncing ability I mentioned earlier, and since they are from the same family, they would all have the same clock frequency and would play nice with each other.

I decided on three TPA3116D2 chips for the woofers, as they can comfortably output 50W per channel, so driving 30W drivers would result in low heat generated. Then for the tweeters, I chose a pair of TPA3130D2 chips as they can output 15W per channel, so I won't risk destroying my tweeters when the frame first powers on. Texas Instruments also provides amazing application schematics for all of their audio amplifiers, so implementing that was relatively easy.





# Devlog 9: Assigning Footprints and Starting the PCB

After the amplifier schematics were done, the main schematics of the design were pretty much finished save for a few quality of life improvements. These included four WS2812B NeoPixel lights connected to the ESP32 for state signalling, and a UART pin header for programming the thing in the first place. After that, I started to assign all the PCB footprints for all the 200 or so components I had amassed. That took quite a lot of time as I was using so many imported libraries from SnapEDA and Ultra Librarian for the more specialised ICs I was using in my design. Nevertheless, I finally got to the end of that tedious task, and promptly created a PCB outline in the PCB editor. I was pleasantly surprised by how much space I had to work with, and this was by FAR my largest PCB.



# Devlog 10: Routed the HDMI and Pi Circuit

With all the components I needed to place off to one side of the board, and with a black screen in front of me, I started to place the Raspberry Pi CM4's circuit components, including the HDMI and USB-C ports. I then routed the traces for those, making sure to impedance-match all the high-speed data lines to make sure my design fits within the HDMI and USB specifications. I then routed the main power jack that powers the whole board, making sure to place a TON of vias all around it since it will carry more than 200W of power at 24V (that's like 8 amps...).




# Devlog 11: Routed the ESP32 and DAC Circuit

I placed the ESP32-S3 module right next to the Raspberry Pi, and routed all of the components around its strapping pins and also its decoupling capacitors. I then started routing the all-important DAC circuitry with the PCM5102A chips and the analog audio switches. This is the most delicate part of the whole board, as it requires really weak analog signals flowing through it, which can easily be disrupted and corrupted by digital ANYTHING next to them.

That's why I placed the most important part of this circuit, the ultra-low-noise power supply, on the other side of the board. Digital noise made by the HDMI signals would have to travel very far, so it will dissipate by the time it reaches the power supply. The PCM5102As were also placed far away from any digital signals, and a dense via fence was made to separate them. Via fences work just like regular fences, and since vias have holes drilled through them, they completely block any current from flowing through them, instead rerouting the current to flow around them. Placing vias close together diffracts any noise passing through them via the ground plane, which makes it much, MUCH less powerful.




# Devlog 12: Routed the Audio Switcher Circuit and 1st Amplifier!

I placed the audio switching circuit after the PCM5102As, and made sure to place them in such a manner where I would have to use the least number of vias I could possibly use. This is because audio signals HATE vias, as they are points of sudden change in resistance, causing EMI in some cases. I used a thicker 0.3mm trace width for each audio signal... uhh... because it felt right and I should trust my gut. 

Moving on, I finally started work on the 1st amplifier circuit, which was destined for woofers 1 and 2. I had gravely underestimated the space I had available on the board, so I packed the circuit in as tightly as I possibly could. That meant a lot of rearranging components, and experimenting with... interesting layouts until I was finally happy with what I had created. I angled the actual amplifier IC by 45 degrees and placed it in its own little corner along with the largest components in any amplifier system: the inductors. I made sure to use ton of vias for power and grounding, and I think I made a very nice little circuit that can still pack a punch.





# Devlog 13: Routed the 2nd Amplifier

The 2nd amplifier circuit needed to be a little closer to the actual plugs for the subwoofer, as I wanted to leave a lot of space in the centre of the board. That's why I allowed the inductors for this amplifier board hug the plugs extremely closely, making for a REALLY efficient current flow path. I had already gotten the hang of placing all the components required for the amplifiers, so I made relatively quick work of routing this one.

It was also at this moment when I routed the outputs from the 1st amplifier circuits to their actual plugs, and since theyv were quite far away from their plugs, I employed a couple of different tactics to minimise voltage loss across the output lines. I first made the traces SUPER thick, ensuring that they have as little resistance as possible, and then I made identical copies of the the lines on a layer below that, connected by vias. This reduces tge resistance even more, as the signal now has a huge amount of copper to travel through.



# Devlog 14: Routed the 3rd Amplifier

For the 3rd amplifier, I wanted to use the unused space around the bottom left of the PCB, and also avoid the massive traces that go to the 1st amplifier module, as high power analog signals can affect other high power analog signals, and huge traces also don't allow for all-important GND vias to be placed on them. The 3rd amplifier also had its inductors hugging the plugs, and I turned the chip around 180 degrees for this one, since that way it seemed to fit into its little corner most efficiently.



# Devlog 15: Routed the 4th and 5th Amplifier

Finally, the amplifier circuits for the woofers were done, and I could move onto the tweeter circuits which require way thinner traces and use much smaller inductores, so finally I had some breating room for routing. These amplifier circuits are my most beautiful, as they are completely symmetric and super efficient in their use of space anyway. Since I was using TPA3130D2DAPR chips (which have an exposed GND pad at the bottom), I could not place any Vsys vias under the chip and instead only used GND vias in the whole footprint. That was OK, as I was able to place plenty of other vias around the decoupling bulk capacitors surrounding each amplifier. The 5th amplifier was literally a copy-paste of the 4th amplifier circuit, so I don't really have that much more to talk about.




# Devlog 16: VIAS VIAS VIAS!!!!!

The time had finally come to place GND vias to my heart's content. Most analog circuits, and ESPECIALLY high-power ones like I had on my board, require the placement of many stitching vias around the whole circuit. These are to make sure the GND planes are "stitched together" in a way to provide a clean, low-resistance return current path from anywhere on the board as well as reduce noise transmitted through the GND planes.

Also, since I had packed my amplifier circuits so densely, I had nowhere to place my stitching vias near the circuits, but the empty void in the middle of the board was a PERFECT place to add the vias. MOREOVER, adding vias in the middle of the board creates a "sea of vias" where almost no noise can pass through it! I spammed vias all around the place.




# Devlog 17: Routed the sensors

So I forgot to mention this before, but I also added some sensors to the whole hardware stack as well when I was designing the PCB. First, I added an MPU-6050 so that the frame could use its onboard accelerometer to sense its orientation. That info would go to the ESP32 and tell it to trigger the audio switching circuit. Second, I alse added a Bosch environmental sensor that can detect temperature, humidity, air pressure and some other helpful stuff. That information can be used to send to the user via a smart home system like Matter, or maybe even to do some fancy audio calculations using the humidity and air pressure.

Anyways, I decided to place those two sensors smack bang in the middle of the great sea of vias, in the hope that the I2C circuitry and delicate sensors are shielded both from the analog hell thats going on in the amplifier side, and also the digital madness going on in the HDMI side. Finally, after some nice silkscreen text was placed, the PCB was done!!!!




# Devlog 18: A Realisation Hits

...or so I thought. I tried to look at making some firmware for this thing, and was faced with the simple fact that the ESP32-S3 WROOM 2 I had made the centre of my design... didn't support audio streaming over Bluetooth. DAMN IT! So I immediately started looking for alternative modules, eventually finding the ESP32 WROVER E module. This, compared to the normal ESP32 WROOM modules, has PSRAM that allows it to perform crazy computationally-heavy tasks, such as high-quality Bluetooth streaming and other stuff at the same time.

But the WROVER E module was long. Like much longer than the other module. I was able to fit it into the board, however, with just the PCB antenna poking out the top of the board. I can easily adjust the enclosure to accommodate that.




# Devlog 19: Fixing the PCB

I then undid most of the traces connecting to the ESP32 module, as now the new pins were in completely different place. Also, since the ESP32 WROVER E has built-in PSRAM, it hogs some of the IO pins on the module, meaning that not all of my IO signals could connect to the module. I had connected a whole bunch of stuff to the previous module, including mute and shutdown control for all of the amplifiers. I still wanted mute control of all analog devices, so I ended up scrapping the shutdown control pins of each amplifier, instead permanently tying them high to keep the amplifiers powered on all the time. That should be fine, as this thing has infinite power from the wall, so it's only a minor thing.

Also, I had to remove the JTAG and USB-C pins used for programming the ESP32, as the older ESP32 WROVER E module does not have a built-in USB bridge and I was already using the JTAG pins for other IO. That's fine, as I still have good old UART to program this thing, and I can just use a simple UART to USB bridge.



# Devlog 20: The start of firmware

I don't have enough time to clearly flesh out the firmware for this thing before submitting it to Stardance, so I just started a project with Espressif's Bluetooth A2DP sink template ESP-IDF project. I aim to further develop this firmware with DSP support and sensor support as the main functions.



# Devlog 21: Assembly!!!

The components and board all finally arrived, so I could start assembling the main circuit. I made sure to follow all the best practices in SMD soldering, as I only get one shot at getting this board right. I started with sqeegeeing the solder paste onto the board using a very carefully-positioned stencil, after which I spent 4 hours painstakingly placing each component by hand onto their respective pads. After that, I found out that my PCB reflow hotplate was too small for this board, so I resorted to cooking the board on a barbeque hotplate, which yielded almost perfect solder melting.





# Devlog 22: Troubleshooting and more troubleshooting

After assembling the board, I tested all the critical connections on the board with a multimeter to make sure there were no shorts, and I found that there were some bridged pins on the HDMI connector. Trying to remove the connector, the board wicked away all the heat from my hot air gun, and excessive prying managed to rip out the HDMI TMDS traces from the board altogether. This meant that the Raspberry Pi CM4 area of the board was now unusable.

After that, I powered on the board for the first time just to see if the amplifiers were working. The three woofer amplifiers were constantly faulting and shoving DC voltage into their outputs, making them unusable. The two tweeter amps seemed to be fine, however. For the next two days, I troubleshot the board, trying all sorts of methods and probing almost all of the test points on the board, until I found that the tiny audio multiplexer switches on my board were the source of the problem. One of the switches had shorted out somehow, either from bad soldering or an internal fault, and removing all the switches on the woofer side finally fixed the amplifiers! Because I had now lost the ability to multiplex the woofers, I bridged the left and right sides of the frame into static left and right channels, which would not have made that much of a difference anyway as low and mid frequencies lose their directionality. The best part of this was the tweeter amps and circuit seemed to be working perfectly.

# Devlog 23: 3V3 troubleshooting

Now that I had finally gotten the amps to work, I shifted my focus onto the rest of the Bluetooth circuitry on the board. I had previously connected the 3V3_A rail to the regular 3V3, as the raspberry pi CM4, which was the previous source of 3V3, was removed. The small 3V3 analogue regulator was now powering the ESP32 and both sides of the PCM5102A DACs. When I powered the board again, I noticed that the 3V3 regulator was instantly getting hot enough to burn my finger, which meant that there was a short somewhere in the 3V3 line. I removed the connecting bodge wire, and isolated the short to the main 3V3 rail, not 3V3_A.

To try and find this short, I doused the entire board with isopropyl alcohol in the hopes that the short would cause the alcohol to vaporise in its area first. This would have only worked if the short was localised over a small area, like on a passive 0603 component. However, that didn't happen, and I still had no idea where the short was. I then removed the WS2812 LEDs from the board, as they were likely to be damaged and short the board out, but the short still persisted. Finally, I resorted to feeling each component by touch, and noticed that the ESP32 module soldered on the board seemed to be getting warm. This was where the short was.

I then tried to desolder the module using increasingly hotter air, but it would not budge at all as the board under it had way too much thermal mass. Desoldering the module was simply not possible. After that, I decided that the module is faulty anyways, so destructively removing it was my only option left. I used pliers to pry open the grounded shield over the module, which actually came off surprisingly cleanly, leaving the module itself pretty much unharmed. After that, I ran current through 3V3 again just to pinpoint exactly where on the module the short was occurring, and I finally found that the main ESP32 processor itself was the cause of the short. I removed the chip with hot air, and finally, the short was gone!!! Turns out the ESP32 module was defective or had failed at some point during troubleshooting, and I had never tested it.



# Devlog 24: Salvaging the board

Thankfully, the ESP32 I had removed had all of its pins broken out to pads on the board, so I could easily solder new wires to them to connect to an off-the-shelf ESP32 devboard. I soldered simple Molex jumper wires that plugged into the devboard, and surprisingly, the I2S lines and audio quality seemed to be completely unaffected by the fact that they were now being routed without ground planes through Molex jumper wires. It's impressive how robust digital audio signals are. After the replacement ESP32 was plugged in, I prototyped some quick firmware that takes in a Bluetooth signal, processes it, and outputs it through the ESP32's two I2S lines. After all of that work, the Bluetooth finally worked! I could now play music through the speakers, and even change the equaliser settings on the fly using a simple Bluetooth LE GATT server hosted on the ESP32.



# Devlog 25: Assembling the SF_01

By now, my school had finally finished 3D-printing the SF_01's humongous pieces, and now it was time to put them together. The main subwoofer box would be glued together with Gorilla Glue, which was chosen as it's airtight and expands to fill all gaps. I laid the pieces of the box on a piece of baking paper, and carefully glued everything together. I then held the pieces together with weights to prevent the glue from pushing them out of alignment.

After the glue had cured, I fit all the speakers and tweeters into their places, and sealed off the open parts of the box using hot glue. Fitting the main board into its recess, there was plenty of space to the side where I could add in the ESP32 and CM4 that were now dangling off the board. I fixed everything in place with tape and hot glue, and they were adequately secured.

Finally, I painted the corner pieces in a nice gold spray paint, and glued them onto the frame. The build was COMPLETE, AND EVERYTHING WORKED!!!

Here's the demo video: https://youtu.be/gdqumSwGTgA

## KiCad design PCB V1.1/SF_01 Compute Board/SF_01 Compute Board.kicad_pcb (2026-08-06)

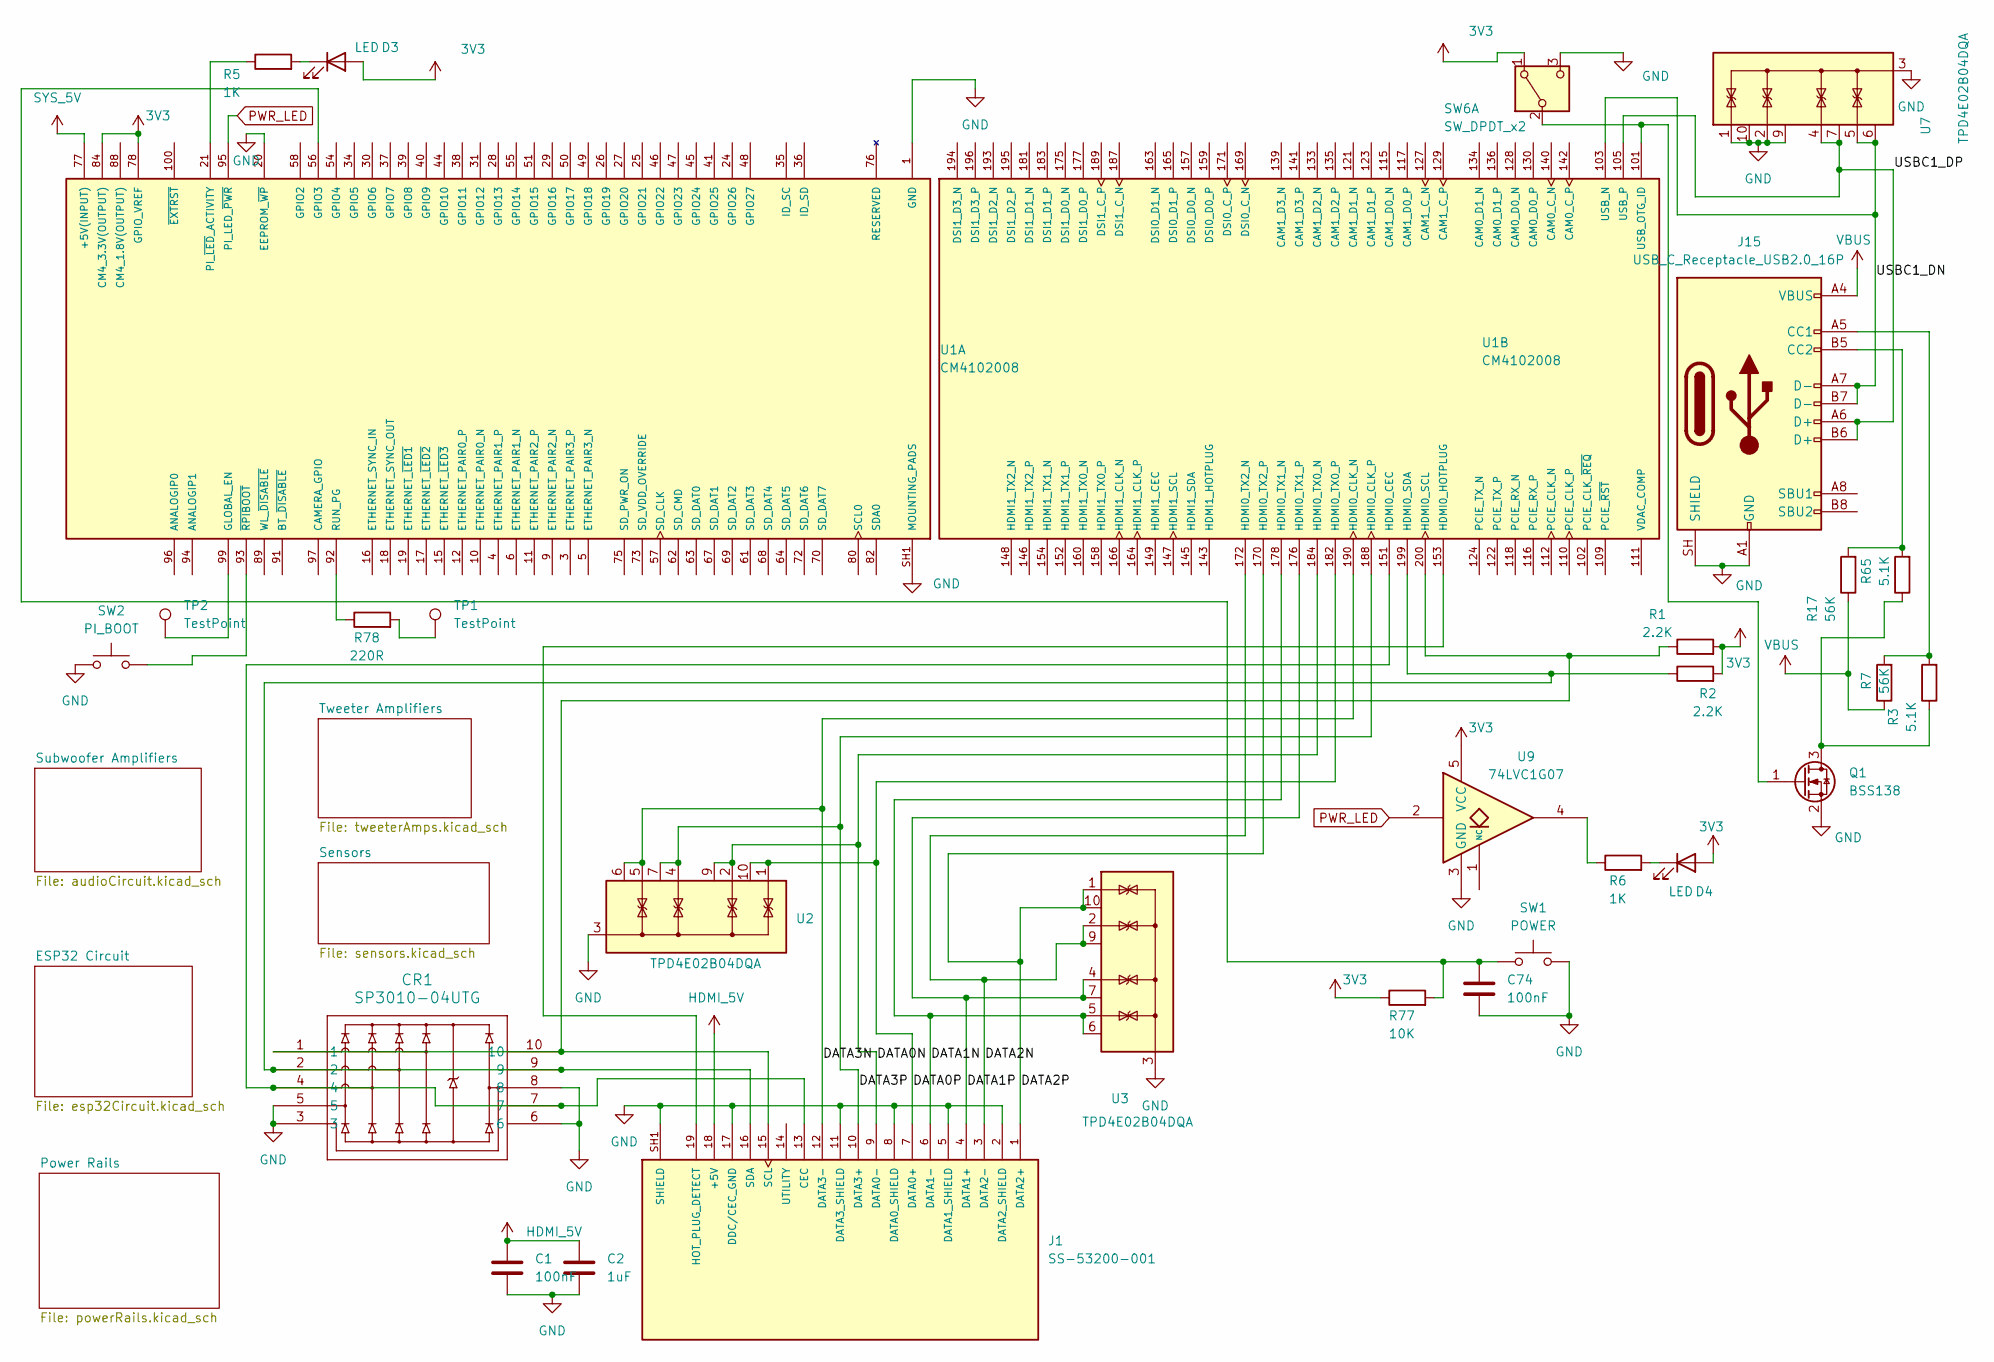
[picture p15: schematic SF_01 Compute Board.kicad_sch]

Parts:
C1, C74: 100nF; C_0603_1608Metric
C2: 1uF; C_0603_1608Metric
CR1: SP3010-04UTG; UDFEN-10_MO229_LTF
D3, D4: LED; LED_0603_1608Metric
J1: SS-53200-001; STEWART_SS-53200-001; PARTREV A0
J15: USB_C_Receptacle_USB2.0_16P; USB_C_Receptacle_HCTL_HC-TYPE-C-16P-01A
Q1: BSS138; SOT-23
R1, R2: 2.2K; R_0603_1608Metric
R3, R65: 5.1K; R_0603_1608Metric
R5, R6: 1K; R_0603_1608Metric
R7, R17: 56K; R_0603_1608Metric
R77: 10K; R_0603_1608Metric
R78: 220R; R_0603_1608Metric
SW1: POWER; SW_Push_1P1T_NO_CK_KSC9xxJ
SW2: PI_BOOT; SW_Push_1P1T-SH_NO_CK_KMR2xxG
SW6: SW_DPDT_x2; SW_DPDT_CK_JS202011JCQN
TP1, TP2: TestPoint; TestPoint_Pad_3.0x3.0mm
U1: CM4102008; MODULE_CM4102008; PARTREV 2021-10-12
U2, U3, U7: TPD4E02B04DQA; USON-10_2.5x1.0mm_P0.5mm
U9: 74LVC1G07; SOT-23-5

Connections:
3V3: D3.2 (A), D4.2 (A), R1.2, R2.2, R77.1, SW6.1 (A), U1.78 (GPIO_VREF), U1.84 (CM4_3.3V(OUTPUT)), U1.86 (CM4_3.3V(OUTPUT)), U9.5 (VCC); also elsewhere on the board
/DATA0N: J1.9 (DATA0-), U1.184 (HDMI0_TX0_N), U2.2 (IO2), U2.9 (NC)
/DATA0P: J1.7 (DATA0+), U1.182 (HDMI0_TX0_P), U2.1 (IO1), U2.10 (NC)
/DATA1N: J1.6 (DATA1-), U1.178 (HDMI0_TX1_N), U3.5 (IO4), U3.6 (NC)
/DATA1P: J1.4 (DATA1+), U1.176 (HDMI0_TX1_P), U3.4 (IO3), U3.7 (NC)
/DATA2N: J1.3 (DATA2-), U1.172 (HDMI0_TX2_N), U3.2 (IO2), U3.9 (NC)
/DATA2P: J1.1 (DATA2+), U1.170 (HDMI0_TX2_P), U3.1 (IO1), U3.10 (NC)
/DATA3N: J1.12 (DATA3-), U1.190 (HDMI0_CLK_N), U2.5 (IO4), U2.6 (NC)
/DATA3P: J1.10 (DATA3+), U1.188 (HDMI0_CLK_P), U2.4 (IO3), U2.7 (NC)
/USBC1_DN: J15.A7 (D-), J15.B7 (D-), U1.103 (USB_N), U7.5 (IO4), U7.6 (NC)
/USBC1_DP: J15.A6 (D+), J15.B6 (D+), U1.105 (USB_P), U7.4 (IO3), U7.7 (NC)
CM4_1.8V(OUTPUT): U1.88 (CM4_1.8V(OUTPUT)), U1.90 (CM4_1.8V(OUTPUT))
HDMI_5V: C1.1, C2.1, J1.18 (+5V); also elsewhere on the board
unnamed: D3.1 (K), R5.2
unnamed: D4.1 (K), R6.2
unnamed: CR1.4, CR1.7, J1.13 (CEC), U1.151 (HDMI0_CEC)
unnamed: J1.19 (HOT_PLUG_DETECT), U1.153 (HDMI0_HOTPLUG)
unnamed: CR1.1, CR1.10, J1.15 (SCL), R1.1, U1.200 (HDMI0_SCL)
unnamed: CR1.2, CR1.9, J1.16 (SDA), R2.1, U1.199 (HDMI0_SDA)
unnamed: J15.A5 (CC1), R3.2, R7.2
unnamed: J15.B5 (CC2), R17.2, R65.2
unnamed: Q1.3 (D), R3.1, R65.1
unnamed: Q1.1 (G), SW6.2 (B), U1.101 (USB_OTG_ID)
unnamed: R6.1, U9.4
unnamed: R78.2, TP1.1 (1_1)
unnamed: TP2.1 (1_1), U1.99 (GLOBAL_EN)
unnamed: C74.1, R77.2, SW1.1, U1.56 (GPIO3)
unnamed: R5.1, U1.21 (PI_~LED_ACTIVITY)
unnamed: R78.1, U1.92 (RUN_PG)
unnamed: SW2.2, U1.93 (~RPIBOOT)
PWR_LED: U1.95 (PI_LED_~PWR), U9.2
VBUS: J15.A4 (VBUS), J15.A9 (VBUS), J15.B4 (VBUS), J15.B9 (VBUS), R7.1, R17.1; also elsewhere on the board

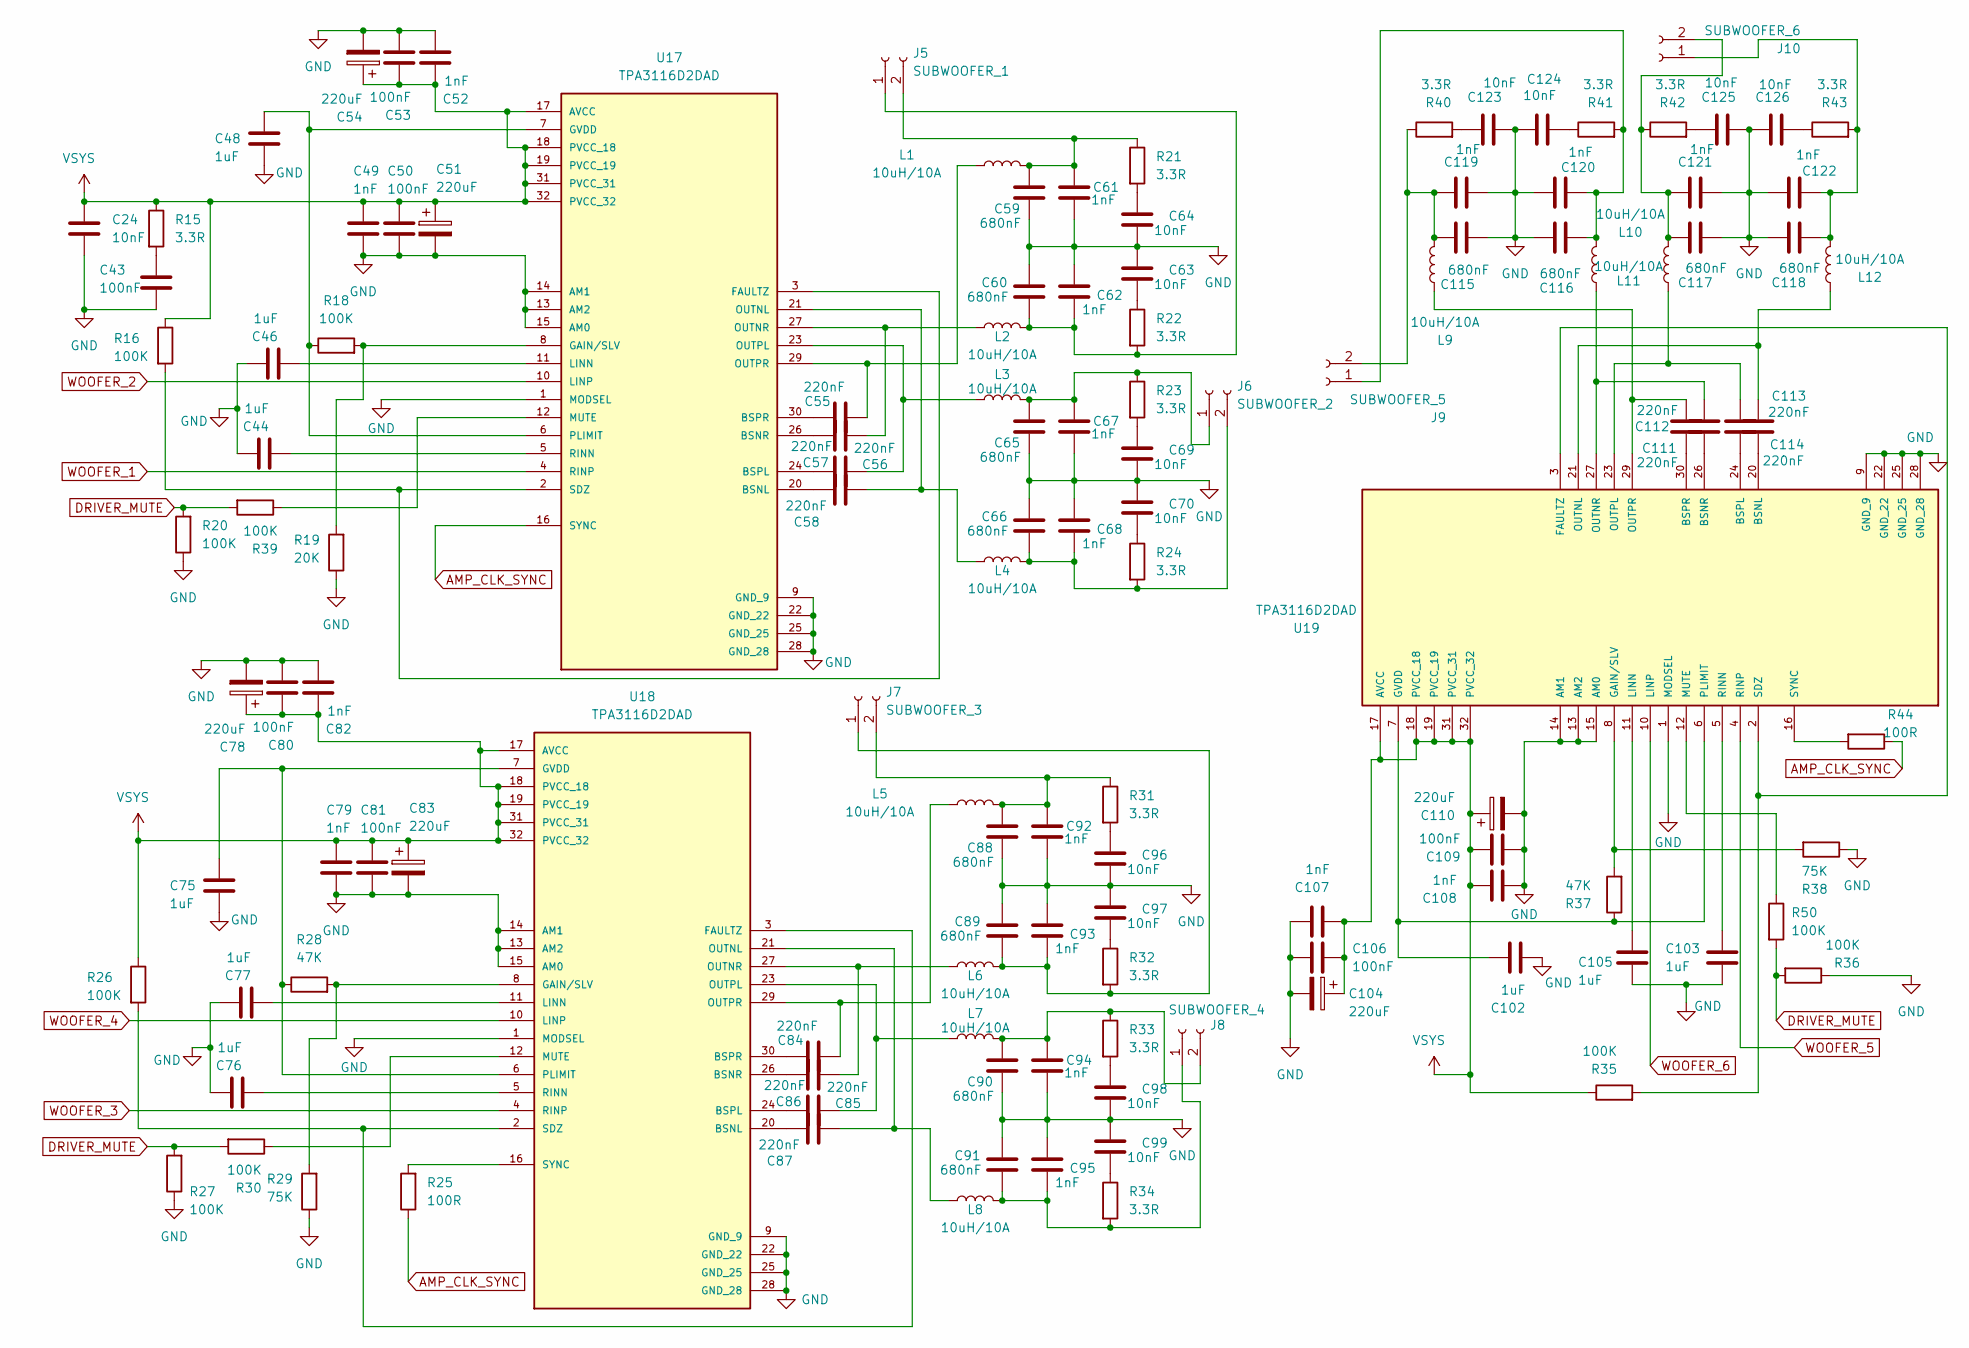
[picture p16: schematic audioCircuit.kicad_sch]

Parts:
C24, C63, C64, C69, C70, C96, C97, C98, C99, C123, C124, C125, C126: 10nF; C_0603_1608Metric
C43, C50, C53, C80, C81, C106, C109: 100nF; C_0603_1608Metric
C44, C46, C48, C75, C76, C77, C102, C103, C105: 1uF; C_0603_1608Metric
C49, C52, C61, C62, C67, C68, C79, C82, C92, C93, C94, C95, C107, C108, C119, C120, C121, C122: 1nF; C_0603_1608Metric
C51, C54, C78, C83, C104, C110: 220uF; CP_Elec_6.3x9.9
C55, C56, C57, C58, C84, C85, C86, C87, C111, C112, C113, C114: 220nF; C_0603_1608Metric
C59, C60, C65, C66, C88, C89, C90, C91, C115, C116, C117, C118: 680nF; C_0603_1608Metric
J5: SUBWOOFER_1; JST_XH_S2B-XH-A-1_1x02_P2.50mm_Horizontal
J6: SUBWOOFER_2; JST_XH_S2B-XH-A-1_1x02_P2.50mm_Horizontal
J7: SUBWOOFER_3; JST_XH_S2B-XH-A-1_1x02_P2.50mm_Horizontal
J8: SUBWOOFER_4; JST_XH_S2B-XH-A-1_1x02_P2.50mm_Horizontal
J9: SUBWOOFER_5; JST_XH_S2B-XH-A-1_1x02_P2.50mm_Horizontal
J10: SUBWOOFER_6; JST_XH_S2B-XH-A-1_1x02_P2.50mm_Horizontal
L1, L2, L3, L4, L5, L6, L7, L8, L9, L10, L11, L12: 10uH/10A; L_10.4x10.4_H4.8
R15: 3.3R; R_0603_1608Metric
R16, R18, R20, R26, R27, R30, R35, R36, R39, R50: 100K; R_0603_1608Metric
R19: 20K; R_0603_1608Metric
R21, R22, R23, R24, R31, R32, R33, R34, R40, R41, R42, R43: 3.3R; R_0805_2012Metric
R25, R44: 100R; R_0603_1608Metric
R28, R37: 47K; R_0603_1608Metric
R29, R38: 75K; R_0603_1608Metric
U17, U18, U19: TPA3116D2DAD; SOP65P810X115-32N; PARTREV G

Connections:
AMP_CLK_SYNC: R25.1, R44.1, U17.16 (SYNC); also elsewhere on the board
DRIVER_MUTE: R20.2, R27.2, R30.2, R36.2, R39.2, R50.2; also elsewhere on the board
unnamed: C43.1, R15.2
unnamed: C63.1, R22.1
unnamed: C64.2, R21.2
unnamed: C69.2, R23.2
unnamed: C70.1, R24.1
unnamed: C96.2, R31.2
unnamed: C97.1, R32.1
unnamed: C98.2, R33.2
unnamed: C99.1, R34.1
unnamed: C123.2, R40.2
unnamed: C124.1, R41.1
unnamed: C125.2, R42.2
unnamed: C126.1, R43.1
unnamed: C60.1, C62.1, J5.1, L2.2, R22.2
unnamed: C59.2, C61.2, J5.2, L1.2, R21.1
unnamed: C65.2, C67.2, J6.1, L3.2, R23.1
unnamed: C66.1, C68.1, J6.2, L4.2, R24.2
unnamed: C89.1, C93.1, J7.1, L6.2, R32.2
unnamed: C88.2, C92.2, J7.2, L5.2, R31.1
unnamed: C91.1, C95.1, J8.1, L8.2, R34.2
unnamed: C90.2, C94.2, J8.2, L7.2, R33.1
unnamed: C116.1, C120.1, J9.1, L10.2, R41.2
unnamed: C115.2, C119.2, J9.2, L9.2, R40.1
unnamed: C118.1, C122.1, J10.1, L12.2, R43.2
unnamed: C117.2, C121.2, J10.2, L11.2, R42.1
unnamed: C58.1, U17.20 (BSNL)
unnamed: C56.1, U17.26 (BSNR)
unnamed: C57.1, U17.24 (BSPL)
unnamed: C55.1, U17.30 (BSPR)
unnamed: R16.2, U17.2 (SDZ), U17.3 (FAULTZ)
unnamed: R18.2, R19.2, U17.8 (GAIN/SLV)
unnamed: C48.2, R18.1, U17.6 (PLIMIT), U17.7 (GVDD)
unnamed: C46.2, U17.11 (LINN)
unnamed: R39.1, U17.12 (MUTE)
unnamed: C58.2, L4.1, U17.21 (OUTNL)
unnamed: C56.2, L2.1, U17.27 (OUTNR)
unnamed: C57.2, L3.1, U17.23 (OUTPL)
unnamed: C55.2, L1.1, U17.29 (OUTPR)
unnamed: C44.2, U17.5 (RINN)
unnamed: C87.1, U18.20 (BSNL)
unnamed: C85.1, U18.26 (BSNR)
unnamed: C86.1, U18.24 (BSPL)
unnamed: C84.1, U18.30 (BSPR)
unnamed: R26.2, U18.2 (SDZ), U18.3 (FAULTZ)
unnamed: R28.2, R29.2, U18.8 (GAIN/SLV)
unnamed: C75.2, R28.1, U18.6 (PLIMIT), U18.7 (GVDD)
unnamed: C77.2, U18.11 (LINN)
unnamed: R30.1, U18.12 (MUTE)
unnamed: C87.2, L8.1, U18.21 (OUTNL)
unnamed: C85.2, L6.1, U18.27 (OUTNR)
unnamed: C86.2, L7.1, U18.23 (OUTPL)
unnamed: C84.2, L5.1, U18.29 (OUTPR)
unnamed: C76.2, U18.5 (RINN)
unnamed: R25.2, U18.16 (SYNC)
unnamed: C114.1, U19.20 (BSNL)
unnamed: C112.1, U19.26 (BSNR)
unnamed: C113.1, U19.24 (BSPL)
unnamed: C111.1, U19.30 (BSPR)
unnamed: R35.2, U19.2 (SDZ), U19.3 (FAULTZ)
unnamed: R37.2, R38.2, U19.8 (GAIN/SLV)
unnamed: C102.2, R37.1, U19.6 (PLIMIT), U19.7 (GVDD)
unnamed: C105.2, U19.11 (LINN)
unnamed: R50.1, U19.12 (MUTE)
unnamed: C114.2, L12.1, U19.21 (OUTNL)
unnamed: C112.2, L10.1, U19.27 (OUTNR)
unnamed: C113.2, L11.1, U19.23 (OUTPL)
unnamed: C111.2, L9.1, U19.29 (OUTPR)
unnamed: C103.2, U19.5 (RINN)
unnamed: R44.2, U19.16 (SYNC)
VSYS: C24.1, C49.1, C50.1, C51.1, C52.1, C53.1, C54.1, C78.1, C79.1, C80.1, C81.1, C82.1, C83.1, C104.1, C106.1, C107.1, C108.1, C109.1, C110.1, R15.1, R16.1, R26.1, R35.1, U17.17 (AVCC), U17.18 (PVCC_18), U17.19 (PVCC_19), U17.31 (PVCC_31), U17.32 (PVCC_32), U18.17 (AVCC), U18.18 (PVCC_18), U18.19 (PVCC_19), U18.31 (PVCC_31), U18.32 (PVCC_32), U19.17 (AVCC), U19.18 (PVCC_18), U19.19 (PVCC_19), U19.31 (PVCC_31), U19.32 (PVCC_32); also elsewhere on the board
WOOFER_1: U17.4 (RINP); also elsewhere on the board
WOOFER_2: U17.10 (LINP); also elsewhere on the board
WOOFER_3: U18.4 (RINP); also elsewhere on the board
WOOFER_4: U18.10 (LINP); also elsewhere on the board
WOOFER_5: U19.4 (RINP); also elsewhere on the board
WOOFER_6: U19.10 (LINP); also elsewhere on the board

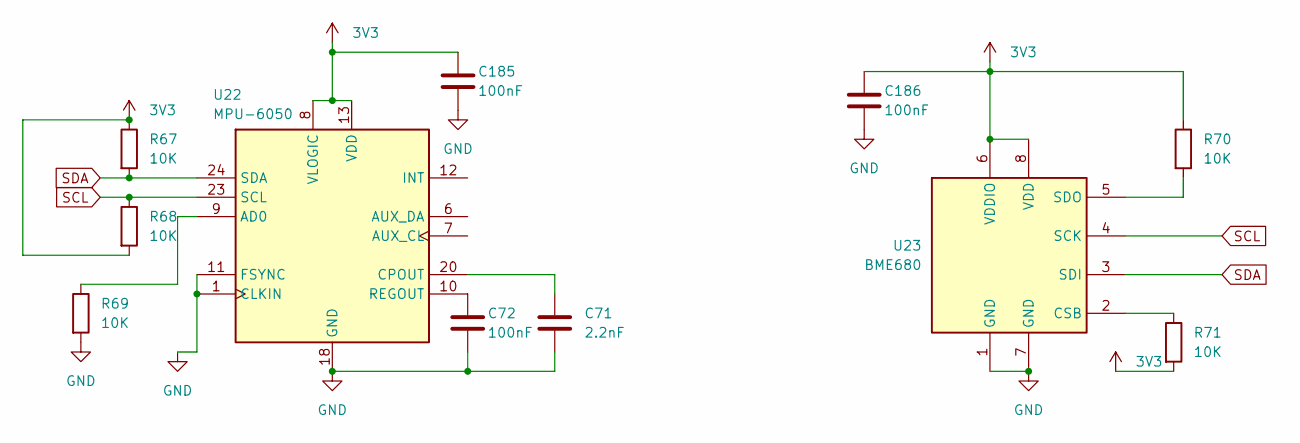
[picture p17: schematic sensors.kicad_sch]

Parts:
C71: 2.2nF; C_0603_1608Metric
C72, C185, C186: 100nF; C_0603_1608Metric
R67, R68, R69, R70, R71: 10K; R_0603_1608Metric
U22: MPU-6050; InvenSense_QFN-24_4x4mm_P0.5mm
U23: BME680; Bosch_LGA-8_3x3mm_P0.8mm_ClockwisePinNumbering

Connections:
3V3: C185.1, C186.1, R67.1, R68.2, R70.1, R71.2, U22.8 (VLOGIC), U22.13 (VDD), U23.6 (VDDIO), U23.8 (VDD); also elsewhere on the board
unnamed: R69.1, U22.9 (AD0)
unnamed: C71.1, U22.20 (CPOUT)
unnamed: C72.1, U22.10 (REGOUT)
unnamed: R71.1, U23.2 (CSB)
unnamed: R70.2, U23.5 (SDO)
SCL: R68.1, U22.23 (SCL), U23.4 (SCK); also elsewhere on the board
SDA: R67.2, U22.24 (SDA), U23.3 (SDI); also elsewhere on the board

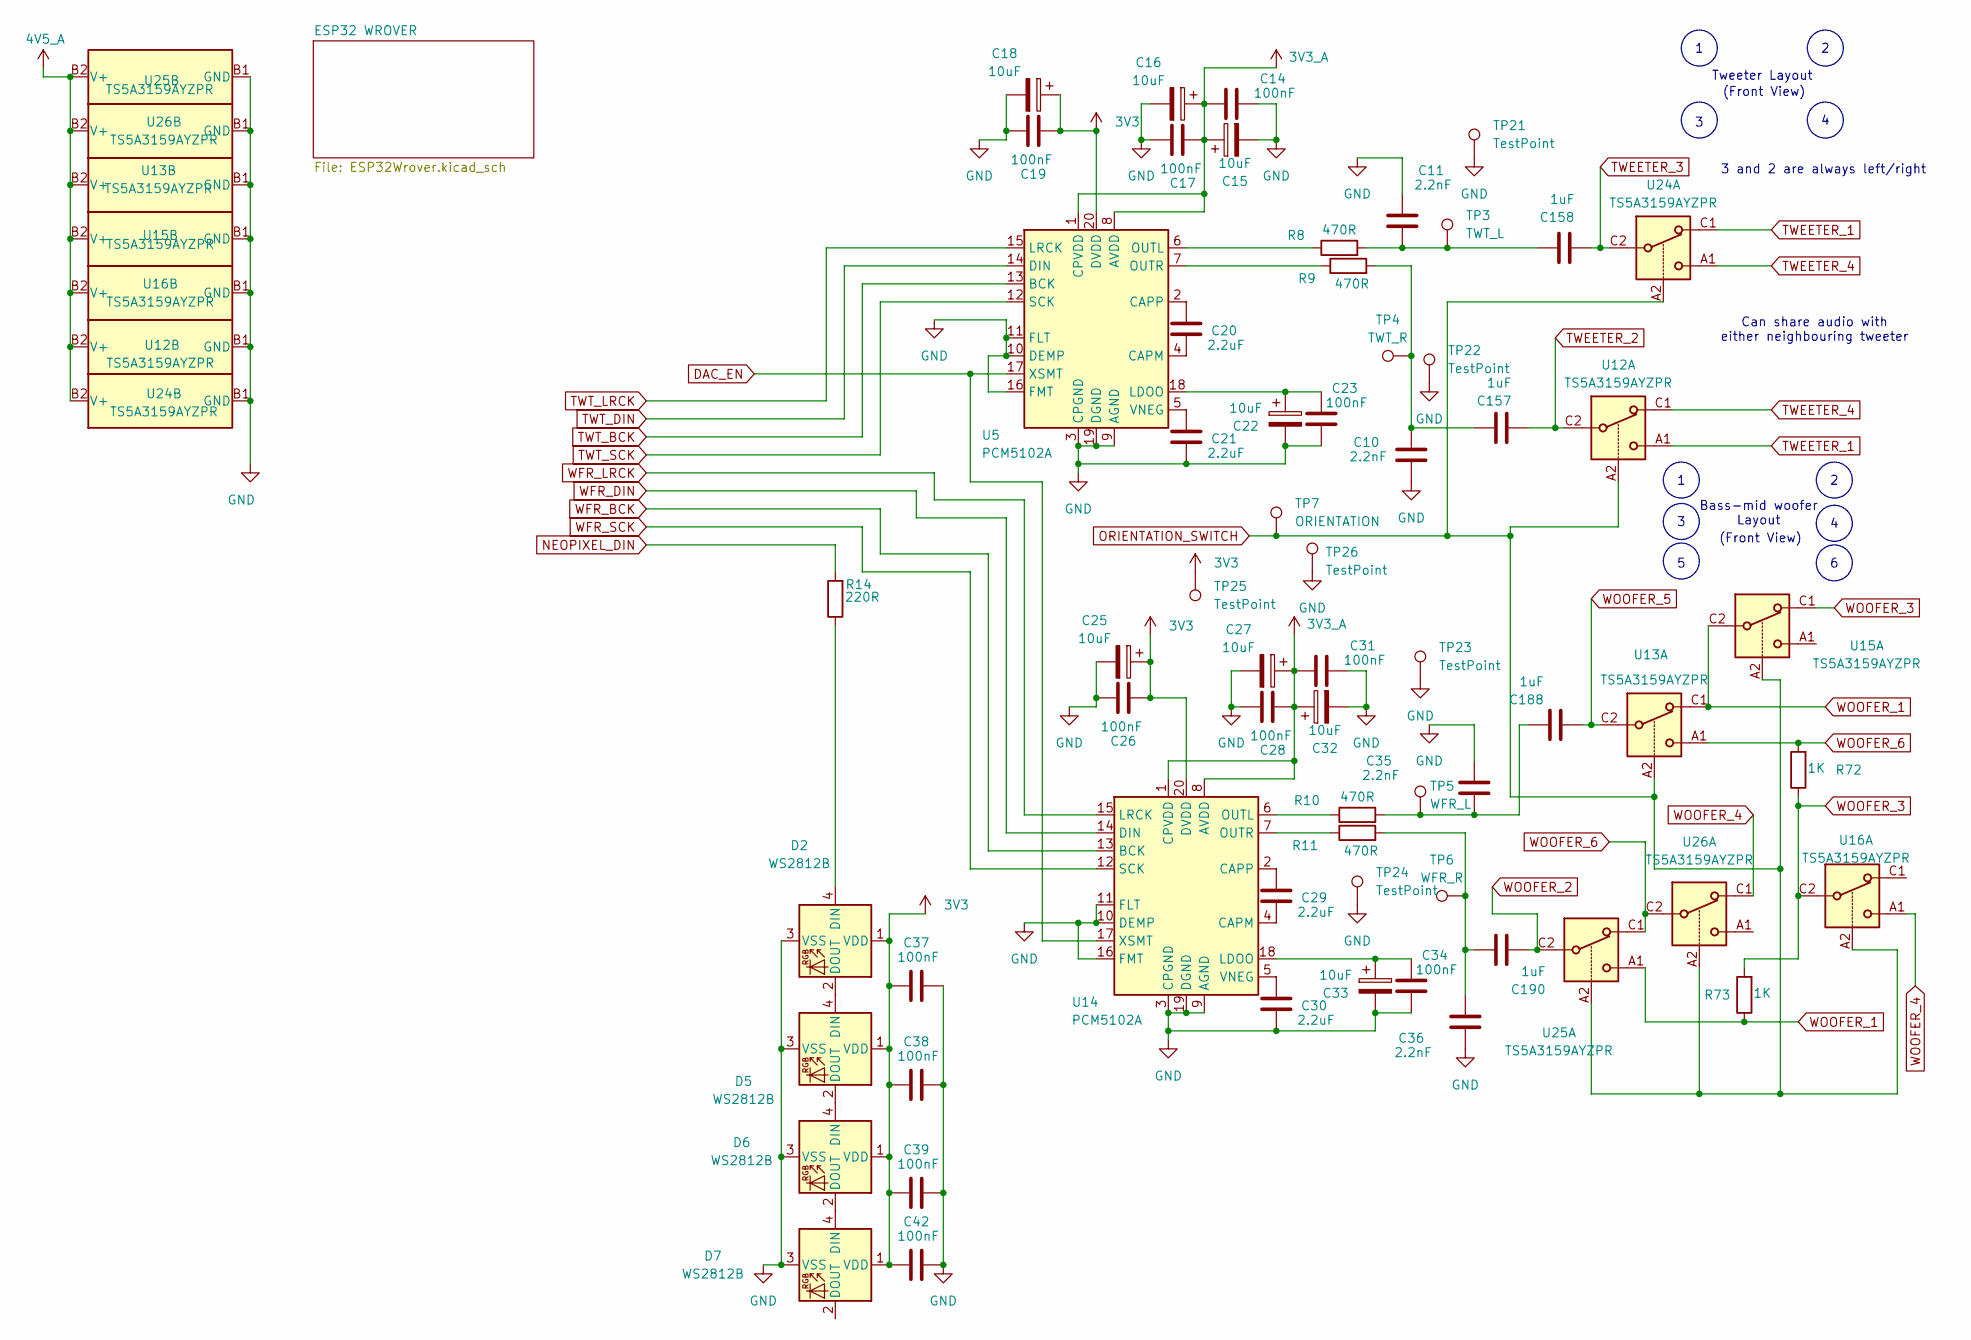
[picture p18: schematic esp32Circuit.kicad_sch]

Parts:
C10, C11, C35, C36: 2.2nF; C_0603_1608Metric
C14, C17, C19, C23, C26, C28, C31, C34, C37, C38, C39, C42: 100nF; C_0603_1608Metric
C15, C16, C18, C22, C25, C27, C32, C33: 10uF; CP_Elec_4x3
C20, C21, C29, C30: 2.2uF; C_0603_1608Metric
C157, C158, C188, C190: 1uF; C_0603_1608Metric
D2, D5, D6, D7: WS2812B; LED_WS2812B_PLCC4_5.0x5.0mm_P3.2mm
R8, R9, R10, R11: 470R; R_0603_1608Metric
R14: 220R; R_0603_1608Metric
R72, R73: 1K; R_0603_1608Metric
TP3: TWT_L; TestPoint_Plated_Hole_D2.0mm
TP4: TWT_R; TestPoint_Plated_Hole_D2.0mm
TP5: WFR_L; TestPoint_Plated_Hole_D2.0mm
TP6: WFR_R; TestPoint_Plated_Hole_D2.0mm
TP7: ORIENTATION; TestPoint_Pad_D2.5mm
TP21, TP22, TP23, TP24, TP25, TP26: TestPoint; TestPoint_Pad_D2.5mm
U5, U14: PCM5102A; TSSOP-20_4.4x6.5mm_P0.65mm
U12, U13, U15, U16, U24, U25, U26: TS5A3159AYZPR; Texas_DSBGA-6_0.9x1.4mm_Layout2x3_P0.5mm

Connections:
3V3: C18.1, C19.2, C25.1, C26.2, C37.2, C38.2, C39.2, C42.2, D2.1 (VDD), D5.1 (VDD), D6.1 (VDD), D7.1 (VDD), TP25.1 (1_1), U5.20 (DVDD), U14.20 (DVDD); also elsewhere on the board
3V3_A: C14.2, C15.1, C16.1, C17.2, C27.1, C28.2, C31.2, C32.1, U5.1 (CPVDD), U5.8 (AVDD), U14.1 (CPVDD), U14.8 (AVDD); also elsewhere on the board
DAC_EN: U5.17 (XSMT), U14.17 (XSMT); also elsewhere on the board
NEOPIXEL_DIN: R14.2; also elsewhere on the board
unnamed: C10.1, C157.1, R9.2, TP4.1 (1_1)
unnamed: C11.2, C158.1, R8.2, TP3.1 (1_1)
unnamed: C35.2, C188.1, R10.2, TP5.1 (1_1)
unnamed: C36.1, C190.1, R11.2, TP6.1 (1_1)
unnamed: D2.4 (DIN), R14.1
unnamed: D2.2 (DOUT), D5.4 (DIN)
unnamed: D5.2 (DOUT), D6.4 (DIN)
unnamed: D6.2 (DOUT), D7.4 (DIN)
unnamed: C20.2, U5.4 (CAPM)
unnamed: C20.1, U5.2 (CAPP)
unnamed: C22.1, C23.2, U5.18 (LDOO)
unnamed: R8.1, U5.6 (OUTL)
unnamed: R9.1, U5.7 (OUTR)
unnamed: C21.1, U5.5 (VNEG)
unnamed: C29.2, U14.4 (CAPM)
unnamed: C29.1, U14.2 (CAPP)
unnamed: C33.1, C34.2, U14.18 (LDOO)
unnamed: R10.1, U14.6 (OUTL)
unnamed: R11.1, U14.7 (OUTR)
unnamed: C30.1, U14.5 (VNEG)
ORIENTATION_SWITCH: TP7.1 (1_1), U12.A2, U13.A2, U15.A2, U16.A2, U24.A2, U25.A2, U26.A2; also elsewhere on the board
TWEETER_1: U12.A1, U24.C1; also elsewhere on the board
TWEETER_2: C157.2, U12.C2; also elsewhere on the board
TWEETER_3: C158.2, U24.C2; also elsewhere on the board
TWEETER_4: U12.C1, U24.A1; also elsewhere on the board
TWT_BCK: U5.13 (BCK); also elsewhere on the board
TWT_DIN: U5.14 (DIN); also elsewhere on the board
TWT_LRCK: U5.15 (LRCK); also elsewhere on the board
TWT_SCK: U5.12 (SCK); also elsewhere on the board
WFR_BCK: U14.13 (BCK); also elsewhere on the board
WFR_DIN: U14.14 (DIN); also elsewhere on the board
WFR_LRCK: U14.15 (LRCK); also elsewhere on the board
WFR_SCK: U14.12 (SCK); also elsewhere on the board
WOOFER_1: R73.1, U13.C1, U15.C2, U25.A1; also elsewhere on the board
WOOFER_2: C190.2, U25.C2; also elsewhere on the board
WOOFER_3: R72.1, R73.2, U15.C1, U16.C2; also elsewhere on the board
WOOFER_4: U16.A1, U26.C1; also elsewhere on the board
WOOFER_5: C188.2, U13.C2; also elsewhere on the board
WOOFER_6: R72.2, U13.A1, U25.C1, U26.C2; also elsewhere on the board

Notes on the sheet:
(Front View)
3 and 2 are always left/right
Can share audio with either neighbouring tweeter
Tweeter Layout
Bass-mid woofer Layout

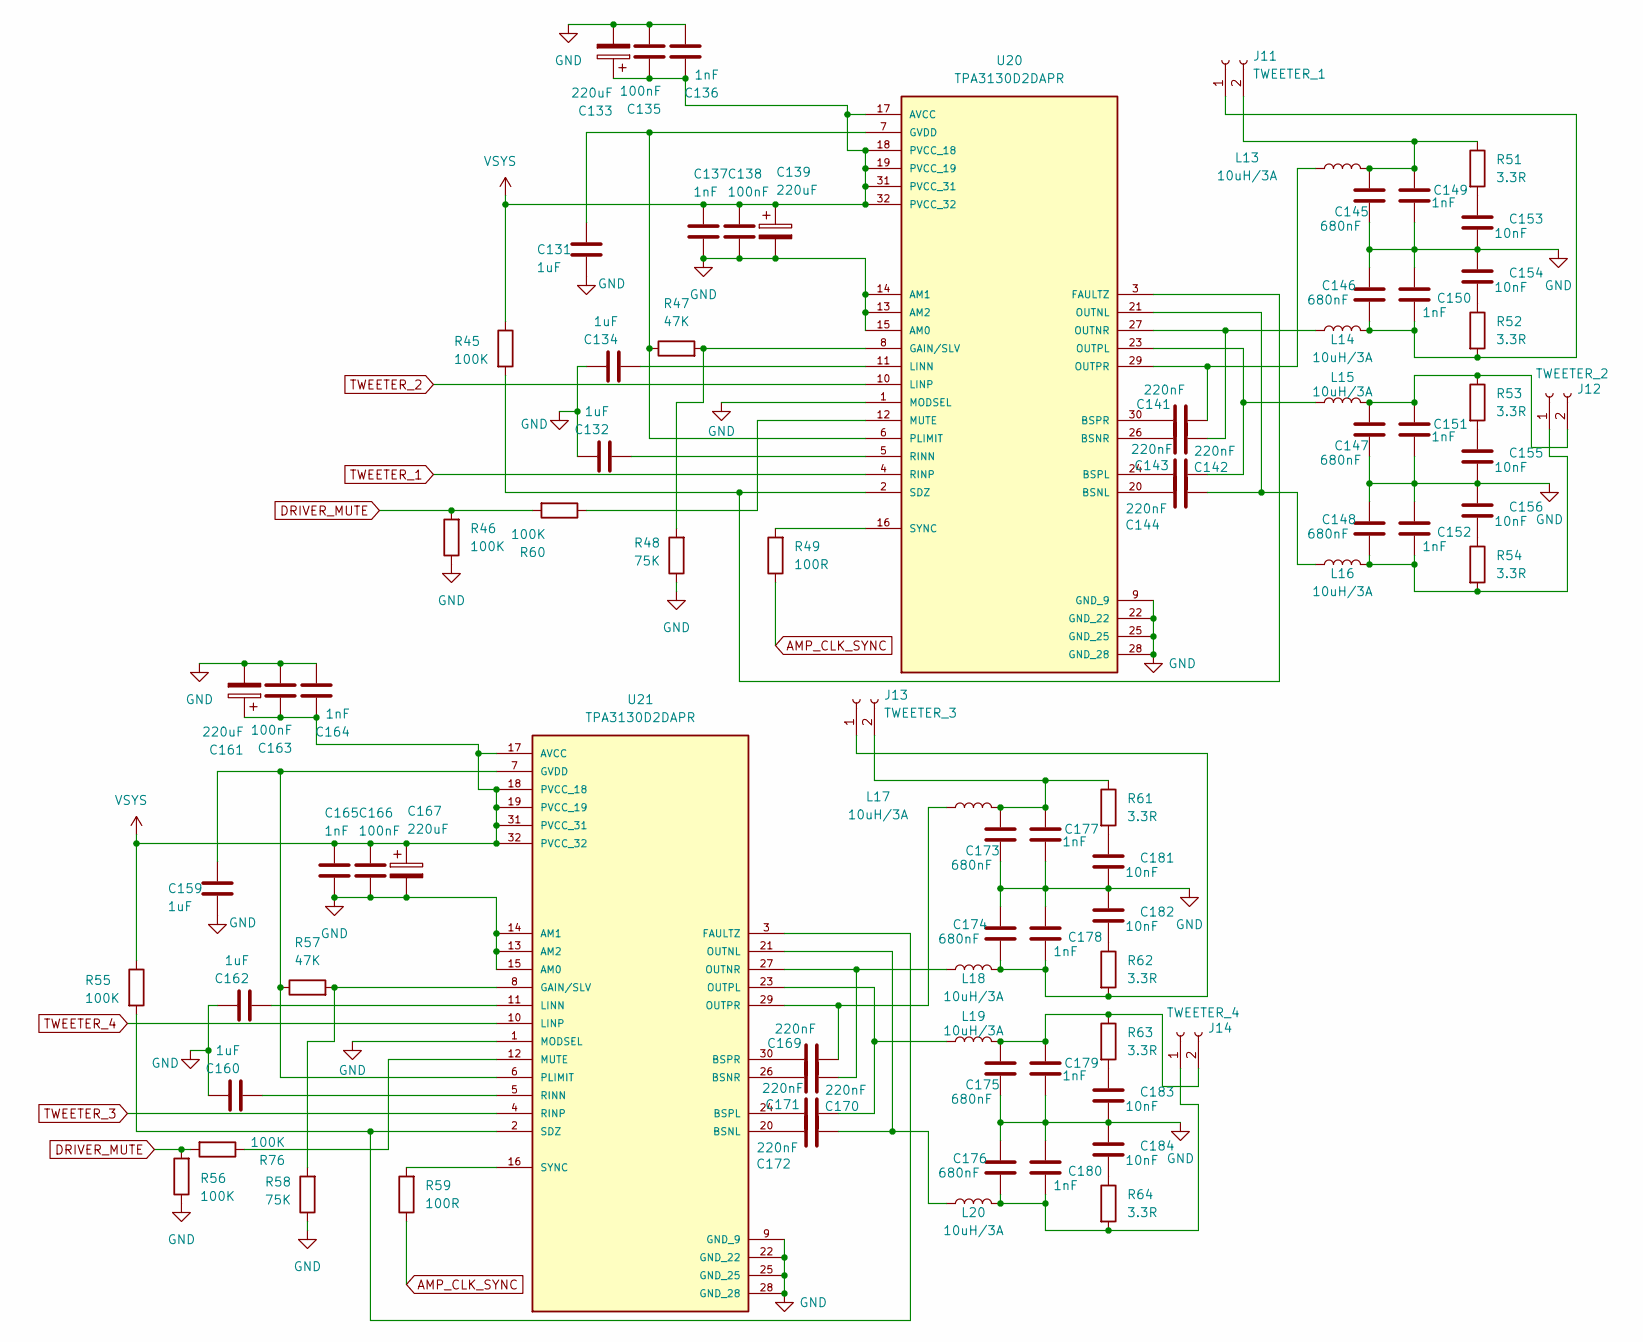
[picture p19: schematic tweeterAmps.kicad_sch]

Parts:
C131, C132, C134, C159, C160, C162: 1uF; C_0603_1608Metric
C133, C139, C161, C167: 220uF; CP_Elec_6.3x9.9
C135, C138, C163, C166: 100nF; C_0603_1608Metric
C136, C137, C149, C150, C151, C152, C164, C165, C177, C178, C179, C180: 1nF; C_0603_1608Metric
C141, C142, C143, C144, C169, C170, C171, C172: 220nF; C_0603_1608Metric
C145, C146, C147, C148, C173, C174, C175, C176: 680nF; C_0603_1608Metric
C153, C154, C155, C156, C181, C182, C183, C184: 10nF; C_0603_1608Metric
J11: TWEETER_1; JST_XH_S2B-XH-A-1_1x02_P2.50mm_Horizontal
J12: TWEETER_2; JST_XH_S2B-XH-A-1_1x02_P2.50mm_Horizontal
J13: TWEETER_3; JST_XH_S2B-XH-A-1_1x02_P2.50mm_Horizontal
J14: TWEETER_4; JST_XH_S2B-XH-A-1_1x02_P2.50mm_Horizontal
L13, L14, L15, L16, L17, L18, L19, L20: 10uH/3A; L_APV_ANR4020
R45, R46, R55, R56, R60, R76: 100K; R_0603_1608Metric
R47, R57: 47K; R_0603_1608Metric
R48, R58: 75K; R_0603_1608Metric
R49, R59: 100R; R_0603_1608Metric
R51, R52, R53, R54, R61, R62, R63, R64: 3.3R; R_0805_2012Metric
U20, U21: TPA3130D2DAPR; SOP65P810X115-32N; PARTREV G

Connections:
AMP_CLK_SYNC: R49.1, R59.1; also elsewhere on the board
DRIVER_MUTE: R46.2, R56.2, R60.2, R76.2; also elsewhere on the board
unnamed: C153.2, R51.2
unnamed: C154.1, R52.1
unnamed: C155.2, R53.2
unnamed: C156.1, R54.1
unnamed: C181.2, R61.2
unnamed: C182.1, R62.1
unnamed: C183.2, R63.2
unnamed: C184.1, R64.1
unnamed: C146.1, C150.1, J11.1, L14.2, R52.2
unnamed: C145.2, C149.2, J11.2, L13.2, R51.1
unnamed: C148.1, C152.1, J12.1, L16.2, R54.2
unnamed: C147.2, C151.2, J12.2, L15.2, R53.1
unnamed: C174.1, C178.1, J13.1, L18.2, R62.2
unnamed: C173.2, C177.2, J13.2, L17.2, R61.1
unnamed: C176.1, C180.1, J14.1, L20.2, R64.2
unnamed: C175.2, C179.2, J14.2, L19.2, R63.1
unnamed: C144.1, U20.20 (BSNL)
unnamed: C142.1, U20.26 (BSNR)
unnamed: C143.1, U20.24 (BSPL)
unnamed: C141.1, U20.30 (BSPR)
unnamed: R45.2, U20.2 (SDZ), U20.3 (FAULTZ)
unnamed: R47.2, R48.2, U20.8 (GAIN/SLV)
unnamed: C131.2, R47.1, U20.6 (PLIMIT), U20.7 (GVDD)
unnamed: C134.2, U20.11 (LINN)
unnamed: R60.1, U20.12 (MUTE)
unnamed: C144.2, L16.1, U20.21 (OUTNL)
unnamed: C142.2, L14.1, U20.27 (OUTNR)
unnamed: C143.2, L15.1, U20.23 (OUTPL)
unnamed: C141.2, L13.1, U20.29 (OUTPR)
unnamed: C132.2, U20.5 (RINN)
unnamed: R49.2, U20.16 (SYNC)
unnamed: C172.1, U21.20 (BSNL)
unnamed: C170.1, U21.26 (BSNR)
unnamed: C171.1, U21.24 (BSPL)
unnamed: C169.1, U21.30 (BSPR)
unnamed: R55.2, U21.2 (SDZ), U21.3 (FAULTZ)
unnamed: R57.2, R58.2, U21.8 (GAIN/SLV)
unnamed: C159.2, R57.1, U21.6 (PLIMIT), U21.7 (GVDD)
unnamed: C162.2, U21.11 (LINN)
unnamed: R76.1, U21.12 (MUTE)
unnamed: C172.2, L20.1, U21.21 (OUTNL)
unnamed: C170.2, L18.1, U21.27 (OUTNR)
unnamed: C171.2, L19.1, U21.23 (OUTPL)
unnamed: C169.2, L17.1, U21.29 (OUTPR)
unnamed: C160.2, U21.5 (RINN)
unnamed: R59.2, U21.16 (SYNC)
TWEETER_1: U20.4 (RINP); also elsewhere on the board
TWEETER_2: U20.10 (LINP); also elsewhere on the board
TWEETER_3: U21.4 (RINP); also elsewhere on the board
TWEETER_4: U21.10 (LINP); also elsewhere on the board
VSYS: C133.1, C135.1, C136.1, C137.1, C138.1, C139.1, C161.1, C163.1, C164.1, C165.1, C166.1, C167.1, R45.1, R55.1, U20.17 (AVCC), U20.18 (PVCC_18), U20.19 (PVCC_19), U20.31 (PVCC_31), U20.32 (PVCC_32), U21.17 (AVCC), U21.18 (PVCC_18), U21.19 (PVCC_19), U21.31 (PVCC_31), U21.32 (PVCC_32); also elsewhere on the board

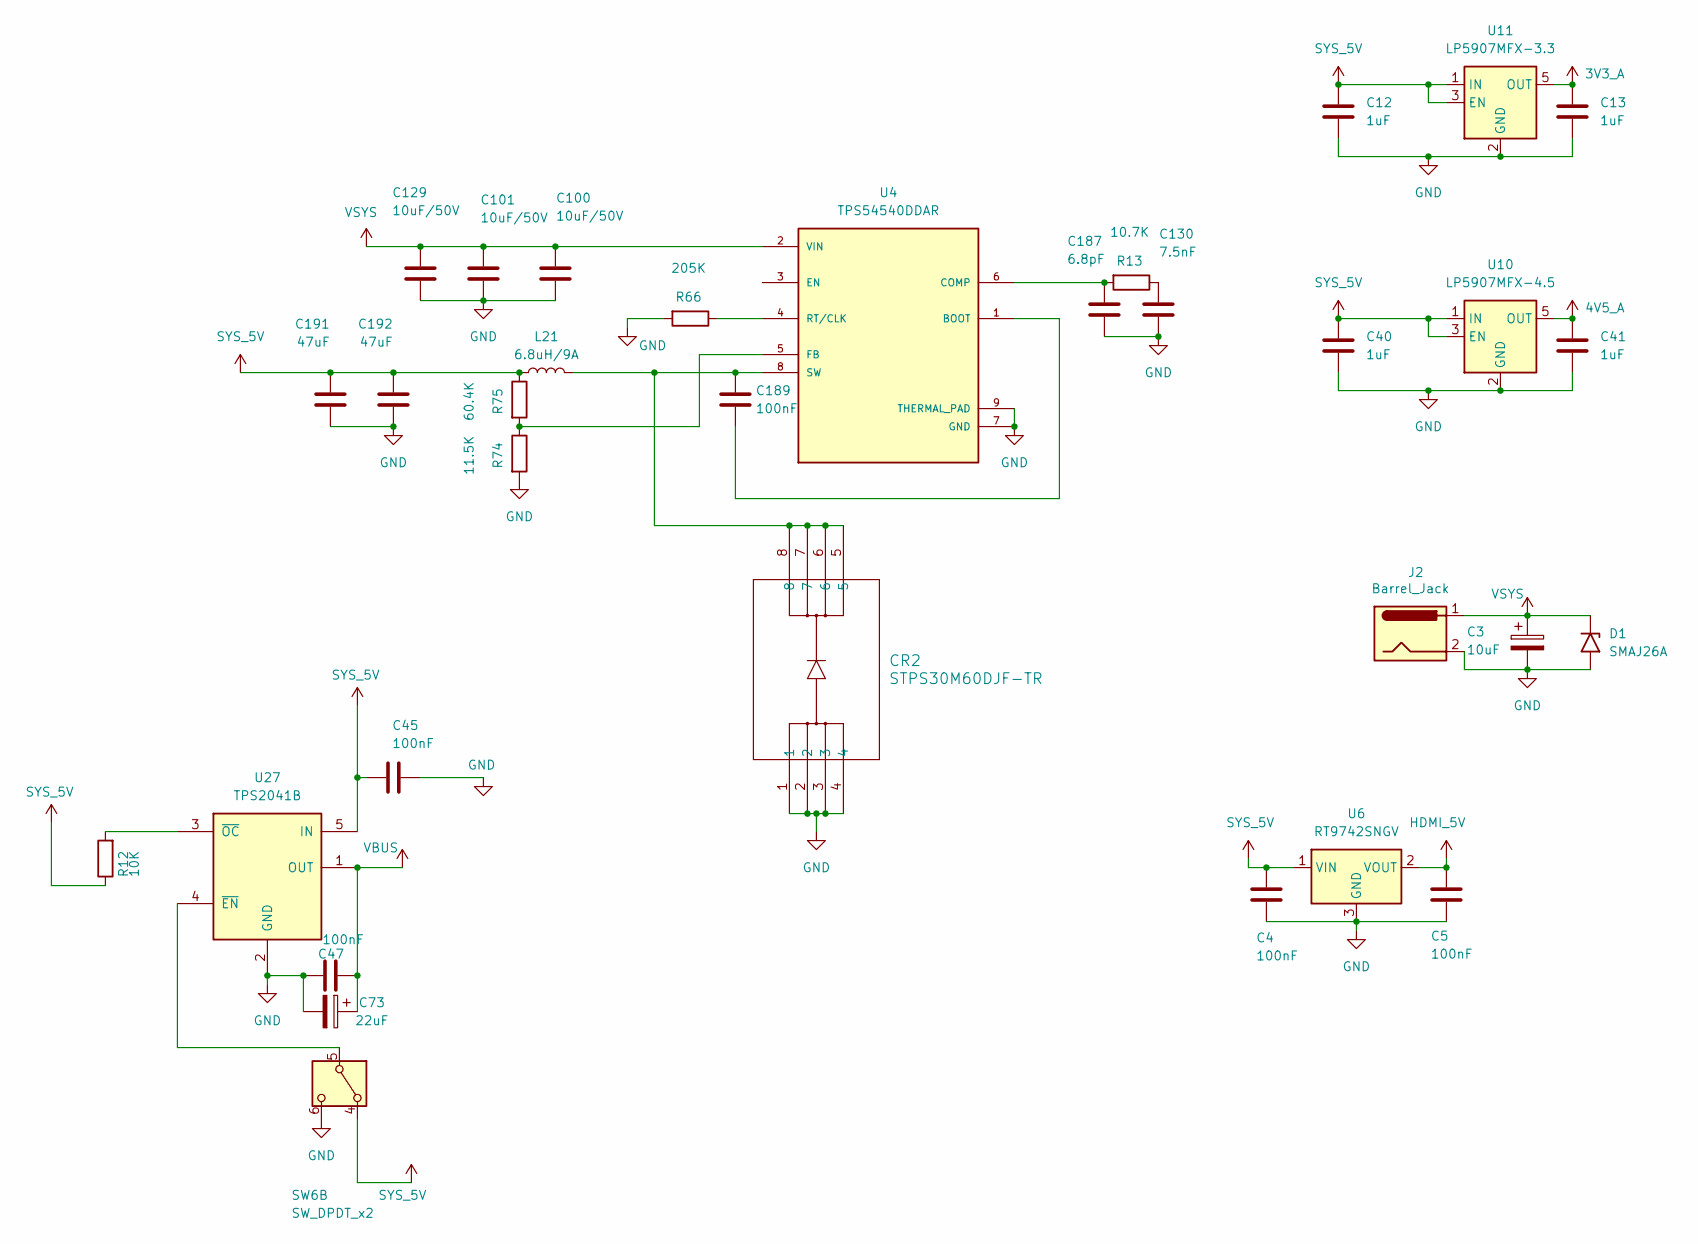
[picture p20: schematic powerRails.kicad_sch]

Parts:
C3: 10uF; CP_Elec_4x3
C4, C5, C45, C47, C189: 100nF; C_0603_1608Metric
C12, C13, C40, C41: 1uF; C_0603_1608Metric
C73: 22uF; CP_Elec_4x3
C100, C101, C129: 10uF/50V; C_1210_3225Metric
C130: 7.5nF; C_0603_1608Metric
C187: 6.8pF; C_0603_1608Metric
C191, C192: 47uF; C_1210_3225Metric
CR2: STPS30M60DJF-TR; POWERFLAT5X6_STM
D1: SMAJ26A; D_SMA
J2: Barrel_Jack; BarrelJack_SwitchcraftConxall_RAPC10U_Horizontal
L21: 6.8uH/9A; L_6.3x6.3_H3
R12: 10K; R_0603_1608Metric
R13: 10.7K; R_0603_1608Metric
R66: 205K; R_0603_1608Metric
R74: 11.5K; R_0603_1608Metric
R75: 60.4K; R_0603_1608Metric
SW6: SW_DPDT_x2; SW_DPDT_CK_JS202011JCQN
U4: TPS54540DDAR; CONV_TPS54540DDAR; PARTREV B
U6: RT9742SNGV; SOT-23-3
U10: LP5907MFX-4.5; SOT-23-5
U11: LP5907MFX-3.3; SOT-23-5
U27: TPS2041B; SOT-23-5

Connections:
3V3_A: C13.2, U11.5 (OUT); also elsewhere on the board
HDMI_5V: C5.1, U6.2 (VOUT); also elsewhere on the board
unnamed: C130.1, R13.1
unnamed: SW6.5 (B), U27.4 (~EN)
unnamed: C189.2, U4.1 (BOOT)
unnamed: C187.1, R13.2, U4.6 (COMP)
unnamed: R74.1, R75.2, U4.5 (FB)
unnamed: R66.1, U4.4 (RT/CLK)
unnamed: C189.1, CR2.5, CR2.6, CR2.7, CR2.8, L21.2, U4.8 (SW)
unnamed: R12.2, U27.3 (~OC)
VBUS: C47.2, C73.1, U27.1 (OUT); also elsewhere on the board
VSYS: C3.1, C100.1, C101.1, C129.1, D1.1 (A1), J2.1, U4.2 (VIN); also elsewhere on the board

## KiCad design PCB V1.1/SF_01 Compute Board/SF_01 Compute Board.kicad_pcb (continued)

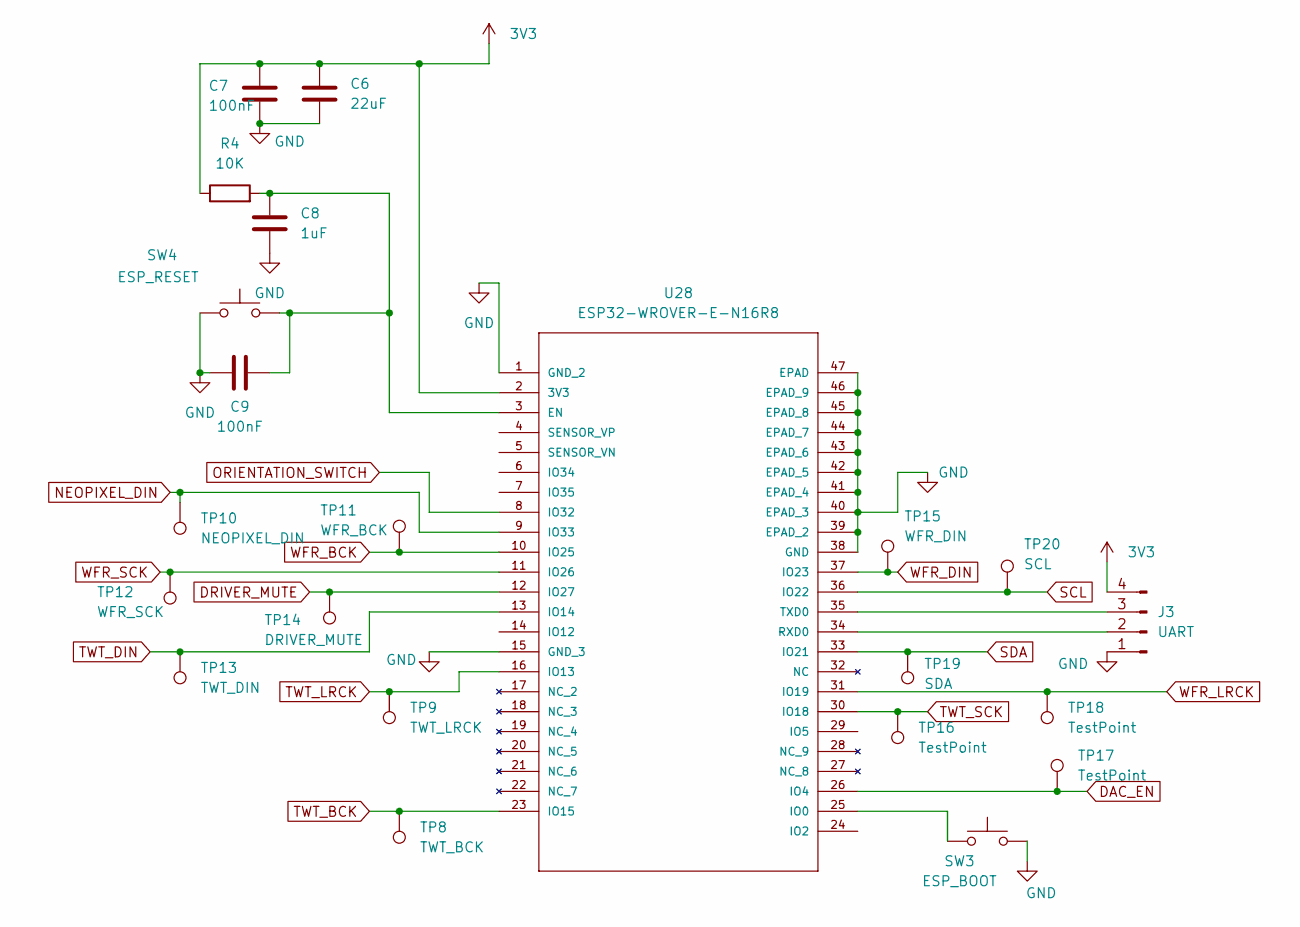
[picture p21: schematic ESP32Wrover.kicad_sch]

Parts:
C6: 22uF; C_0603_1608Metric
C7, C9: 100nF; C_0603_1608Metric
C8: 1uF; C_0603_1608Metric
J3: UART; PinHeader_1x04_P2.54mm_Vertical
R4: 10K; R_0603_1608Metric
SW3: ESP_BOOT; SW_Push_1P1T-SH_NO_CK_KMR2xxG
SW4: ESP_RESET; SW_Push_1P1T-SH_NO_CK_KMR2xxG
TP8: TWT_BCK; TestPoint_Pad_3.0x3.0mm
TP9: TWT_LRCK; TestPoint_Pad_3.0x3.0mm
TP10: NEOPIXEL_DIN; TestPoint_Pad_D2.5mm
TP11: WFR_BCK; TestPoint_Pad_3.0x3.0mm
TP12: WFR_SCK; TestPoint_Pad_3.0x3.0mm
TP13: TWT_DIN; TestPoint_Pad_3.0x3.0mm
TP14: DRIVER_MUTE; TestPoint_Pad_D2.5mm
TP15: WFR_DIN; TestPoint_Pad_3.0x3.0mm
TP16, TP17, TP18: TestPoint; TestPoint_Pad_D2.5mm
TP19: SDA; TestPoint_Pad_3.0x3.0mm
TP20: SCL; TestPoint_Pad_3.0x3.0mm
U28: ESP32-WROVER-E-N16R8; ESP32-WROVER-E_EXP; MANUFACTURER_PART_NUMBER ESP32-WROVER-E-N16R8

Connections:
3V3: C6.1, C7.1, J3.4, R4.1, U28.2 (3V3); also elsewhere on the board
DAC_EN: TP17.1 (1_1), U28.26 (IO4); also elsewhere on the board
DRIVER_MUTE: TP14.1 (1_1), U28.12 (IO27); also elsewhere on the board
NEOPIXEL_DIN: TP10.1 (1_1), U28.9 (IO33); also elsewhere on the board
unnamed: J3.2, U28.34 (RXD0)
unnamed: J3.3, U28.35 (TXD0)
unnamed: C8.2, C9.1, R4.2, SW4.2, U28.3 (EN)
unnamed: SW3.1, U28.25 (IO0)
ORIENTATION_SWITCH: U28.8 (IO32); also elsewhere on the board
SCL: TP20.1 (1_1), U28.36 (IO22); also elsewhere on the board
SDA: TP19.1 (1_1), U28.33 (IO21); also elsewhere on the board
TWT_BCK: TP8.1 (1_1), U28.23 (IO15); also elsewhere on the board
TWT_DIN: TP13.1 (1_1), U28.13 (IO14); also elsewhere on the board
TWT_LRCK: TP9.1 (1_1), U28.16 (IO13); also elsewhere on the board
TWT_SCK: TP16.1 (1_1), U28.30 (IO18); also elsewhere on the board
WFR_BCK: TP11.1 (1_1), U28.10 (IO25); also elsewhere on the board
WFR_DIN: TP15.1 (1_1), U28.37 (IO23); also elsewhere on the board
WFR_LRCK: TP18.1 (1_1), U28.31 (IO19); also elsewhere on the board
WFR_SCK: TP12.1 (1_1), U28.11 (IO26); also elsewhere on the board

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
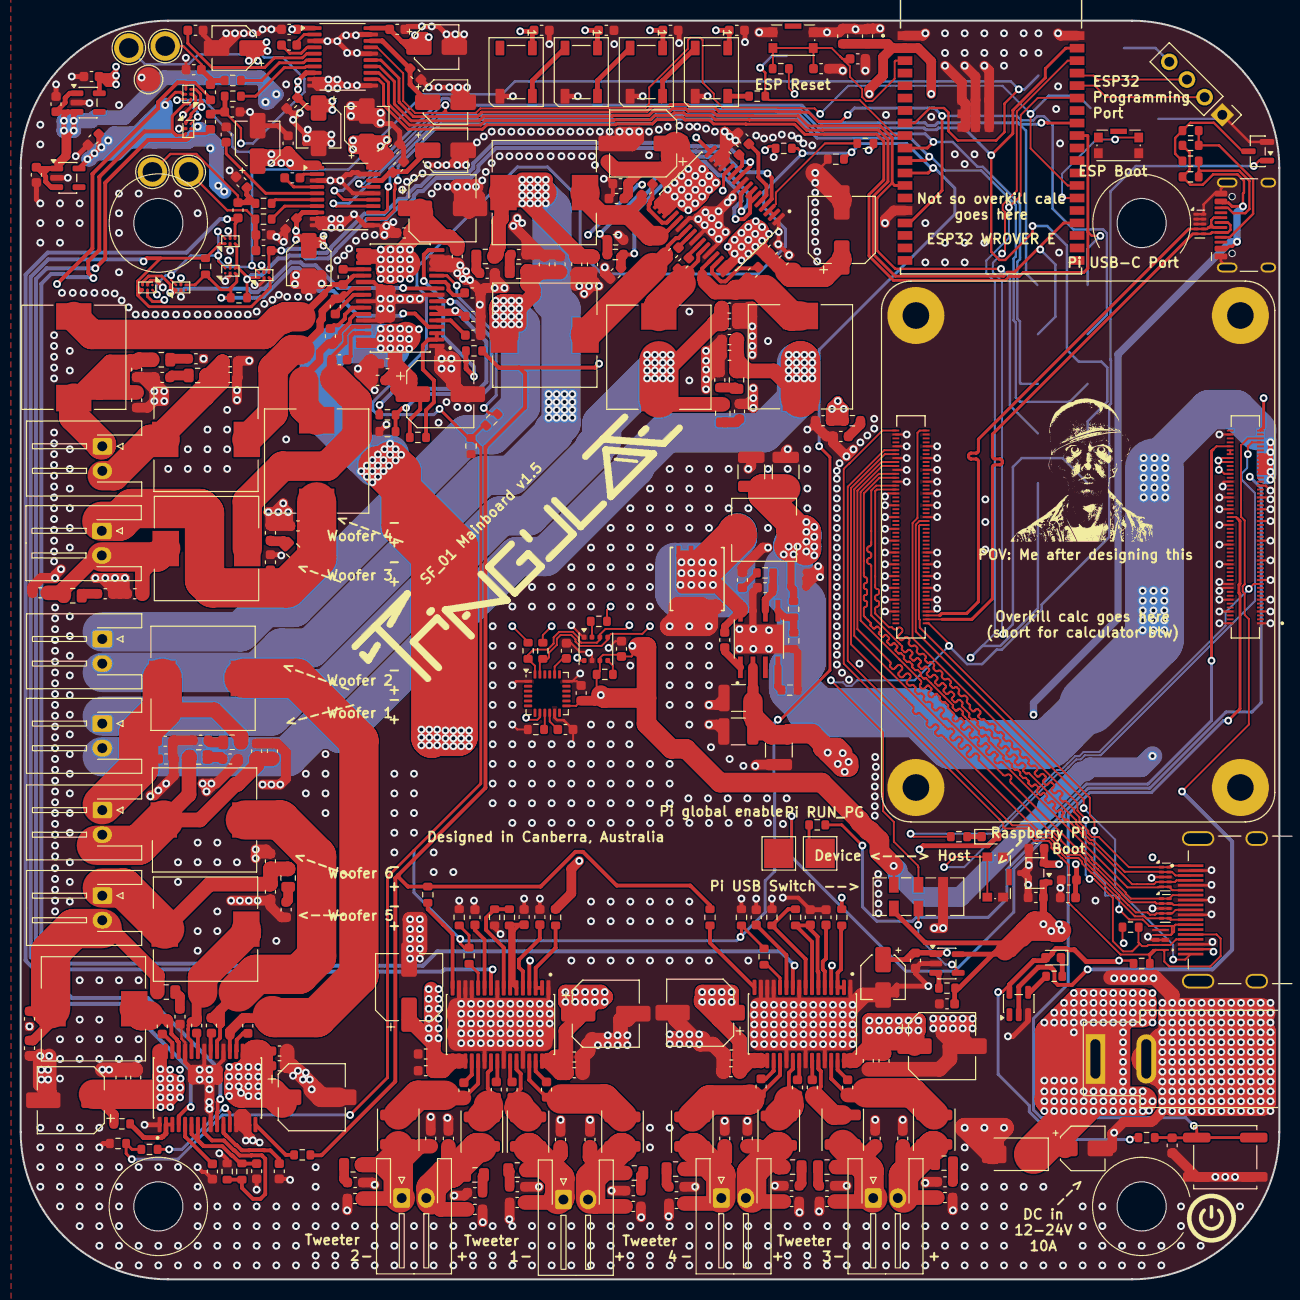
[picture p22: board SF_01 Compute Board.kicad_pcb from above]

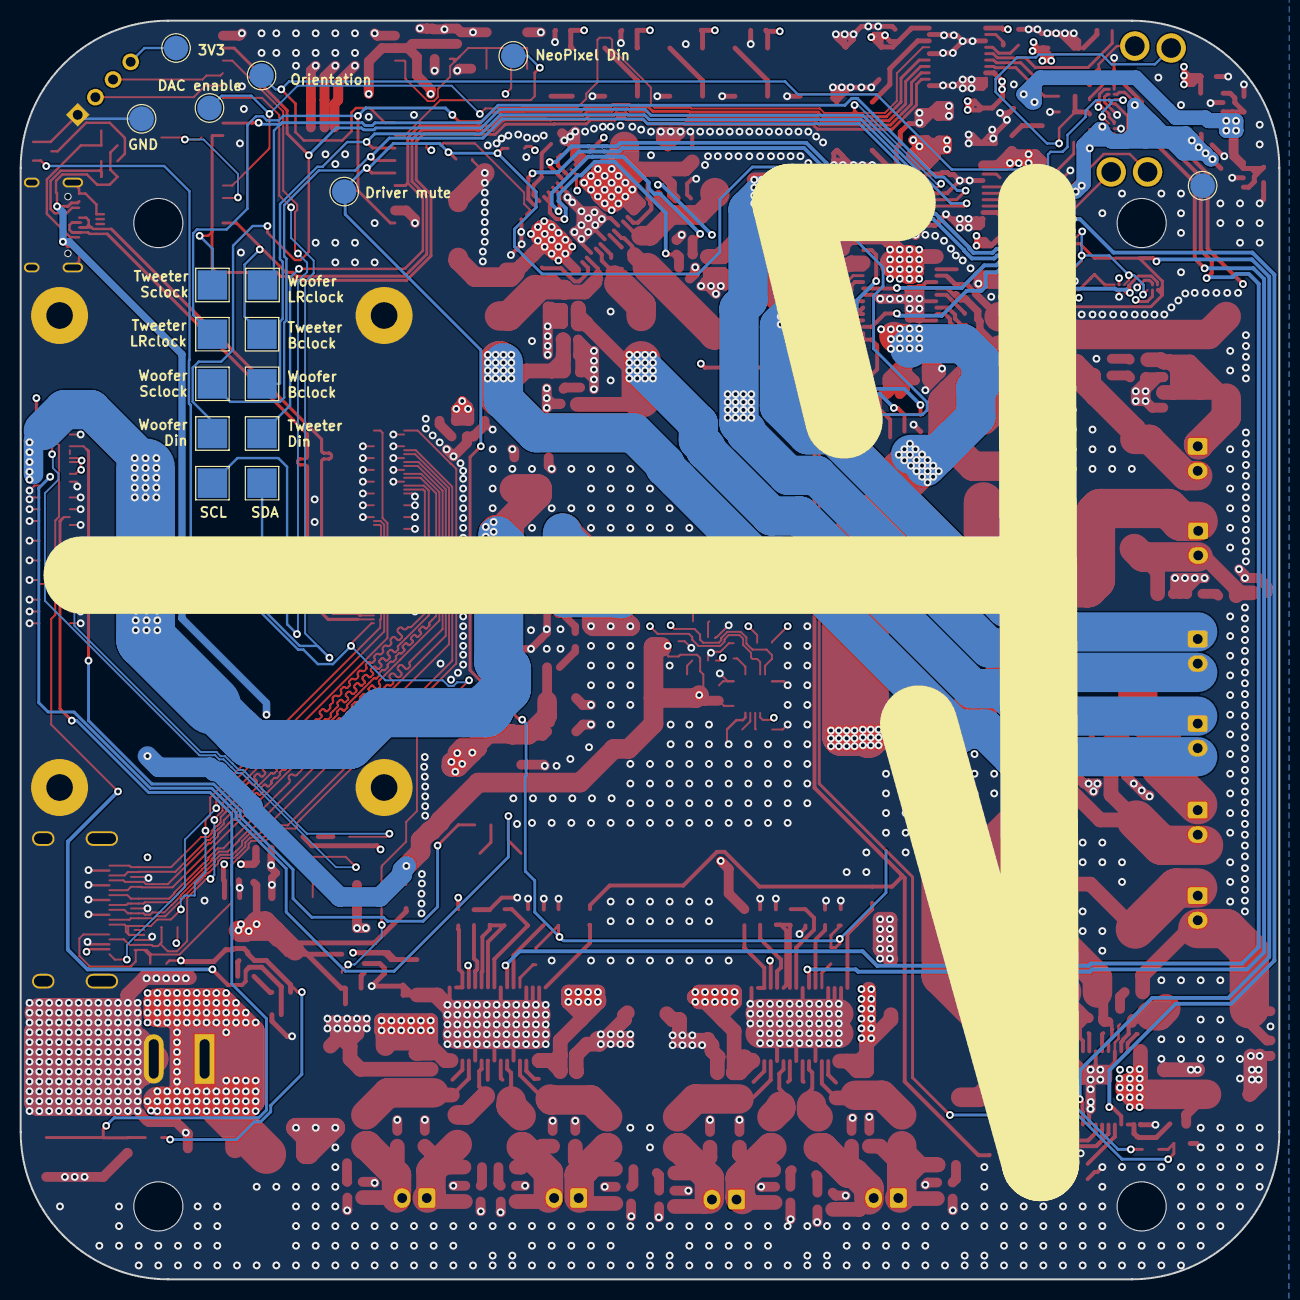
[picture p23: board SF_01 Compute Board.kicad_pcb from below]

Board: 4 copper layers, 128.0 x 128.0 mm, 367 parts (17 on the bottom side), 214 nets.

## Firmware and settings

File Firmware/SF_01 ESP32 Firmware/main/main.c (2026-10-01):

/*
 * SF_01 Speaker Frame — ESP32 audio firmware.
 *
 *   Bluetooth A2DP sink  ->  EQ  ->  LR4 crossover  ->  2x I2S  ->  2x PCM5102A
 *
 * Target: ESP32-WROVER-E-N16R8 (U28 on the SF_01 Compute Board). Bluetooth
 * Classic is required for A2DP, so this will not run on an ESP32-S3.
 */

#include "board.h"
#include "audio_out.h"
#include "bt_sink.h"
#include "ble_ctl.h"
#include "led_viz.h"
#include "dsp.h"
#include "settings.h"
#include "shell.h"

#include "freertos/FreeRTOS.h"
#include "freertos/task.h"
#include "nvs_flash.h"
#include "esp_log.h"

static const char *TAG = "sf01";

void app_main(void)
{
    /*
     * This must come first, before anything that can block.
     *
     * DRIVER_MUTE is held low by the five 100 k pull-downs on the board
     * (R20/R27/R36/R46/R56), and the amplifiers' SDZ pins are strapped to
     * FAULTZ, so from the moment PVCC rises the amps are enabled and
     * un-muted while the DACs' XSMT pin is still floating. Asserting mute
     * here closes that window as early as firmware possibly can.
     */
    audio_out_safe_state();

    esp_err_t err = nvs_flash_init();
    if (err == ESP_ERR_NVS_NO_FREE_PAGES || err == ESP_ERR_NVS_NEW_VERSION_FOUND) {
        ESP_ERROR_CHECK(nvs_flash_erase());
        err = nvs_flash_init();
    }
    ESP_ERROR_CHECK(err);

    dsp_config_t cfg;
    settings_load(&cfg);

    /* Starts both I2S channels feeding silence and waits for the PCM5102A
     * PLLs to lock. Output stays muted until a stream actually starts. */
    ESP_ERROR_CHECK(audio_out_init(44100));
    dsp_set_config(&cfg);

    /* Queued, so it rings while the Bluetooth stack comes up rather than
     * delaying boot. */
    audio_out_play_chime(CHIME_STARTUP);

    ESP_ERROR_CHECK(bt_sink_start(CONFIG_SF01_BT_DEVICE_NAME));
    ESP_ERROR_CHECK(ble_ctl_start());
    ESP_ERROR_CHECK(led_viz_start());

    shell_start();

    ESP_LOGI(TAG, "ready — pair with \"%s\", type 'help' for tuning commands",
             CONFIG_SF01_BT_DEVICE_NAME);
}

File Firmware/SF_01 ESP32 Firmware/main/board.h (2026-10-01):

/*
 * board.h — SF_01 Compute Board pin map.
 *
 * Pin numbers are taken directly from the KiCad netlist of
 * "PCB V1.1/SF_01 Compute Board", module U28 (ESP32-WROVER-E-N16R8).
 * The bring-up devboard uses the same GPIO numbers, wired to the
 * matching test points, so one binary runs on both.
 *
 *   signal        GPIO   U28 pin   test point
 *   WFR_BCK        25      10        TP11
 *   WFR_LRCK       19      31        TP18
 *   WFR_DIN        23      37        TP15
 *   WFR_SCK        26      11        TP12
 *   TWT_BCK        15      23        TP8
 *   TWT_LRCK       13      16        TP9
 *   TWT_DIN        14      13        TP13
 *   TWT_SCK        18      30        TP16
 *   DAC_EN          4      26        TP17
 *   DRIVER_MUTE    27      12        TP14
 */
#pragma once

#include "driver/gpio.h"

/* Woofer / mid-bass DAC (U14) */
#define PIN_WFR_BCK      GPIO_NUM_25
#define PIN_WFR_LRCK     GPIO_NUM_19
#define PIN_WFR_DIN      GPIO_NUM_23
#define PIN_WFR_SCK      GPIO_NUM_26

/* Tweeter DAC (U5) */
#define PIN_TWT_BCK      GPIO_NUM_15
#define PIN_TWT_LRCK     GPIO_NUM_13
#define PIN_TWT_DIN      GPIO_NUM_14
#define PIN_TWT_SCK      GPIO_NUM_18

/*
 * DAC_EN drives XSMT (pin 17) on BOTH PCM5102As in parallel.
 * PCM5102A: XSMT low = soft mute, high = soft un-mute.
 */
#define PIN_DAC_EN       GPIO_NUM_4
#define DAC_UNMUTED      1
#define DAC_MUTED        0

/*
 * DRIVER_MUTE drives MUTE (pin 12) on all five amplifiers
 * (U17/U18/U19 TPA3116D2, U20/U21 TPA3130D2) through the 100 k
 * series resistors TI requires when the driver slews faster than
 * 10 V/ms (SLOS708G abs-max table, note 2).
 * TPA31xx: MUTE high = outputs Hi-Z, low = outputs enabled.
 */
#define PIN_DRIVER_MUTE  GPIO_NUM_27
#define AMPS_MUTED       1
#define AMPS_UNMUTED     0

/* I2C sensors (BME680, MPU-6050) — not used by the audio path yet. */
#define PIN_I2C_SDA      GPIO_NUM_21
#define PIN_I2C_SCL      GPIO_NUM_22

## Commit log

2026-06-24 Add devlog entry for digital picture frame design
    Documented the design process for a digital picture frame with integrated audio system, detailing component selection and design challenges.
2026-06-24 Update JOURNAL.md with devlog 3
    Added details about the design and assembly of the digital picture frame, including speaker system specifications and 3D printing considerations.
2026-06-25 Designed the PCB Schematic
    [LM1085ISX-5.0_NOPB.step, SF_01 Compute Board.kicad_pcb, SF_01 Compute Board.kicad_sch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]
2026-06-25 Changed Audio Multiplexer Circuit, Routed more
    [JLCPCB.kicad_pcb, JLCPCB.kicad_sch, SF_01 Compute Board.kicad_pcb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]
2026-06-26 Added USB Host control, Routed 1st amplifier
    [JLCPCB.kicad_pcb, JLCPCB.kicad_sch, LM1085ISX-5.0_NOPB.step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]
2026-06-26 Routed 2nd Subwoofer Amplifier
    [SF_01 Compute Board.kicad_pcb]
2026-06-26 Finished Routing 2nd Amplifier, started routing 3rd
    [SF_01 Compute Board.kicad_pcb, SF_01 Compute Board.kicad_sch, audioCircuit.kicad_sch]
2026-06-26 Enhance README with detailed project description
    Expanded the README with detailed descriptions of the SF_01 digital picture frame, including its features, layout, images, and schematics.
2026-06-26 Added Renders of Enclosure
2026-06-27 Finished the PCB!
2026-06-28 Finishing touches to PCB, add enclosure CAD files
    [Bass-Midwoofers.step, JS202011JCQN 3D Model STEP 1.STEP, LG 24U411A-B Monitor.step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]
2026-06-28 Update README with PCB layout and 3D model images
    Added PCB layout images and sections to README.
2026-06-28 Added PCB Version 1.1 with ESP32 WROVER E
    [ESP32-WROVER-B__16MB_.step, ESP32-WROVER-E-N16R8.step, ESP32Wrover.kicad_sch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]
2026-06-28 Revise circuit and PCB layout images in README
    Updated circuit images and PCB layout in README.
2026-06-28 Add Bill Of Materials section to README
    Added Bill Of Materials section with detailed component list including part numbers, manufacturers, quantities, prices, and descriptions.
2026-06-28 Added BoM and Production Files
    [BoM.csv, SF_01 Compute Board_BoM.csv, SF_01_Compute_Board_bom.csv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]
2026-06-28 Document design process for SF_01 digital frame
    Added detailed devlogs documenting the design and assembly process of the SF_01 digital picture frame, including subwoofer box design, splitting frame for 3D printing, mounting options, and PCB schem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
2026-06-28 Add multiple devlogs for SF_01 project
    Updated JOURNAL.md to include additional devlogs detailing the design and assembly of a digital picture frame with integrated audio system, subwoofer box design, and PCB schematic development.
2026-06-28 Add new devlogs for SF_01 project updates
    Updated the JOURNAL.md file to include new devlogs detailing the design and development process for the SF_01 digital picture frame and audio system.
2026-06-28 Consolidate devlogs into JOURNAL.md
    Merged multiple devlogs into a single document, preserving detailed descriptions of the design and development process for the SF_01 digital picture frame and audio system.
2026-07-27 Fixed minor routing issues
    [ESP32Wrover.kicad_sch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]
2026-08-03 Fixed major issues with power rails
    [ESP32Wrover.kicad_sch, SF_01 Compute Board.kicad_pcb, SF_01 Compute Board.kicad_sch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]
2026-08-03 Fixed all PCB blocking issues, updated BOM
    [BoM.csv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]
2026-08-04 Update README.md with new PCB images
2026-08-06 Finished final version of PCB and BOM
    [BoM-LCSC-order.csv, BoM.csv, ESP32Wrover.kicad_sch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]
2026-08-06 Updated BOM to add in-stock parts
    [BoM-LCSC-order.csv, BoM.csv]
2026-10-01 ESP32 firmware, iPhone Control App, Heatsink
    [SF_01 Heatsink.step, partitions.csv]
2026-10-02 Added Devlog 24 and 25, the final assembly devlogs
2026-10-11 Redesign the iPhone control app: tab bar, system sliders, product render
    - Add a bottom tab bar with Speaker and Equaliser tabs; the equaliser is
    no longer a page pushed from the main list.
    - Replace the equaliser's custom knobs with the system Slider: one gain
    slider per band, plus Frequency / Q / Gain for the selected band.
    - Put a render of the SF_01 (cropped from Images/Render 1.png) at the top
    of the main page, with the connection state and sample rate as badges.
    - Give every settings row an icon on a shared column, confirm before
    resetting to defaults, and acknowledge a save with a tick and a haptic.
    - Show a "Speaker not connected" state on the Equaliser tab instead of
    dead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
2026-10-11 Add over-the-air firmware updates over Bluetooth LE
    The speaker can now be updated from the Mac without a USB cable:
    idf.py build && ../sf01-ota/push.sh
    Firmware
    - fw_update.c: receives an image over three new GATT characteristics on
    the control service, under a sliding window acknowledged by bytes
    written to flash, and writes it to the idle app slot.
    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
2026-10-11 Revise image sections in README
    Updated section titles and added images for built prototype and 3D models.

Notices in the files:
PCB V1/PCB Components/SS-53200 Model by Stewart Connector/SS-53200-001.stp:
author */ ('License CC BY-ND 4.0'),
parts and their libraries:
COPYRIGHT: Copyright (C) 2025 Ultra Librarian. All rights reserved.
